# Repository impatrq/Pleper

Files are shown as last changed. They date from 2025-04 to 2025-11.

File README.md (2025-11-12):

<div align="center">

# Proyecto PLEPER
## Placa de Energía Piezoeléctrica Renovable 
<div align="center">
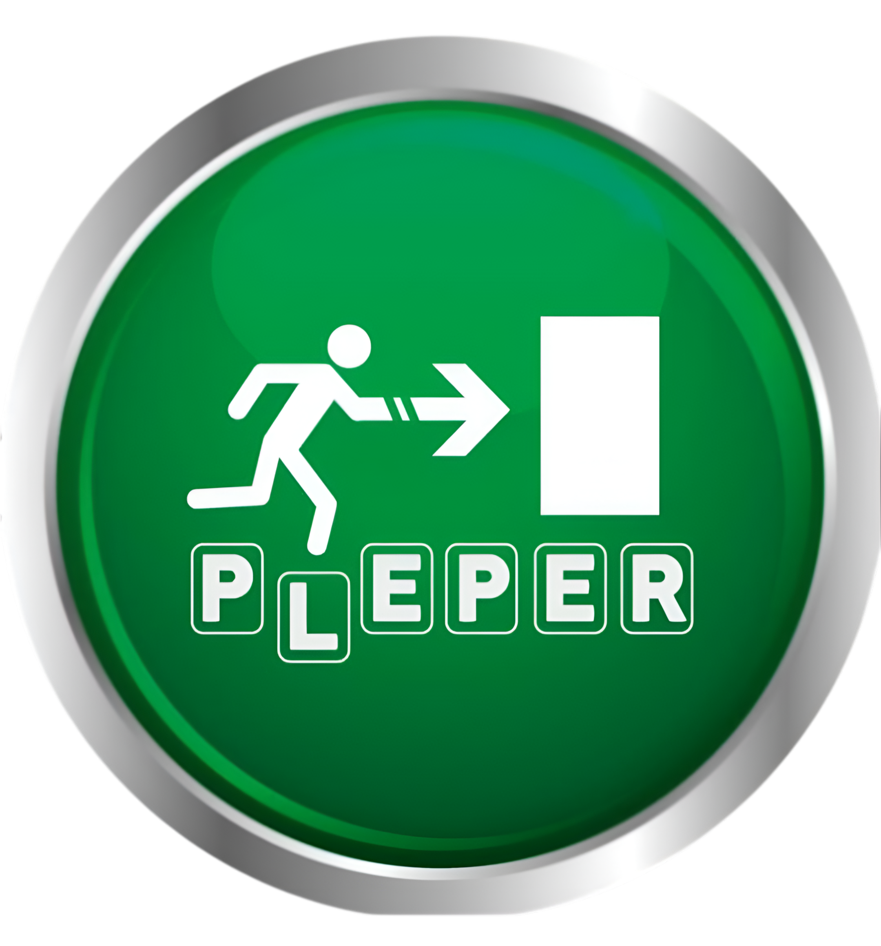
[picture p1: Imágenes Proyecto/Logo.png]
Logo Proyecto Pleper
  
  </div>

|  |  | |
|---|---|---|
|[Página Web](https://pleper-impa.github.io/web/index.html)|pleper.infoimpa@gmail.com|[@pleper_25](https://www.instagram.com/pleper_25/?igsh=Y2xkMGg4Z2V1NHdl#)|

</div>

## ⚡ Energía en cada paso.

&nbsp;&nbsp;&nbsp;&nbsp;&nbsp;&nbsp;PLEPER es un sistema que busca aprovechar la energía mecánica generada por el paso de las personas sobre una baldosa piezoeléctrica para convertirla en energía eléctrica. Este sistema se destina a la alimentación de una luz de emergencia LED, enfocándose en su aplicación en los subtes de la Ciudad. Para optimizar su funcionamiento, el sistema cuenta con un microcontrolador que supervisa la energía generada y la muestra en una pantalla LCD, brindando información en tiempo real sobre su rendimiento.

&nbsp;&nbsp;&nbsp;&nbsp;&nbsp;&nbsp;Este proyecto busca demostrar la viabilidad de la energía piezoeléctrica, aunque el prototipo inicial se centra en aplicaciones pequeñas, la tecnología podría escalarse para aprovechar el tráfico peatonal y vehicular en entornos urbanos.

## 💡 ¿Qué aporta a la sociedad?
&nbsp;&nbsp;&nbsp;&nbsp;&nbsp;&nbsp;El mayor impacto que busca generar nuestro proyecto es el de incorporar, de manera inocua, métodos de generación de energía renovables al día a día de las personas, interactúando con la generación de energía y siendo a su vez más conscientes de las problematicas ambientales que conllevan los métodos tradiconales de generación de energía. <br>

## 🔧 Características Principales

- **Generación de Energía Limpia**: Convierte la energía mecánica del movimiento en electricidad utilizable.
- **Aplicaciones Versátiles**: Puede integrarse en pisos de estaciones de tren, centros comerciales, aeropuertos y rutas de alta circulación.
- **Bajo Impacto Ambiental**: No requiere combustibles fósiles.
- **Escalabilidad**: Diseño adaptable para aumentar la eficiencia con múltiples módulos piezoeléctricos en serie o paralelo.

## 🏙️ Aplicaciones

- **Espacios públicos**: Calles y veredas con alto tráfico peatonal.
- **Transporte**: Integración en rutas para aprovechar la presión de los vehículos.
- **Edificios Inteligentes**: Estaciones de transporte y centros comerciales.
- **Eventos Masivos**: Estadios y conciertos donde miles de personas generan energía con sus movimientos.

## 🛠️ Tecnología Utilizada

- **Componentes Principales**:
  - Sensor piezoeléctrico
  - Circuito rectificador
  - Almacenamiento en condensadores
  - Microcontrolador para medición de energía generada
  
- **Software**:
  - Diseño de placa en AutoCad
  - Simulaciones en software de circuitos

## Integrantes:
<div align="center">
  Logo Proyecto Pleper
</div>

### Victoria Josefina Baza

<a href="https://mail.google.com/mail/?view=cm&to=victoriajosefinabaza@gmail.com" target="_blank">
  
</a>
<a href="https://www.linkedin.com/in/victoriajbaza/">
  
</a>
<a href="https://github.com/VickyyyBaza">
  
</a>
<a href="https://www.instagram.com/lavicky_victoria/">
  
</a>

<br><br>

### Mauricio Blasco
<a href="https://mail.google.com/mail/?view=cm&to=sirmauriciob@gmail.com" target="_blank">
  
</a>
<a href="https://www.linkedin.com/in/mauriciobl/">
  
</a>
<a href="https://github.com/MauricioBlasco">
  
</a>
<a href="https://www.instagram.com/maauricio.bl/">
  
</a>

<br><br>

### Víctor Raúl Broncano Ramos
<a href="https://mail.google.com/mail/?view=cm&to=raul455896@gmail.com" target="_blank">
  
</a>
<a href="https://www.linkedin.com/in/raul-broncano-3734a0357/">
  
</a>
<a href="https://www.instagram.com/raul_broncano/">
  
</a>

<br><br>

### Ignacio García Louzan
<a href="https://mail.google.com/mail/?view=cm&to=nachogarcialouzan@gmail.com" target="_blank">
  
</a>
<a href="https://www.linkedin.com/in/ignacio-garc%C3%ADa-louzan/">
  
</a>
<a href="https://github.com/iglouzan">
  
</a>
<a href="https://www.instagram.com/ignacio_1907/">
  
</a>
<br><br>

### Isidro Joaquín Stabile

<a href="https://mail.google.com/mail/?view=cm&to=isidrost@hotmail.com" target="_blank">
  
</a>
<a href="https://www.linkedin.com/in/isidro-stabile-4104a0357/">
  
</a>
<a href="https://github.com/Isidrost">
  
</a>

<br><br>
### Santiago Alejandro Tejeda
<a href="https://mail.google.com/mail/?view=cm&to=santiagotejeda36@gmail.com" target="_blank">
  
</a>
<a href="https://www.linkedin.com/in/santiago-tejeda/">
  
</a>
<a href="https://github.com/santiagoatejeda">
  
</a>
<a href="https://www.instagram.com/santiago.teje/">
  
</a>

<br><br>

## Contactanos

### Instagram: [@pleper_25](https://www.instagram.com/pleper_25/)

### Pagina web: [Visitanos!](https://pleper-impa.github.io/web/index.html)

### Mail: pleper.infoimpa@gmail.com

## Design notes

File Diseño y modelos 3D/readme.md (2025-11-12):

# Carpeta: AutoCAD

> Planos y diseños del proyecto **PLEPER 2025_721C**  
> Realizados en **AutoCAD** para el modelado y la disposición del sistema piezoeléctrico.

---

## Descripción
Aquí se desarrollan los **planos 2D y modelos 3D** del prototipo:  
- Distribución de sensores piezoeléctricos   
- Soporte mecánico y base de acrílico 
- Cables, conexiones y espacio para batería   

---

## Herramientas utilizadas
- AutoCAD 2025  
- FreeCAD (para pruebas de exportación STEP)

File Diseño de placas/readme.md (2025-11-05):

# Carpeta: Diseño de Placas

> Módulos electrónicos del proyecto

---

## Contenido
- `Banco de capacitores/` → Conjunto de capacitores conectados en paralelo para almacenamiento de energía.  
- `Diseño 3D/` → Modelado tridimensional del banco de capacitores y disposición general.  
- `Placa de bombeo capacitivo/` → Etapa encargada de incrementar el voltaje captado por los sensores.  
- `Placa rectificadora/` → Conversión de corriente alterna a continua para carga estable en la batería.

---

## Descripción
En esta carpeta se encuentran los **diseños electrónicos** fundamentales del sistema:  
- Implementación de **etapas de rectificación y bombeo capacitivo**.  
- Diseño del **banco de capacitores** encargado de almacenar la energía piezoeléctrica.  
- Integración entre módulos para alimentar el sistema de medición y visualización.  

---

## Herramientas utilizadas
- **KiCad** para diseño de PCBs.  
- **PDFGear** para visualización e impresión.
---

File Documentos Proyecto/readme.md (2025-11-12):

# Carpeta: Documentos del Proyecto

> Archivos y registros del proyecto  
> Incluye documentación técnica, bitácoras, materiales de referencia y presentaciones finales.

---

## Contenido
- `Anteproyecto, Objetivos e Historias de Usuario` → Primeros documentos técnicos que buscaban guíar hacía donde iría el desarrollo del proyecto.  
- `Bitácora y Carpeta de Campo/` → Registro cronológico del avance mensual y tareas realizadas.  
- `CV Alumnos/` → Curriculum de los integrantes del proyecto.  
- `Carpeta Técnica y Manual de Usuario/` → Documentación técnica explicativa sobre el proyecto.  
- `Compras/` → Comprobantes, presupuestos y control de materiales adquiridos.    
- `Material/` → Referencias teóricas, papers y fuentes consultadas.  
- `Video de presentación/` → Guion, recursos y edición del video final del proyecto.  

---

## Documentos principales
- **Anteproyecto PLEPER.docx** → Documento base del proyecto: idea, objetivos y justificación.  
- **Carpeta Técnica.docx** → Desarrollo técnico, esquemas, cálculos y simulaciones.  
- **Manual de Usuario.docx** → Instrucciones de uso del prototipo, instalación y seguridad.  
---

## Herramientas utilizadas
- Microsoft Word y PowerPoint  
- Canva (diseño visual del material)  
- Google Drive para control de versiones

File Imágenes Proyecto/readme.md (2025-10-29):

# Carpeta: Imágenes del Proyecto

> Registro visual del proyecto **PLEPER 2025_721C**  
> Fotografías, capturas y material gráfico que documenta cada etapa de desarrollo.

---

## Contenido
- `Desarrollo/` → Imágenes del prototipo en construcción y pruebas de funcionamiento.  
- `Referencias/` → Material visual de apoyo, esquemas base y ejemplos consultados.  
- `Simulación de Circuitos/` → Capturas de simulaciones y resultados eléctricos.  
- `Instagram/` → Contenido audiovisual editado para difusión del proyecto.  

---

## Descripción
Esta carpeta concentra todo el **material gráfico y visual** del proyecto, utilizado tanto para documentación técnica como para difusión.  
Incluye:
- Fotos del armado y conexión de placas 
- Resultados de simulaciones y ensayos eléctricos 
- Imágenes promocionales y contenido para redes  

---

## Herramientas utilizadas
- **Canva** → Edición de imágenes y videos.  
- **Proteus** → Capturas de simulaciones de circuitos.

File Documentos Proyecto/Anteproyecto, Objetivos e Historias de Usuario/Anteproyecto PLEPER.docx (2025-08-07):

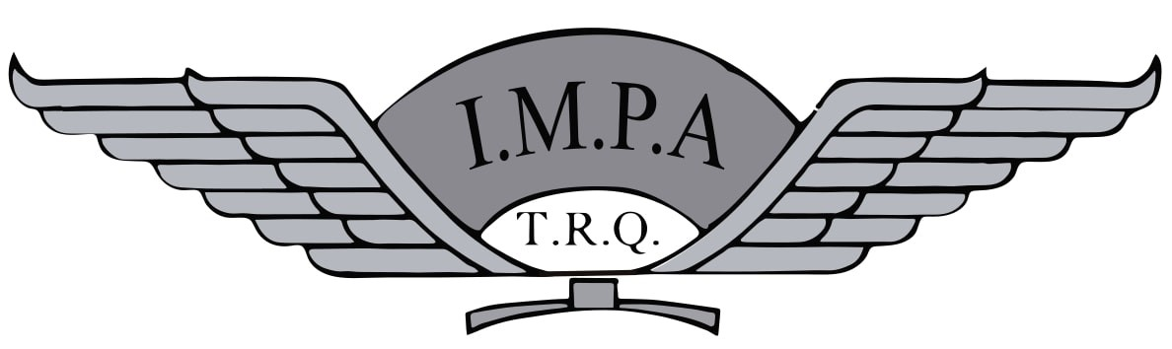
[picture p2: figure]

Escuela de Educación Secundaria Técnica Nº 7

«Taller Regional Quilmes»

Prácticas Profesionalizantes: Departamento de Aviónica

# Presentación de anteproyecto

7mo 1era AVC

“PL.E.PE.R”

Placa de Energía Piezoeléctrica Renovable

Integrantes del grupo:

BAZA, Victoria Josefina

BLASCO, Mauricio

BRONCANO RAMOS, Víctor Raúl

GARCÍA LOUZAN, Ignacio

STABILE, Isidro Joaquín

TEJEDA, Santiago Alejandro

Título del proyecto:

El nombre elegido para el proyecto fue el de Placa de Energía Piezoeléctrica Renovable por ser una descripción de lo que queremos lograr desarrollar. Abreviándolo se identifica como PL.E.PE.R

Resumen:

El proyecto que se propone busca presentar un método innovador de generación de energía eléctrica que aprovecha el movimiento humano como fuente principal de energía, utilizando la tecnología piezoeléctrica, en contextos de aplicación urbanos, como lo es una estación de subte. Se apunta a demostrar su funcionabilidad en los sistemas de iluminación de emergencia, pretendiendo poder funcionar en contexto de pérdidas de energía, solo con las pisadas de las personas.

La piezoelectricidad, que convierte la energía mecánica en eléctrica, ofrece un complemento limpio, aplicándose en entornos donde el movimiento de las personas es constante. Este enfoque no solo reduciría la dependencia de fuentes de energía no renovables, sino que también promueve la integración de tecnologías sustentables en nuestra vida diaria, sin afectarla necesariamente, de manera que seamos más conscientes como habitantes al problema ambiental que nos enfrentamos.

Introducción:

La creciente preocupación por el cambio climático y el agotamiento de los recursos fósiles ha impulsado la búsqueda de fuentes de energía más limpias y sostenibles. Las energías renovables, como la solar, eólica e hidroeléctrica, han emergido como alternativas viables, ofreciendo beneficios ambientales al reducir las emisiones de gases de efecto invernadero y mitigar la contaminación atmosférica. Sin embargo, estas no proporcionan energía constante debido a su dependencia en las condiciones climáticas, demostrando la necesidad de diversificar las fuentes y mejorar los sistemas existentes.

Sin embargo, el movimiento humano, abundante en ciudades densamente pobladas, posee una cantidad abundante de energía residual que se puede aprovechar. Para este aprovechamiento se deben desarrollar tecnologías de recolección capaces de recopilar el potencial del movimiento humano y una de estas tecnologías es el Piezoeléctrico. Ésta es una propiedad de ciertos materiales, como cristales y cerámicos, que les permite generar electricidad al ser sometidos a presión mecánica mediante las vibraciones. Aplicaciones de la piezoelectricidad van desde encendedores de cocina hasta su uso en la medicina, como en transductores ultrasónicos (1).

La integración de tecnologías piezoeléctricas en entornos urbanos, como pavimentos que capturan la energía del tránsito peatonal, ofrece oportunidades para generar electricidad de manera sustentable. Diversos proyectos han sido llevados a cabo en distintas ciudades mundiales del primer mundo, demostrando el potencial de la piezoelectricidad en la iluminación urbana, transformando el movimiento humano en energía eléctrica y contribuyendo a la eficiencia energética de las ciudades. En Londres, en el centro comercial Westfield Stratford City, se han instalado unas 20 baldosas piezoeléctricas, siendo capaces estas de encender la mitad de la iluminación exterior del centro comercial (2). De manera similar, en Tokio, la estación de tren de Shibuya ha incorporado paneles piezoeléctricos en sus pisos, generando electricidad a partir de las pisadas de los pasajeros para alimentar los molinetes y hasta algunas pantallas LED (3).

Estas iniciativas demuestran el potencial de la piezoelectricidad para transformar el movimiento cotidiano en una fuente de energía renovable, contribuyendo a la eficiencia energética y a la sostenibilidad de las ciudades modernas. Por eso apuntamos a desarrollar esta energía y en su proceso generar concientización colectiva en una sociedad que debe proyectarse hacia un futuro más limpio, caracterizado por estas innovaciones sustentables y limpias.

El proyecto consiste en desarrollar una placa que pueda generar energía eléctrica mediante las pisadas que se ejerzan sobre esta, pensada su aplicación en entornos donde haya mucho movimiento de personas, como lo sería una estación de subte. El fin de esta placa es el de poder alimentar la batería asociada a las luces de emergencia de salida LED, las cuales se les estima una duración de emergencia de aproximadamente 3hs en caso de corte de luz, de tal manera que, aunque se corte el suministro eléctrico, mediante la piezoelectricidad, se pueda alimentar el sistema de emergencia.

Si bien el proyecto apuntaría a desarrollar una placa funcional, nosotros desarrollaremos un prototipo capaz de mostrar cuanta energía cargada posee y que se pueda probar en condiciones controladas, para así demostrar su funcionalidad. Para lograr diseñar el prototipo, se deberá desarrollar tanto la placa, es decir, todo lo que sería nuestro hardware, como los componentes eléctricos necesarios.

Descripción del funcionamiento:

El sistema comenzará con la captación de energía mecánica a través de los piezoeléctricos, los cuales estarán dispuestos en un conexionado en paralelo sobre una placa de 30 cm x 30 cm. La disposición uniforme de los piezoeléctricos permitirá distribuir las fuerzas aplicadas de manera equitativa, maximizando la eficiencia de conversión energética.

Los piezoeléctricos generan una señal de corriente alterna (CA) en respuesta a la presión ejercida sobre la placa. Para poder almacenar esta energía, es necesario rectificar la señal y convertirla en corriente continua (CC), entonces se empleará un puente de diodos que actuará como rectificador de onda completa, asegurando una conversión eficiente y minimizando la pérdida de energía. A la salida del rectificador, la señal aún puede presentar ondulaciones o ruido, por lo que se añadirá un capacitor de filtrado. Este capacitor suavizará la señal, entregando una corriente continua más estable que podrá ser utilizada en las siguientes etapas del sistema.

Dado que la corriente generada por los piezoeléctricos es relativamente baja e inconsistente, se utilizará un convertidor reductor (buck). Este circuito permitirá disminuir el voltaje (el cual es alto en picos) y a la vez aumentar la corriente, hasta un nivel adecuado para cargar la batería, pasando antes por una etapa de regulación la cual asegurará que la energía entregada a la batería sea de manera constante, garantizando una eficiencia óptima en el proceso de almacenamiento de energía.

El sistema contará con un microcontrolador, característica clave del prototipo, que tendrá varias funciones importantes a la hora de demostrar el correcto funcionamiento, siendo ellas:

Monitorear la energía generada; mediante un sensor de voltaje, el microcontrolador medirá la cantidad de energía almacenada en la batería y la mostrará en un display LCD. Esto permitirá visualizar en tiempo real el desempeño del sistema.

Demostrar el funcionamiento; encargándose de activar un conjunto de luces LED alimentadas por la batería. Estas luces encenderán cuando la energía acumulada alcance un umbral mínimo, evidenciando de manera práctica el aprovechamiento de la energía piezoeléctrica.

El fin del prototipo es el de ser sencillo en cuanto a la interacción con la persona que lo utilice, siendo el único requisito el de ejercer presión sobre la placa para activar la generación de energía. La batería almacenará la energía hasta que se necesite, y el usuario podrá visualizar la cantidad de energía disponible mediante el display. En caso de que la batería tenga suficiente carga, las luces LED se encenderán automáticamente, mostrando así el correcto funcionamiento del sistema.

Análisis de factibilidad:

Para lograr lo que proponemos se debe no solo desarrollar un prototipo, sino además poseer una capacidad de análisis y entendimiento sobre la generación piezoeléctrica y el origen de este efecto, conocimientos que iremos desarrollando a lo largo del desarrollo del prototipo, enfrentando las problemáticas que se nos presenten consultando e investigando.

Para poder definir bien cada parte que conformará este proyecto nos hemos basado en el diagrama en bloques presentado, el cual busca separar cada etapa y poder diferenciar para así llevar paso por paso cada tarea correspondiente.

Victoria Josefina Baza: Organización general del proyecto, recopilación y análisis de información

- Tarea a desarrollar:

Se encargará principalmente de la organización general del proyecto, colaborando en los objetivos de cada individuo. Además, deberá recolectar artículos, tesis e informes sobre el uso de placas piezoeléctricas y circuitos de conversión de energía, verificar el estado actual de algunos proyectos, realizar conclusiones útiles al desarrollo de nuestro proyecto. Resumir y comparar distintos enfoques y soluciones existentes, identificando ventajas y limitaciones de cada uno. A su vez deberá colaborar con cada miembro del grupo, prestando especial atención en los análisis matemáticos y simulaciones del circuito.

Mauricio Blasco: Análisis de la Distribución de los Piezoeléctricos y Diseño del Hardware, Simulación del circuito.

- Tarea a desarrollar:

Estudiar y definir la configuración óptima para maximizar la conversión de energía. Simular el diseño del circuito en Proteus, verificando las mediciones para luego compararlas con el prototipo creado. Crear croquis y modelos 3D de la placa, considerando la distribución uniforme de fuerzas.

- Recursos y herramientas:

Software de simulación (LTspice, Proteus). Impresora 3D y software de diseño (AutoCAD, Fusion 360).

Santiago Alejandro Tejeda: Desarrollo del Sistema de Almacenamiento de Energía y Rectificadores

- Tarea a desarrollar:

Analizar las componentes del circuito, como los puentes de diodos para convertir la señal CA en CC. Deberá evaluar alternativas en caso de ser necesarias, a su vez que diseñará el circuito de carga y protección para la batería/supercapacitor.

- Recursos y herramientas:

Sensores de voltaje y corriente, software de simulación (LTspice, Proteus).

Ignacio García Louzan: Desarrollo del Convertidor Buck y Administración de lam página web.

- Tarea a desarrollar:

Diseñar y simular un convertidor buck que disminuya la tensión y aumente la corriente hasta el nivel adecuado para la carga, considerando también el sistema regulador que irá asociado a la batería. Deberá considerar la eficiencia y minimización de pérdidas, con simuladores. También se encargará de la programación de la página de información del proyecto.

- Recursos

Entornos de desarrollo integrado de programación (Arduino, MicroPython), módulos de comunicación y sensores.

Víctor Raúl Broncano Ramos: Pruebas y Validación del Sistema

- Tarea a desarrollar:

Diseñar y montar un banco de pruebas que incluya un circuito LED de demostración para verificar la generación y almacenamiento de energía, implementando también un display LCD. Se encargará del armado integral de la placa, buscando también el diseño óptimo de la placa junto a Mauricio Blasco. Se encargarán de la ejecución de pruebas bajo condiciones controladas, recopilando los datos que serán analizados por Victoria Baza.

Isidro Joaquín Stabile: Gestión de Comunicación y Redes

- Creación y manejo de redes sociales:

Diseñar una estrategia de comunicación para dar a conocer el proyecto en redes sociales y plataformas digitales. Deberá redactar propuestas y presentaciones para posibles patrocinadores, universidades e instituciones interesadas en energías renovables.

- Herramientas: Plataformas de redes sociales, software de diseño gráfico. Acceso a bases de datos de contactos.

Costo del proyecto:

Componentes:

- Buzzers Piezoeléctricos, 50 unidades (1.300 pesos/unidad): https://articulo.mercadolibre.com.ar/MLA-1126744263-lote-5-x-buzzer-pasivo-piezoelectrico-35mm-con-cable-itytarg-_JM
- Diodos (200-500 pesos/unidad): https://articulo.mercadolibre.com.ar/MLA-1147249550-kit-x-5-diodos-schottky-sr5200-sr5150-sb5150-sr5100-sb5100-_JM
- Resistencias (200 pesos/unidad): https://articulo.mercadolibre.com.ar/MLA-911906346-pack-220-resistencias-14w-valores-diversos-arduino-nubbeo-_JM
- Transistores NPN (200-400 pesos/unidad): https://articulo.mercadolibre.com.ar/MLA-1889333384-10-x-transistor-2n3904-npn-40v-200ma-original-to-92-_JM
- Capacitores electrolíticos (600 pesos/unidad): https://articulo.mercadolibre.com.ar/MLA-1423920705-10-x-capacitor-electrolitico-1000-uf-105-25v-35v-50v-_JM
- Batería recargable 3,7V (11.000 pesos): https://articulo.mercadolibre.com.ar/MLA-784738387-pila-bateria-recargable-18650-motoma-37v-alta-desc-corriente-2500-mah-reales-sin-teton-linternas-packs-zona-san-ma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
- Luminarias LED (37.000 pesos): https://www.mercadolibre.com.ar/luminaria-led-alumbrado-publico-trefi-potencia-50w-luz-fria-estructura-gris-50w/p/MLA44579323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
- Placa de cobre 30x30cm (15.000 a 20.000 pesos/unidad): https://articulo.mercadolibre.com.ar/MLA-835096199-placa-plaqueta-fenolico-30x30-simple-faz-cobre-pcb-pertinax-_JM
- Microcontrolador ESP8266 (6.400 pesos): https://www.mercadolibre.com.ar/modulo-wifi-esp8266-nodemcu-v3-lolin-con-chip-ch340g/p/MLA32957731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
- Display LCD (6000 pesos): https://articulo.mercadolibre.com.ar/MLA-1749285186-arsumo-display-lcd-16x2-i2c-verde-32-digitos-_JM
- Baldosa de cerámica (10.000-16.000 pesos/m²): https://articulo.mercadolibre.com.ar/MLA-642438357-baldosa-ceramica-azotea-roja-terrazapatio-20x20-colonial-_JM
- Foco (800 a 1000 pesos): https://articulo.mercadolibre.com.ar/MLA-1608042404-pack-x-10-lamparas-focos-ledvance-ex-osram-9w-led-_JM
- Portalámpara (9.000 pesos): https://www.mercadolibre.com.ar/portalampara-portafoco-receptaculo-recto-blanco-e27-x10/p/MLA46883997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

Costo total del proyecto: aproximadamente entre 200.000 y 250.000 pesos

Análisis de costo/beneficio:

El costo del proyecto podría ser cubierto por la Cooperadora y aportes propios, a su vez que también se pueden explorar opciones de financiamiento externo. Actualmente, la energía generada por el tránsito peatonal o vehicular se pierde, y la implementación de una placa piezoeléctrica permitiría aprovecharla de manera sostenible, diferenciándose de otras tecnologías al no requerir grandes espacios ni depender del clima.

Más allá del costo inicial, su potencial aplicación en entornos urbanos lo hace atractivo para municipios y empresas interesadas en eficiencia energética. Los costos de mantenimiento son bajos, y su uso en iluminación o sistemas auxiliares podría reducir el gasto eléctrico, ayudando a amortizar la inversión. La viabilidad del proyecto dependerá de demostrar que su impacto energético y ambiental justifica su implementación a mayor escala.

Diagrama en bloques del prototipo:

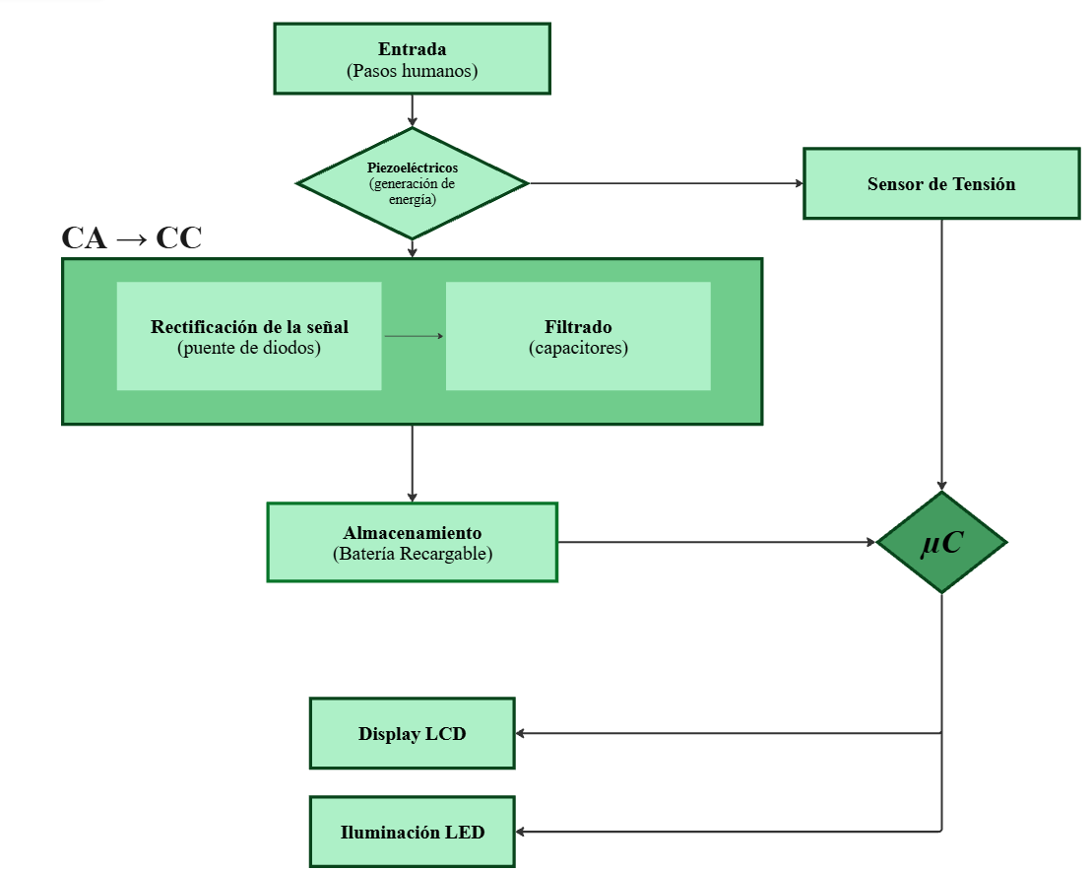
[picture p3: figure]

Piezoeléctricos: representa la disposición de los transductores piezoeléctricos en la baldosa.

Etapa CA a CC: Se compondrá primero de una rectificación mediante un puente de diodos y luego un filtrado por capacitores para suavizar la señal

Etapa de almacenamiento: Se descargará la energía generada en la batería de litio, habiendo un proceso de amplificación de tensión entre ambos bloques para aumentar al voltaje necesario para la carga.

Sensor de tensión: habrá un sensor de tensión que medirá directamente la tensión generada y se la informará al microcontrolador.

Microcontrolador de bajo consumo: Se encargará de las tareas especificadas, regular la tensión y enviarla al display LCD para que informe la tensión generada y alimentar la iluminación LED conectada al sistema.

Diagrama de tiempo de desarrollo:

El diagrama será adjuntado al envío del anteproyecto como documento Excel, sin embargo, se adjuntan capturas del mismo.

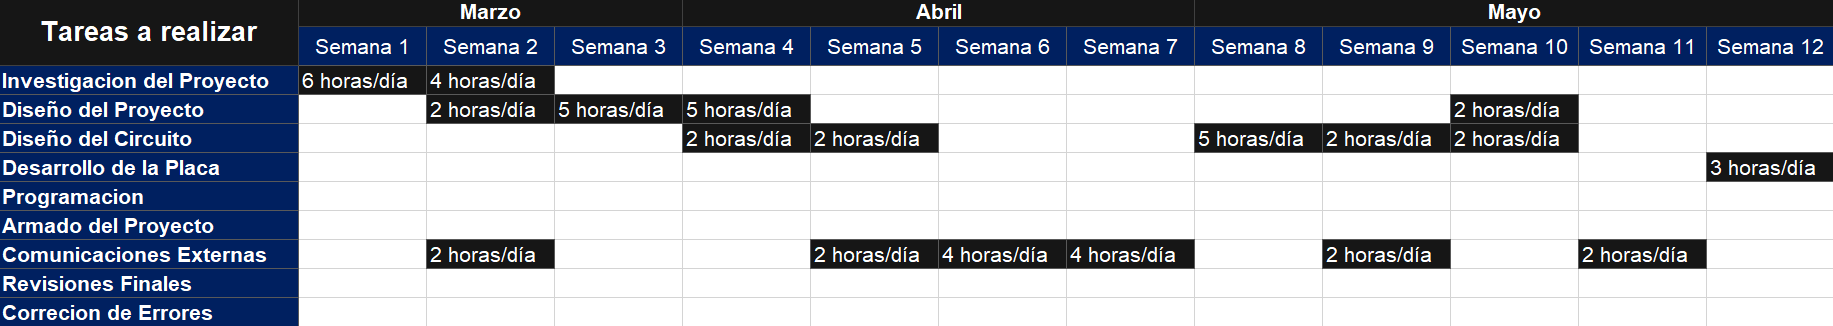
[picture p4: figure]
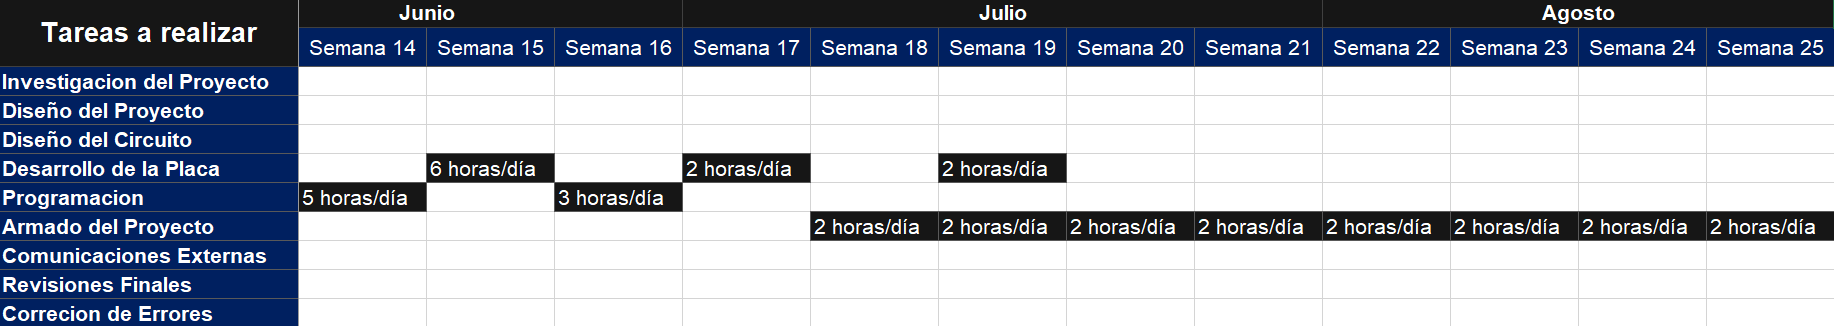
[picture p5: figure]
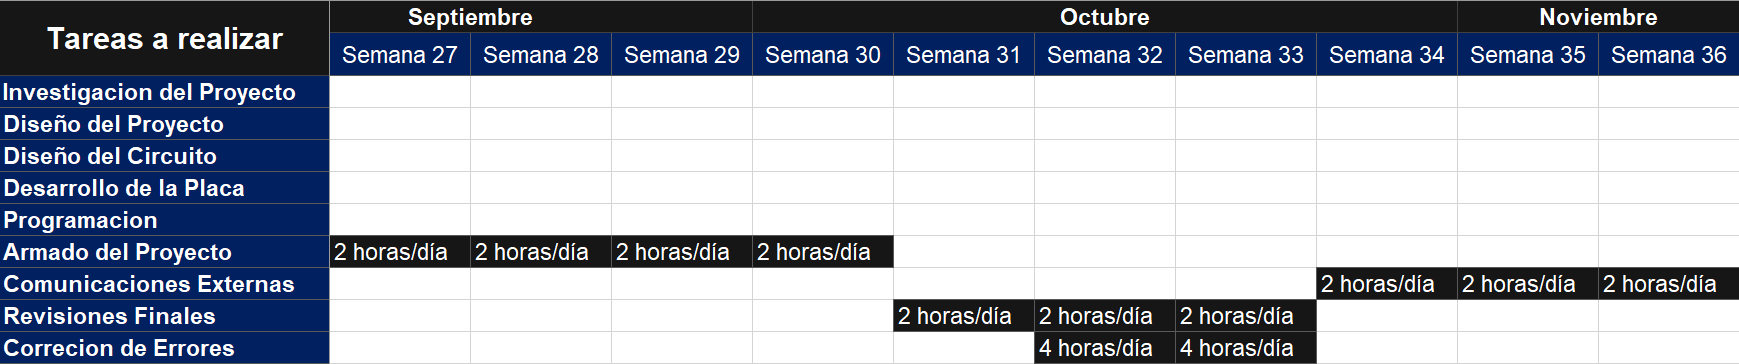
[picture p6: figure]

Referencias conceptuales:

- Transductores Piezoeléctricos aplicados a la generación de energía. Estudio Experimental. https://dspace.umh.es/bitstream/11000/8523/1/TFG-Monllor%20Mart%C3%ADnez%2C%20Pedro.pdf
- Diseño e implementación de un generador piezoeléctrico baldosa, para alimentar un sistema de iluminación de baja potencia. https://tesis.ipn.mx/jspui/bitstream/123456789/21498/1/Dise%C3%B1o%20en%20implementaci%C3%B3n%20de%20un%20generador%20piezoel%C3%A9ctrico%20baldosa%2C%20para%20alime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
- Demonstration Experiment of the “Power-Generating Floor” at Tokyo Station https://www.jreast.co.jp/e/development/press/20080111.pdf
- Piezoelectric Effect: Smart roads in green energy harvesting https://www.erpublication.org/published_paper/IJETR031337.pdf
- Proyecto de diseño de un sistema de baldosas piezoeléctricas en un gran centro comercial https://upcommons.upc.edu/bitstream/handle/2117/372449/MEMORIA-TFG2022-ERICPUNZANOdocx_fitxer%20de%20consulta.pdf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
- Desarrollo de un prototipo de baldosa generadora de energía eléctrica a partir de la piezoelectricidad y almacenamiento de la energía producida https://upcommons.upc.edu/bitstream/handle/2117/373702/tfg-menendez-adriana-arribalzaga-ainhoa.pdf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
- Materiales Piezoeléctricos: Calculo y simulación del circuito equivalente de un Cristal de Cuarzo https://www.academia.edu/26077682/Materiales_Piezoel%C3%A9ctricos_Calculo_y_simulaci%C3%B3n_del_circuito_equivalente_de_un_Cristal_de_Cuarzo
- Baldosa piezoeléctrica para alimentar sistemas de iluminación de bajo consumo energético https://repository.eia.edu.co/server/api/core/bitstreams/4256d14b-8809-4fea-865e-a865ba97cb10/content
- Diseño de un prototipo para generación energética mediante tecnología piezoeléctrica https://upcommons.upc.edu/bitstream/handle/2099/14982/Ib%C3%A1%C3%B1ez.pdf
- Caracterización de la Respuesta Piezoeléctrica de Compuestos Basados en PVDF – BaTiO3 https://e-archivo.uc3m.es/bitstream/10016/17048/1/PFC_RafaeL_Vela_Cabello.pdf
- Diseño e Implementación de un Prototipo Portable de Generación Piezoeléctrica http://scielo.senescyt.gob.ec/scielo.php?script=sci_arttext&pid=S1390-01292024000300053
- Articulo científico Proyecto de grado piezoeléctricos en perfil vial piloto en Bogotá https://es.scribd.com/document/415421008/Articulo-Cientifico-Proyecto-de-Grado-Piezoelectricos-en-Perfil-Vial-Piloto-en-Bogota
- Footstep Power Generation using Piezoelectric Plate https://www.irjmets.com/uploadedfiles/paper/issue_3_march_2022/20184/final/fin_irjmets1648274394.pdf
- Piezoelectric Footstep Power Generation https://www.ijraset.com/research-paper/footstep-power-generation-system
- Parámetros de materiales piezoeléctricos y ecuaciones piezoeléctricas https://es.piezohannas.com/Par%C3%A1metros-de-materiales-piezoel%C3%A9ctricos-y-ecuaciones-piezoel%C3%A9ctricas-1-id3912809.html
- How Does Piezoelectricity Work? https://www.americanpiezo.com/knowledge-center/piezo-theory/piezoelectricity/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,to%20form%20a%20uniform%20powder

Videos:

- No Battery Needed! - FlashLight powered by hand pressure (piezoelectric generator) https://www.youtube.com/watch?v=SlyYCbq7R-w
- Symmetry, Structure, and Tensor Properties of Materials, Piezoelectricity - Part 1 https://ocw.mit.edu/courses/3-60-symmetry-structure-and-tensor-properties-of-materials-fall-2005/resources/piezoelectricity-part-1/
- Innowattech breakthrough in alternative energy from road traffic https://www.youtube.com/watch?v=ik5-60BcMb4
- EREC006 || Foot Step Power Generation Using Piezoelectric Sensor https://www.youtube.com/watch?v=LHKmtqvBzXI
- How to make a Foot step power generation project using arduino | Full tutorial award winning project https://www.youtube.com/watch?v=YZ4OBxyyqOg
- PIEZOELECTRIC BASED FOOT STEP POWER GENERATION FOR LOW POWER APPLICATION https://www.youtube.com/watch?v=4Ew0iVbu-JQ

Referencias especificadas:

(1) https://www.repsol.com/es/energia-futuro/tecnologia-innovacion/piezoelectricidad/index.cshtml
(2) https://www.nationalgeographic.es/medio-ambiente/unas-baldosas-generan-energia-con-nuestras-pisadas
(3) https://www.wired.com/2008/12/power-generatin/

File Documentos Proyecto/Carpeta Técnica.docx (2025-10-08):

Placa de Energía Piezoeléctrica Renovable

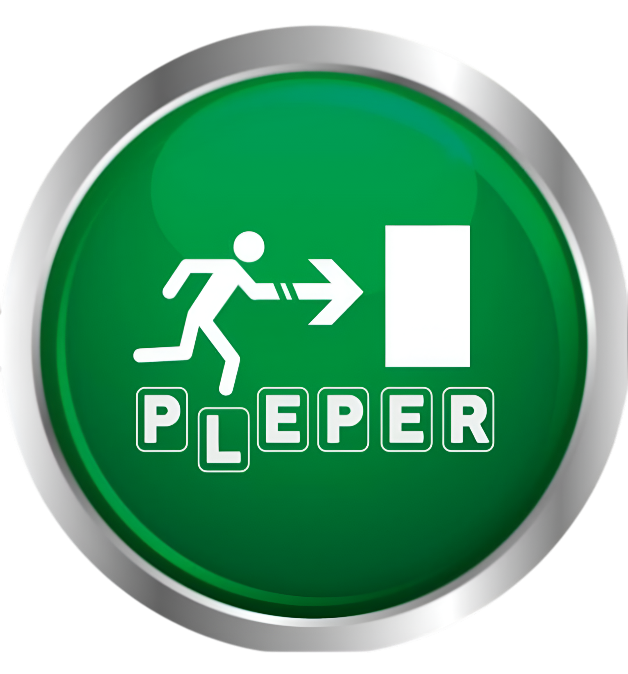
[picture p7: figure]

7° 1° Aviónica

Comisión “C”

IMPA TRQ E.E.S.T N°7 2025

# Carpeta técnica

Índice:

Introducción

PLEPER, por sus siglas “Placa de Energía Piezoeléctrica renovable” es una baldosa que permite que las personas que pasen por encima de ella generen una pequeña cantidad de energía eléctrica, permitiéndoles así colaborar con la generación de una energía autosustentable que tiene como fin almacenar suficiente carga para su aplicación en casos de emergencia, asegurando así que haya un medio de proveer luz en un corte de electricidad por un tiempo suficiente para ponerse en resguardo.

El sistema se basa en una placa que explota el fenómeno de la piezoelectricidad, aprovechando los pulsos generados por los sensores cerámicos al ser deformados mecánicamente. Su diseño de baldosa es especialmente útil para poder implementarlo en vías publicas donde hay un alto transito y se puede aprovechar mejor la generación de energía eléctrica.

Aspiramos a lograr demostrar que es posible desarrollar formas alternativas de generar energía, concientizando a las personas mediante el uso de la misma placa y haciéndolos participes del cambio.

Resumen del proyecto

El proyecto se centra en el desarrollo de una baldosa con distintas capas la cual, al presionarla, generará un pequeño pulso eléctrico que se busca aprovechar mediante el almacenamiento de esta energía. El sistema está constituido principalmente por los siguientes componentes: una baldosa de madera como base, distintas bases de caucho que sostienen 32 sensores piezoeléctricos, cuatro resortes en cada esquina, topes de goma entre los sensores piezoeléctricos y la placa de madera que esta encima, una baldosa de caucho como superficie para pisar, un modulo de almacenamiento con 4 capacitores de 10uF, un microcontrolador y una luz de emergencia.

El funcionamiento del sistema es el siguiente: el usuario caminará por encima de la baldosa como si fuera una placa más del piso, generando presión mecánica sobre esta y luego permitiendo que vuelva a su estado original. En esta deformación mecánica, los sensores piezoeléctricos generaran un pequeño pulso que será rectificado y almacenado en varios capacitores conectadas en paralelo.

Una vez varios usuarios, o el mismo haciendo distintas pasadas, pisen la placa, esta energía almacenada será distribuida por un microcontrolador, el cual la utilizará para alimentar un cartel de emergencia, simulando una situación donde la energía eléctrica se fuera en una estación de Subte, un lugar muy concurrido que, al pasar muchas personas, lograría almacenar una buena carga para alimentar el cartel de emergencia, pudiéndose aprovechar.

Motivación

Como estudiantes de séptimo año, buscamos desarrollar un proyecto con el fin de cumplir con el requerimiento horario de practicas profesionalizantes. Nuestra intención inicial fue desarrollar algo relacionado a energías alternativas, en vista del creciente interés por el desarrollo de energías renovables con el fin de apaciguar las consecuencias experimentadas por el cambio climático. Bajo este marco, y en búsqueda de alternativas no tan exploradas aún, decidimos tomar como base de nuestro proyecto el efecto piezoeléctrico, no tan visibilizado. Creemos que este proyecto tiene el potencial de concientizar a más personas sobre la necesidad de buscar alternativas no tan destructivas a nuestro ecosistema, visibilizando un fenómeno que, si bien se ha explorado en algunas partes del mundo, poca gente conoce su existencia y potencial.

Objetivos

El objetivo de nuestro proyecto es el de lograr generar energía utilizando como fuente principal proveedora la deformación mecánica que generan las pisadas y ser capaces de almacenarla y aprovecharla para alimentar un LED que sirva como luminaria de emergencia, pudiendo generar energía de una forma no convencional en casos dee emergencia.

¿Quiénes Somos?

Somos el grupo PLEPER (Placa de Energía Piezoelectrica Renovable), conformado por seis estudiantes de la especialidad de Aviónica del séptimo año, primera división, comisión C, de la Escuela Técnica N°7 IMPA “Taller Regional Quilmes”.

…

Desarrollo del Proyecto

A continuación, se expondrá la metodología empleada para avanzar en el desarrollo del proyecto, incluyendo las fuentes de inspiración y los proyectos similares que se han tomado como inspiración en el diseño del sistema.

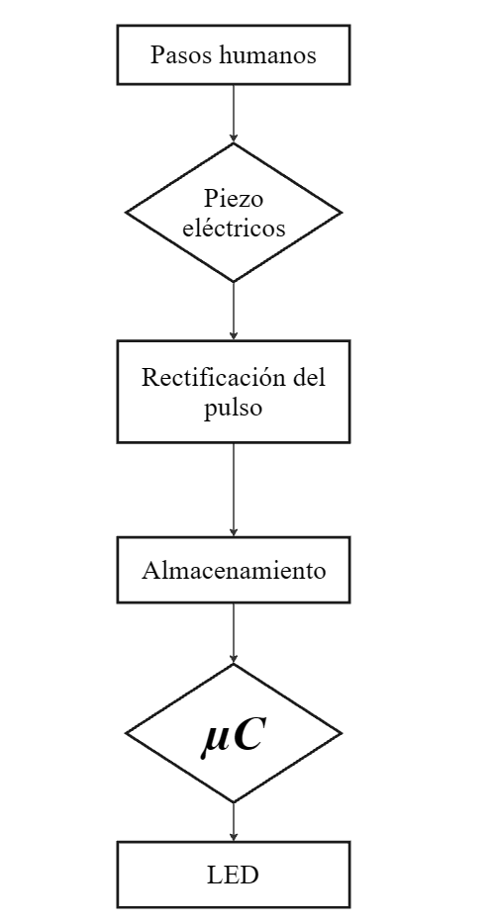
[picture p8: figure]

3.1 Estado del arte

3.1.1 Pavegen

Uno de los referentes que analizamos para la conceptualización del proyecto fue Pavegen, una empresa británica dedicada al desarrollo de baldosas inteligentes capaces de transformar la energía de las pisadas humanas en electricidad utilizable. Estas baldosas funcionan mediante un sistema de inducción electromagnética y movimiento mecánico, generando pequeñas cantidades de energía cada vez que una persona las pisa.

El objetivo principal de esta tecnología es aprovechar el tránsito peatonal en espacios públicos para alimentar sistemas de bajo consumo, como luminarias LED, pantallas interactivas o sensores de monitoreo. Además, Pavegen incorpora herramientas de recolección de datos que permiten medir la cantidad de pasos y el flujo de personas en un lugar determinado, contribuyendo así al desarrollo de entornos urbanos más inteligentes y sostenibles.

Este ejemplo fue uno de los primeros que hayamos al investigar sobre aportes a la utilización de la energía piezoeléctrica, nos permitió reflexionar sobre la viabilidad de utilizar la energía cinética como fuente renovable aplicada a la vida cotidiana. Si bien nuestro proyecto no busca replicar la complejidad de Pavegen, nos resultó relevante como antecedente que demuestra cómo la energía generada por el movimiento humano puede almacenarse y aprovecharse de manera innovadora.

3.1.2 Subtes en Tokio

Otro caso que analizamos fue el de los sistemas de transporte en Tokio, donde se han implementado tecnologías piezoeléctricas en estaciones de metro con el objetivo de generar energía a partir del tránsito masivo de pasajeros. Estas instalaciones utilizan baldosas especiales que convierten la presión de las pisadas en electricidad, la cual luego se emplea para alimentar iluminación de bajo consumo, paneles informativos y otros dispositivos dentro de las estaciones.

El contexto japonés resulta particularmente interesante debido al alto caudal de personas que circula diariamente por el metro de Tokio, lo que permite obtener un volumen considerable de energía renovable a partir de una acción cotidiana como caminar. Además, estas iniciativas se enmarcan dentro de las políticas de sostenibilidad y eficiencia energética que caracterizan a muchas ciudades japonesas, donde la innovación tecnológica se aplica directamente a la vida urbana.

Este ejemplo nos permitió comprender cómo la energía piezoeléctrica puede ser aplicada a gran escala en espacios públicos con alto flujo de usuarios. Si bien nuestro proyecto no busca alcanzar esa magnitud, consideramos valiosa esta experiencia como inspiración para adaptar la misma lógica en un prototipo más reducido y demostrativo.

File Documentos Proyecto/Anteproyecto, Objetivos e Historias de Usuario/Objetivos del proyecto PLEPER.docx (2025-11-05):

Objetivos del proyecto PLEPER

Conseguir 3 sponsors para impulsar el proyecto.

Lograr presentarse en las competencias ONIET y conseguir como mínimo una medalla de bronce.

Poder cumplir con todos los objetivos buscados para antes de la feria de ciencias.

Lograr un stand llamativo para que la gente se interese en nuestro proyecto.

Contactar con diferentes empresas que tengan información para brindarnos en nuestros intereses.

Concientizar a la gente sobre las energías renovables y su importancia en la actualidad.

Aparecer en algún medio de comunicación ya sea de video o audio.

Aprender a funcionar y trabajar correctamente como equipo.

Aprender a comunicarse formalmente con los representantes de las empresas con las que trabajamos.

Impulsar nuestro perfil profesional por medio del proyecto.

Lograr conseguir una cuenta de Instagram informativa y profesional.

Aprender a administrar nuestros tiempos de manera adecuada.

Aprender a administrar nuestros recursos de manera eficaz.

Abrirnos puertas para una futura universidad o un futuro empleo.

Traer las energías piezoeléctricas como opciones viables en argentina.

Inspirar a las siguientes generaciones a buscar soluciones para los problemas ambientales.

Lograr un avance tanto personal como técnico en los integrantes del grupo, aprendiendo de nuestra experiencia.

Lograr provocar un interés en la gente que vea nuestro proyecto.

Dejar en alto el nombre de la institución demostrando la capacidad de los estudiantes del colegio.

Demostrar que proyectos escolares pueden tener un impacto real.

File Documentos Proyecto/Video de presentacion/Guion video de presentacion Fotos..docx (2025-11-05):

Introducción

Nosotros somos Pleper, un proyecto hecho por alumnos de séptimo año de la escuela de educación secundaria número 7 “IMPA”, de la especialidad aviónica. Durante los días hábiles hay un promedio de 750.000 pasajeros utilizando el sistema de subtes en la ciudad autónoma de Bueno Aires, número que significa grandes masas de gente produciendo energía mecánica que está siendo desaprovechada. En busca de una solución para esta problemática, es que nosotros creamos PLEPER. Nosotros aprovechamos por medio de la piezoelectricidad ese movimiento transformándolo en energía sacando el máximo provecho a las grandes masas de gente para mantener cargados los carteles de emergencia en las estaciones.

¿Por qué se utilizaría?

Los carteles de emergencias deben estar colocados en cada salida de forma obligatoria colocados a simple vistas para ser reconocidas rápidamente con el objetivo de lograr reducir al máximo la posibilidad de riesgo, por lo que en lugares sin luz natural como las estaciones de subte se debe tener un sistema de iluminación autónomo que los mantenga encendidos incluso en el caso de que se produzca un corte de luz. Pleper se crea como una forma de mantener cargados los carteles de salida para evitar problemas como la descarga con el tiempo de estos mismos, ayudando a reducir el riesgo y funcionando como una alternativa limpia y renovable de aprovechar al máximo la energía generada por las personas.

Explicación piezoelectricidad

¿Cómo funciona la baldosa?

El proceso lo podríamos dividir en cuatro secciones principales:

- Estructura: La baldosa esta conformada por una base de madera sobre la cual se apoyan 8 grupos de 4 piezoeléctricos colocados en paralelo. Estos piezoeléctricos poseen una superficie elaborada a base de caucho bajo ellos para amortiguar los golpes y un tope de forma cubica sobre ellos para evitar el contacto directo y aprovechar lo máximo posible cada pisada. En las esquinas de la base se ubican 4 resortes colocados para poder devolver baldosa a su posición original una vez pisada. A su vez estos resortes funcionan como pilares sobre los cuales se ubica una plancha de madera la cual seria la superficie en la cual el peatón caminaría. Al ser pisada, la plancha bajaría hasta deformar los piezoeléctricos los cuales generan la tensión deseada. Una vez se deja de pisar la baldosa, los resortes suben la plancha hasta regresar a su posición original.
- Rectificación: Una placa recibe los pulsos generados por los piezoeléctricos y los rectifica por medios de unos diodos schottky, uniendo también todos los pulsos a una sola salida.
- Almacenamiento: Esta única salida envía la tensión generada hacia un banco de capacitores el cual se encarga de almacenar lo generado por los piezoeléctricos.
- Display:
- Raspberry:
- Pagina web:

Outro

El cambio está al alcance de todos. Al permitir una interacción entre el usuario y la generación de energía tan estrecha, creemos que se realza la importancia de concientizar sobre nuestro rol en la lucha contra la contaminación global, estando al alcance de una pisada el aportar un grano de arena en esta lucha y siendo capaces de cambiar nuestros hábitos por un futuro mejor.

- Gente caminando
- PLEPER
- Video de energía (luces, carteles, etc)
- Vicky
- Santutu (Agregar imágenes de las placas)
- Diseño 3D facherazo de Vicky (Agregar flechas y movimientos)
- Video Baldosa Posta
- Videos de subte posta

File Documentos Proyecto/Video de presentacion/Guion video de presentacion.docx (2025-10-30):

Introducción

Nosotros somos Pleper, un proyecto hecho por alumnos de séptimo año de la escuela de educación secundaria número 7 “IMPA”, de la especialidad aviónica. Durante los días hábiles hay un promedio de 749.108 pasajeros utilizando el sistema de subtes en la ciudad autónoma de Bueno Aires, y por cada persona que pasa se está desperdiciando la oportunidad de aprovechar sus pisadas para generar energía. Nuestro proyecto busca aprovechar por medio de la piezoelectricidad ese movimiento transformándolo en energía aprovechando al máximo el tránsito para mantener cargados los carteles de emergencia en las estaciones.

¿Por qué se utilizaría?

Los carteles de salida de emergencias deben estar colocados en cada salida de forma obligatoria colocadas a simple vistas para ser reconocidas rápidamente para reducir lo máximo posible cualquier riesgo, por lo que en lugares sin luz natural como las estaciones de subte deben tener un sistema de iluminación autónomo que las mantenga encendidas incluso en un corte de luz. Pleper se crea como una forma de mantener cargados los carteles de salida para evitar problemas como la descarga con el tiempo de estos mismos, ayudando a reducir el riesgo y funcionando como una alternativa limpia y renovable de aprovechar al máximo la energía generada por las personas.

Explicación piezoelectricidad

¿Cómo funciona la baldosa?

El proceso se podría dividir en cuatro secciones principales:

- Estructura: Está formada por 8 grupos de 4 piezoeléctricos colocados en paralelo sobre una base de madera. Cada piezoeléctrico posee una base de caucho bajo el, y un tope cubico para evitar el contacto directo y aumentar la potencia. En cada esquina de la base hay cuatro resortes que permiten comprimir una placa de madera para deformar los piezoeléctricos y luego regresarla a su posición original.
- Rectificación: Una placa recibe los pulsos generados por los piezoeléctricos y los rectifica por medios de unos diodos schottky, uniendo también todos los pulsos a una sola salida.
- Almacenamiento: Esta única salida envía la tensión generada hacia un banco de capacitores el cual se encarga de almacenar lo generado por los piezoeléctricos.
- Display:

Outro

El cambio está al alcance de todos. Al permitir una interacción entre el usuario y la generación de energía tan estrecha, creemos que se realza la importancia de concientizar sobre nuestro rol en la lucha contra la contaminación global, estando al alcance de una pisada el aportar un grano de arena en esta lucha y siendo capaces de cambiar nuestros hábitos por un futuro mejor

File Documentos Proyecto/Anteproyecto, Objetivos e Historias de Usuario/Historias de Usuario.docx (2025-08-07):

Historias de Usuario

PLEPER 2025_721C

1 - - HU Objetivo Primordial

Como peatón en una ciudad inteligente,

Puedo generar energía con cada paso que doy,

Para contribuir al ahorro energético sin cambiar mis hábitos, aportando al uso de energías limpias

Criterios de aceptación:

Dado que el sistema debe generar una pequeña cantidad de energía,

Cuando la persona pase por encima, esta se debe almacenar,

Entonces implementaremos un sistema de almacenamiento eficiente

Requerimientos no funcionales:

Que sea accesible y no moleste a los peatones que pasen por encima

Debe estar ubicado en un lugar visible para fomentar su uso y concientización.

2 - - HU Experiencia de Usuario

Como persona que utiliza el sistema,

Puedo ver en una pantalla cuánta energía se generó con mi paso,

Para sentirme parte del cambio, entendiendo el impacto de mis acciones

Criterios de aceptación:

Dado que los usuarios querrán ver el resultado de su paso,

Cuando caminen sobre la placa habrá un indicador visible,

Entonces se fomentará la conciencia ambiental, de manera que pequeños aportes estimulen grandes cambios.

Requerimientos no funcionales:

Que la cifra a mostrar sea clara y rápida de entender

Que se pueda demostrar un incremento, incluso si es leve, en la acumulación.

3 - - HU Seguridad para el peatón

Como persona que transita a diario sistemas de transporte públicos,

Quiero pasar por encima sin riesgo de resbalar,

Para no comprometer mi integridad física.

Criterios de aceptación:

Dado que hay personas de todas las edades y condiciones físicas que transitan vías públicas,

Cuando caminen sobre la superficie está deberá ser antideslizante,

Entonces se evitarán accidentes o incomodidades.

Requerimientos no funcionales:

Que soporte el peso de distintas personas sin deformarse ni perder sus propiedades

Que no comprometa la seguridad de quienes lo usen

4 - - HU Diseño técnico

Como técnico encargado del mantenimiento,

Quiero hacer revisiones del funcionamiento de manera rápida y sencilla,

Para mantener en buen estado el equipo, manteniendo su funcionalidad operativa

Criterios de aceptación:

Dado que el técnico encargado requerirá un diseño accesible,

Cuando realice la revisión, encontrará que la placa permitirá el acceso individual a sus componentes,

Entonces podrá identificar y reparar fallas sin reemplazar todo el sistema.

Requerimientos no funcionales:

El diseño debe ser modular e incluir indicadores visuales que alerten sobre fallas

5 - - HU Funcionamiento urbano

Como encargado de obras públicas,

Puedo instalar el sistema fácilmente en redes de subtes,

Para implementarlo sin alterar demasiado el entorno general.

Criterios de aceptación:

Dado que el sistema deberá integrarse a la infraestructura existente,

Cuando se coloque deberá hacerse a un sistema de batería para emergencias,

Entonces se asegurará su activación automática en caso de corte de energía eléctrica.

Requerimientos no funcionales:

Que no requiera de obras excesivamente invasivas para su instalación

Que su conexión a la batería sea segura

Que funciona de forma autónoma

6 - - HU Empresa Sponsor

Como empresa dispuesta a colaborar con el proyecto,

Puedo aportar productos y apoyo al equipo de trabajo,

Para impulsar mi imagen respecto a las energías renovables y atraer posibles clientes.

Criterios de aceptación:

Dado que la empresa busca asociarse con proyectos sustentables,

Cuando se difunda el proyecto, se deberá reflejar su colaboración en el mismo,

Entonces su imagen pública se vinculará con la innovación y el compromiso ecológico.

Requerimientos no funcionales:

Incluir el logo de la empresa sponsor

Documentar la participación de la misma

7 - - HU Exposición de la placa en ferias y exposiciones

Como integrante del equipo expositor

Quiero trasladar el prototipo de manera sencilla y rápida

Para presentarlo en distintas ferias y muestras, facilitando su transporte

Criterios de aceptación

Dado que el prototipo debe ser fácilmente trasladable,

Cuando se necesite llevarlo a un evento educativo,

Entonces deberá estar diseñado para transportarse sin complicaciones ni comprometer su funcionamiento.

Requerimientos no funcionales

Que su tamaño y peso permitan trasladarlo incluso en vehículos personales

Que se pueda montar y desmontar en menos de 3 horas

8 - - HU Manejo de la Energía Generada

Como responsable del diseño funcional del prototipo

Quiero que la energía generada se almacene correctamente en una batería

Para su uso eficiente en caso de necesitarlo

Criterios de aceptación

Dado que la energía se genera de manera intermitente

Cuando una persona camine sobre la placa,

Entonces la energía será derivada y almacenada en una batería recargable lista para alimentar las luces de emergencia

Requerimientos no funcionales

Que el sistema de carga de batería sea eficiente, priorizando la estabilidad de voltaje para no dañar los dispositivos conectados.

9 - - Optimización de su uso

Como desarrollador del prototipo,

Quiero que el sistema entre en reposo de manera programada cuando el subte no esté operativo,

Para evitar el uso innecesario del microprocesador durante los horarios que no hay circulación

Criterios de aceptación

Dado que el subte tiene horarios específicos de funcionamiento,

Cuando se esté en esa franja horaria se apagará la pantalla y entrará en modo de bajo consumo,

Entonces reducirá su consumo hasta reanudarlo en horario de funcionamiento

Requerimientos no funcionales

Que el sistema cuente con una programación horaria

Que el estado de reposo no afecte sus sistemas conectados

Que se reactiva automáticamente cuando comience el horario operativo del subte.

10 - - Concientización sobre el uso de energías renovables
Como integrante del proyecto PL.E.PE.R.,
Quiero informar a jóvenes y adultos sobre los beneficios del uso de energía piezoeléctrica,
Para promover la conciencia sobre alternativas renovables frente al uso excesivo de baterías de litio.

Criterios de aceptación
Dado que muchas personas desconocen el impacto ambiental del uso de baterías convencionales,
Cuando se realicen presentaciones del proyecto en espacios educativos o públicos, se brindará información sobre su enfoque sustentable,
Entonces se fomentará un cambio de perspectiva hacia soluciones energéticas más limpias y sostenibles.

Requerimientos no funcionales
Que el contenido de concientización sea claro, breve y adaptable a distintos públicos
Que no dependa de elementos tecnológicos complejos para su transmisión
Que esté alineado con los objetivos ambientales del proyecto.

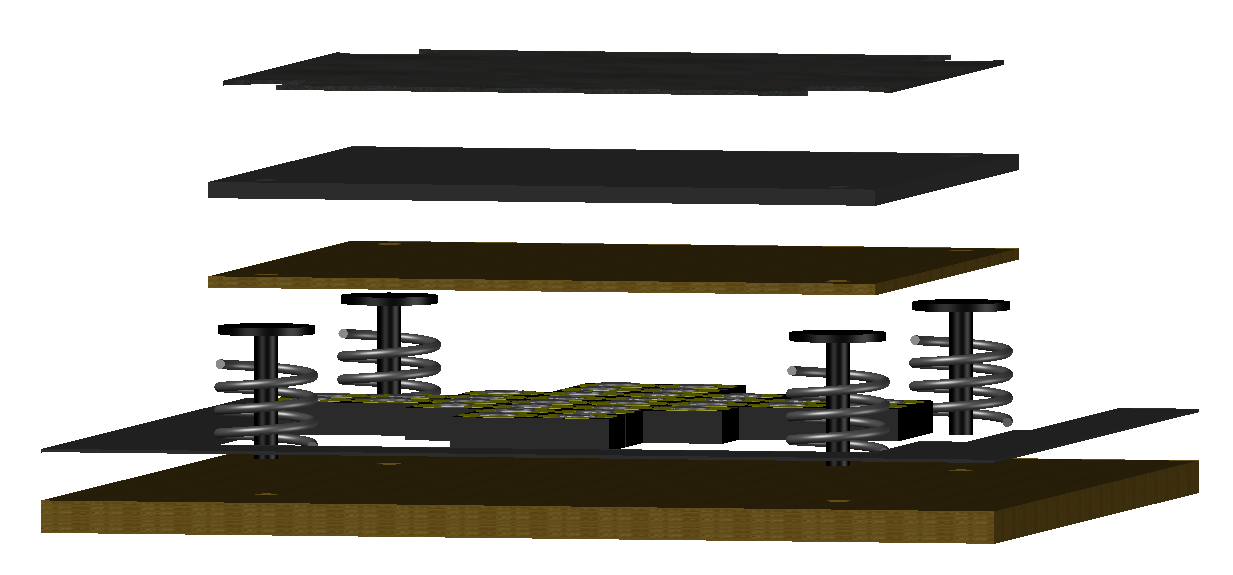
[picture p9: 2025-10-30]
Diseño y modelos 3D/Imagenes de AutoCad/Vista realista 7.png

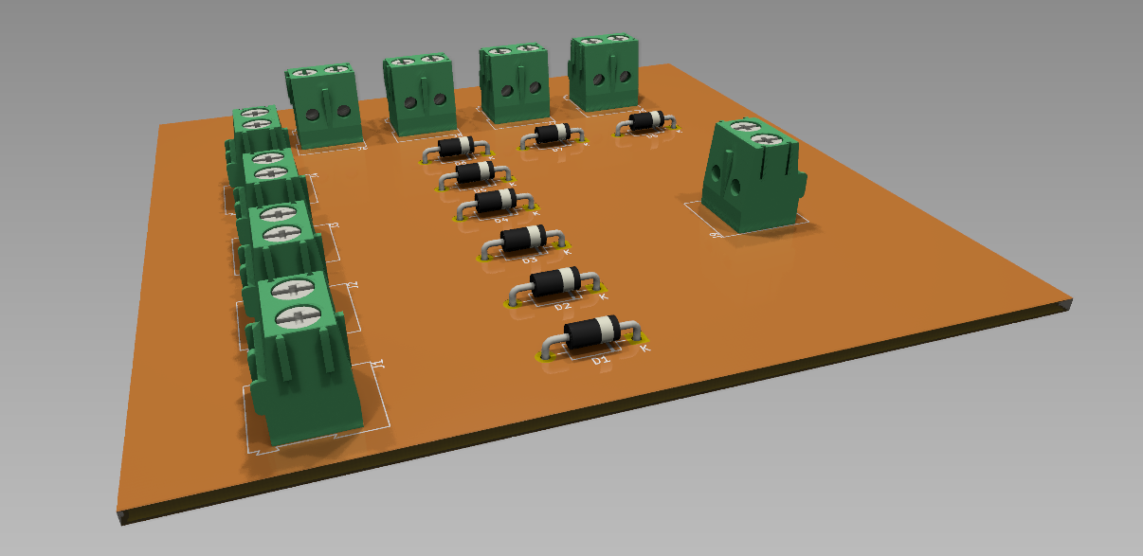
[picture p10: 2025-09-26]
Diseño de placas/Diseño 3D/Placa rectificadora Vista 1.png

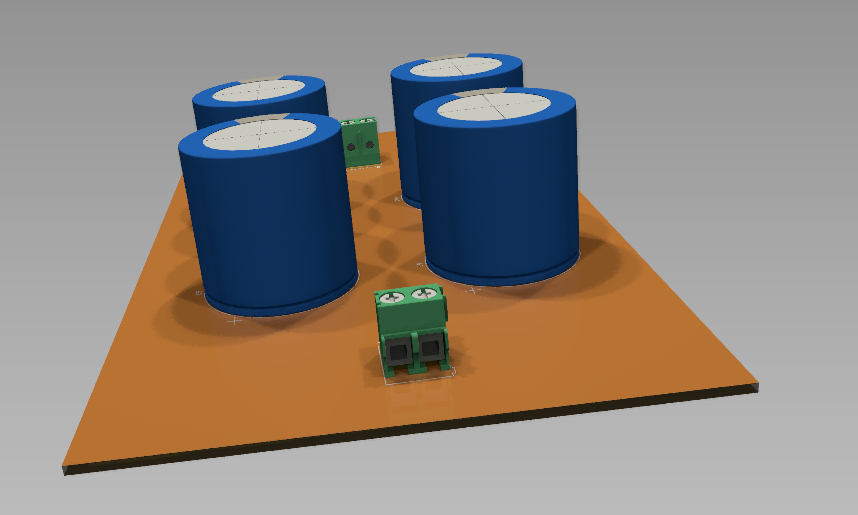
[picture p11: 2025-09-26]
Diseño de placas/Diseño 3D/Banco de Capacitores Vista 2.png

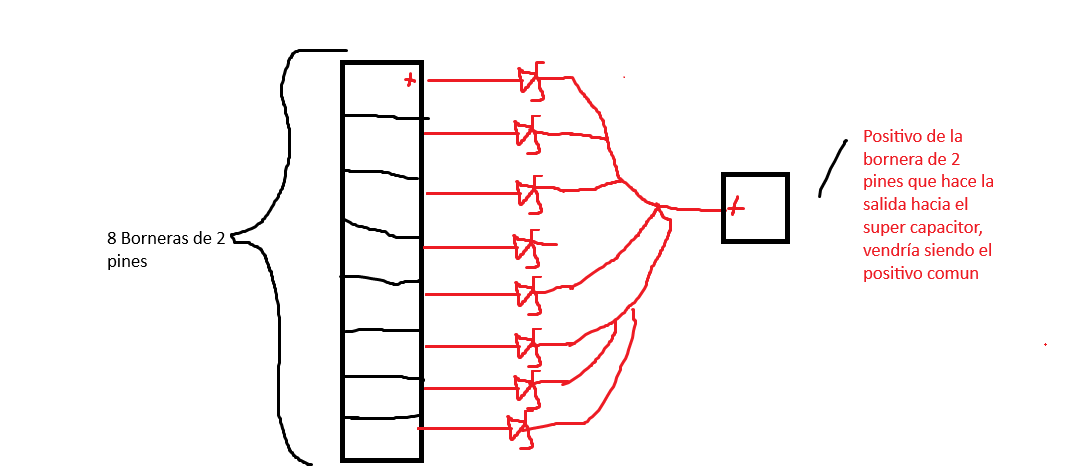
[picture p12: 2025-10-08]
Diseño de placas/Placa rectificadora/Boceto de rectificadora/rectificadora dibujo.png

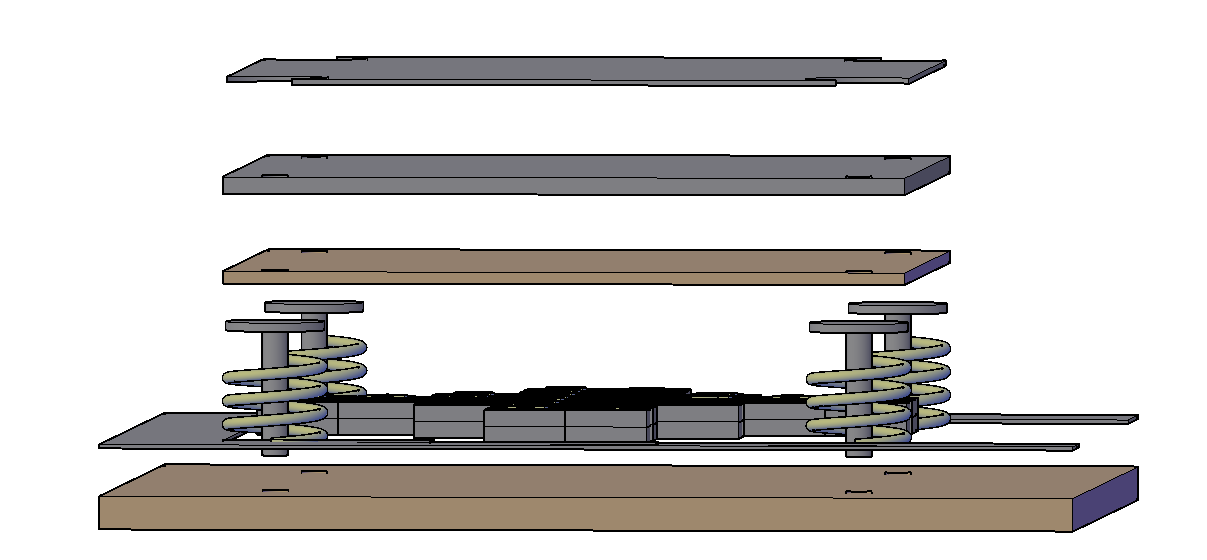
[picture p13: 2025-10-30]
Diseño y modelos 3D/Imagenes de AutoCad/Vista conceptual 2.png

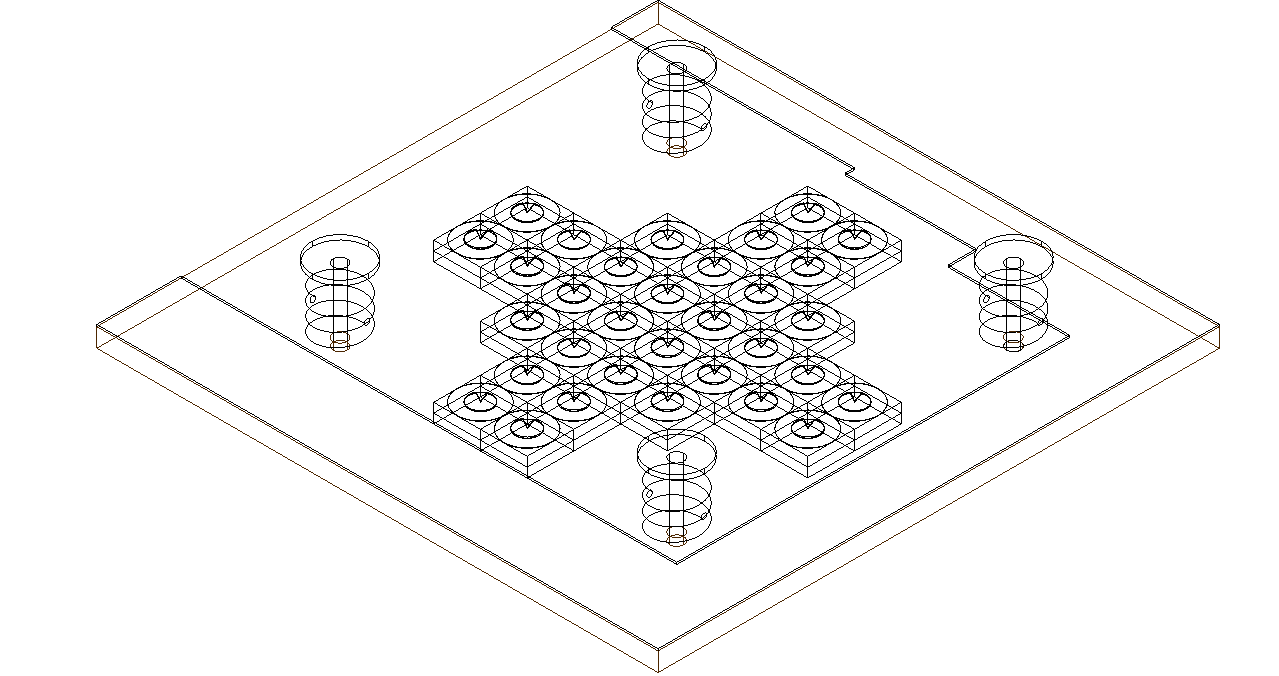
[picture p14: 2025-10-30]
Diseño y modelos 3D/Imagenes de AutoCad/Captura de pantalla 2025-10-30 134222.png

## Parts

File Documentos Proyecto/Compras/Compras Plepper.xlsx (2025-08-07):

Planilla de compras Proyectos de 7mo Aviónica
Nombre del Proyecto |  | Plepper |  | Alumnos Responsables: |  |  | AVIÓNICA
 |  |  |  | Ignacio García Louzan | nachogarcialouzan@gmail.com
 |  |  |  | Santiago Tejeda | santiagotejeda36@gmail.com
Item | Cant. | Nombre del producto | Detalle del pedido | Link: | Precio por unidad | Sub Total | Fecha de solicitud | Tutores |  | Jefe de Área |  | Cooperadora
 |  |  |  |  |  |  |  | Aprobado | Fecha de aprobación | Aprobado | Fecha de aprobación | Estado | Fecha de entrega
1 | 1 | buzzers piezoeléctricos | Se consiguen en mercado libre, en un pack y su medida es de 50 mm. Si se compra el pack te sale 99.000 pesos. | https://articulo.mercadolibre.com.ar/MLA-1467957059-50-discos-transductor-piezo-electrico-bateria-50mm-con-cable-_JM | $99999.00 | $99999.00 | 2025-05-08 16:24 | VERDADERO | 2025-05-08 16:38 | VERDADERO | 2025-05-08 16:38 | Comprado
2 | 1 | Baldosa piso de caucho | Es un piso de caucho que se utiliza comunmente para gimnasio/crossfit y sus medidas son de 60 x 60. | https://articulo.mercadolibre.com.ar/MLA-1454386459-baldosa-piso-de-caucho-alto-impacto-gimnasio-crossfit-60x60-_JM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 | $83333.00 | $83333.00 | 2025-05-08 16:30 | VERDADERO | 2025-05-08 16:38 | VERDADERO | 2025-05-08 16:38 | Comprado
3 | 3 | Tope Autoadhesivo de Goma | servirian para proteger los buzers frente a impactos muy bruscos al entrar en contacto con la baldosa y para una mayor distribucion de fuerza. | https://articulo.mercadolibre.com.ar/MLA-869808878-tope-de-goma-autoadhesivo-para-pata-muebles-30mmx3mm20unid-_JM | $3999.00 | $11997.00 | 2025-05-08 16:35 | VERDADERO | 2025-05-08 16:38 | VERDADERO | 2025-05-08 16:38 | Comprado
4 | 1 | Módulo adaptador i2c Display LCD | Se utilizaria para complementar al display LCD que ya poseemos. | https://articulo.mercadolibre.com.ar/MLA-1302486622-modulo-adaptador-i2c-display-lcd-pcf8754-serie-arduino-_JM | $3400.00 | $3400.00 | 2025-05-08 16:40
5 | 3 | Fuente step down LM7805 | Se encargaria de aumentar el amperaje y reducir el voltaje ya que trabajaria como un conversor reductor. | https://articulo.mercadolibre.com.ar/MLA-1139295283-fuente-step-down-acdc-8-24v-salida-dc-5v-12a-lm7805-hobb-_JM | $6690.00 | $20070.00 | 2025-05-08 16:44 | VERDADERO | 2025-05-08 16:46 | VERDADERO | 2025-05-08 16:46 | Comprado
6 | 1 | Módulo Adaptador I2C Display Lcd Pcf8574 | Un expansor de puertos I2C Se puede conectar el adaptador a través de cables o directamente gracias a sus pines de conexion | https://articulo.mercadolibre.com.ar/MLA-806073246-modulo-adaptador-i2c-display-lcd-pcf8574-serie-paralelo-_JM | $3344.00 | $3344.00 | 2025-08-04 13:49
7 |  |  |  |  |  | $0.00
8 |  |  |  |  |  | $0.00
9 |  |  |  |  |  | $0.00
10 |  |  |  |  |  | $0.00
11 |  |  |  |  |  | $0.00
12 |  |  |  |  |  | $0.00
13 |  |  |  |  |  | $0.00
14 |  |  |  |  |  | $0.00
15 |  |  |  |  |  | $0.00
16 |  |  |  |  |  | $0.00
17 |  |  |  |  |  | $0.00
18 |  |  |  |  |  | $0.00
19 |  |  |  |  |  | $0.00
20 |  |  |  |  |  | $0.00
21 |  |  |  |  |  | $0.00
22 |  |  |  |  |  | $0.00
23 |  |  |  |  |  | $0.00
24 |  |  |  |  |  | $0.00
25 |  |  |  |  |  | $0.00
26 |  |  |  |  |  | $0.00
27 |  |  |  |  |  | $0.00
28 |  |  |  |  |  | $0.00
29 |  |  |  |  |  | $0.00
30 |  |  |  |  |  | $0.00
 |  |  |  |  | Total: | $222143.00 |  | Gastado: | $215399.00

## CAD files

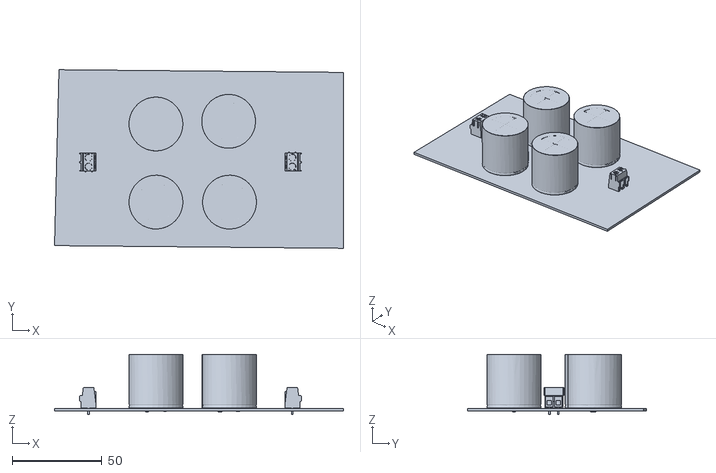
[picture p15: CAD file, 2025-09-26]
Diseño de placas/Diseño 3D/Pleper Banco de Capacitores.stl
161.0 x 99.5 x 33.6

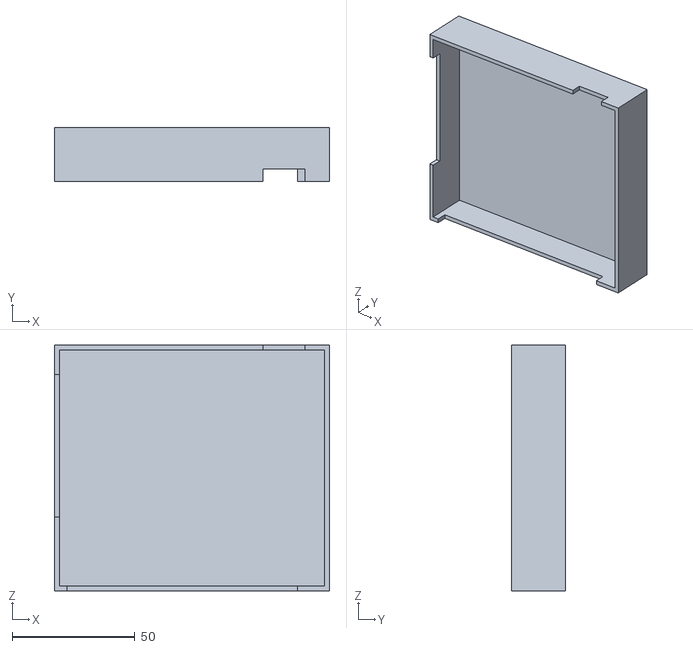
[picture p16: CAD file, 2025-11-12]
Diseño y modelos 3D/Archivos STL (Impresión 3D)/Carcasa_si.stl
112.0 x 22.0 x 100.0

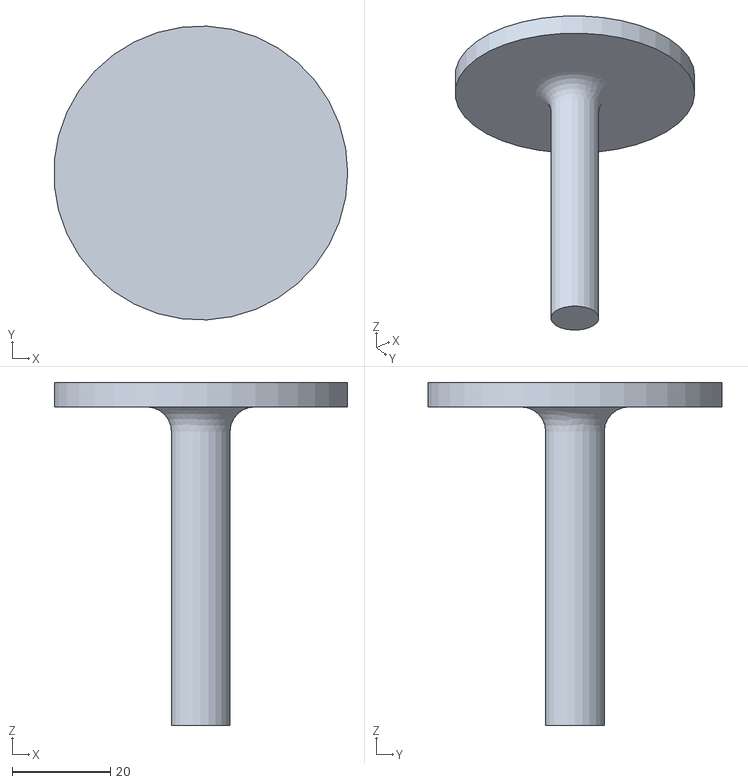
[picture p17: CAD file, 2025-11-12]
Diseño y modelos 3D/Archivos STL (Impresión 3D)/Pilar ProyectoV3.stl
59.9 x 59.9 x 70.0

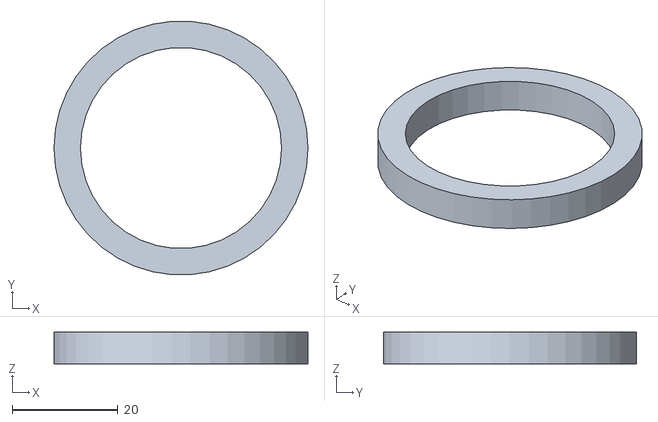
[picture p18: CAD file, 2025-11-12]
Diseño y modelos 3D/Archivos STL (Impresión 3D)/Circulo Pleper.stl
48.0 x 47.9 x 6.00

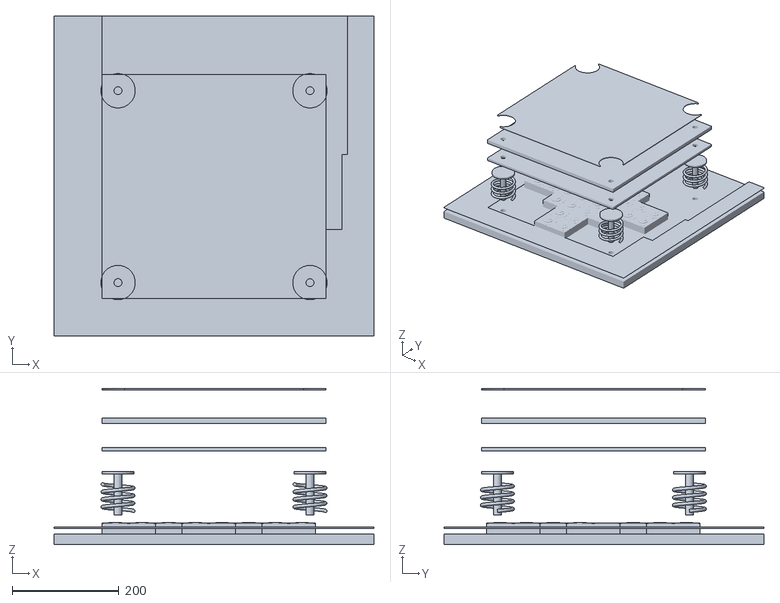
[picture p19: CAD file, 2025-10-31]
Diseño y modelos 3D/Archivos STL (Impresión 3D)/Diseño final baldosa.stl
600.0 x 600.0 x 293.3

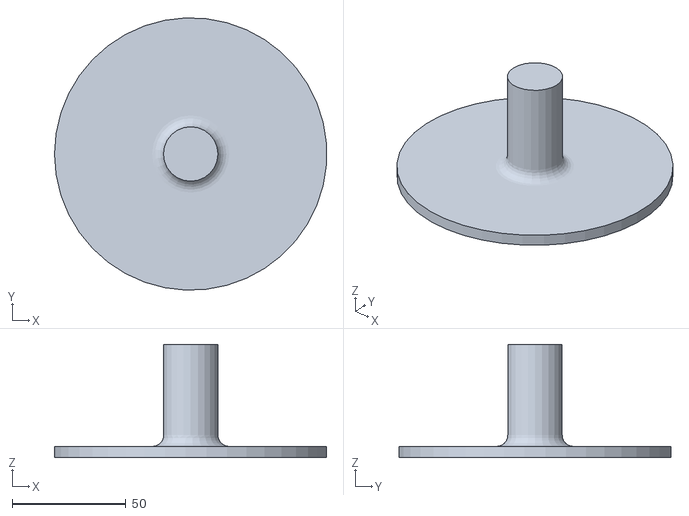
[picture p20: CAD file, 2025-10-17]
Diseño y modelos 3D/Archivos STL (Impresión 3D)/PilarPleper.stl
119.8 x 119.9 x 50.0

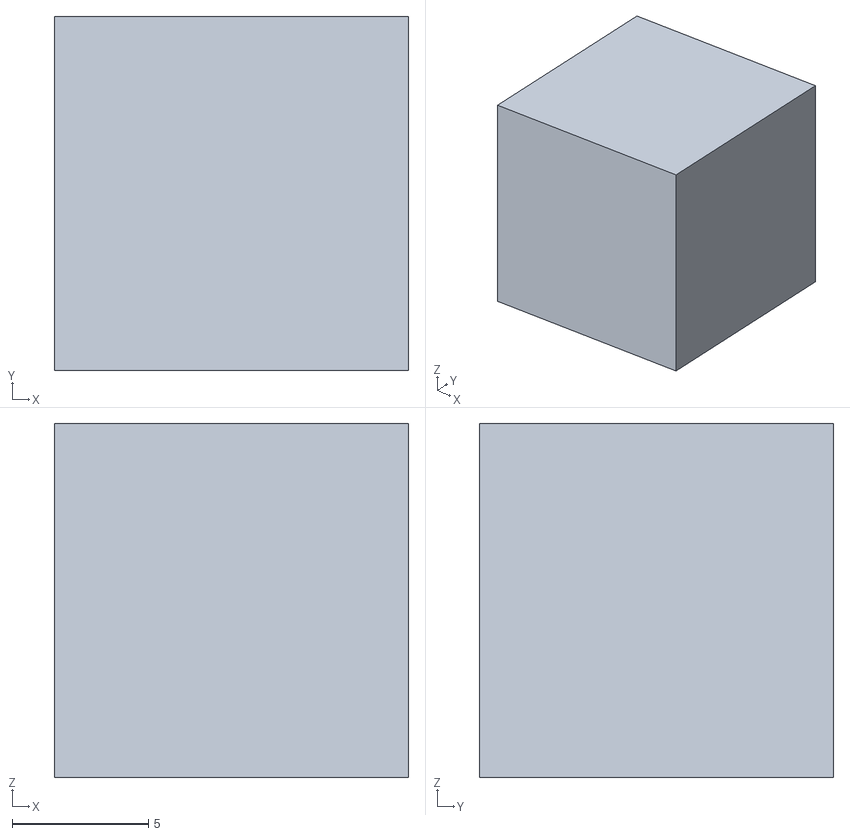
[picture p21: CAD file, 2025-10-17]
Diseño y modelos 3D/Archivos STL (Impresión 3D)/Tope_Pleper.stl
13.0 x 13.0 x 13.0

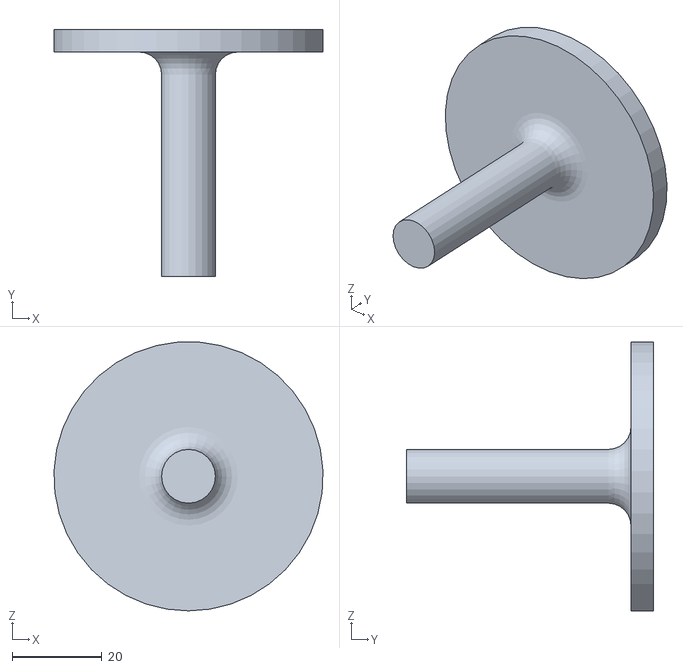
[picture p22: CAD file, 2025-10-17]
Diseño y modelos 3D/Archivos STL (Impresión 3D)/TopedePleper.stl
60.0 x 55.0 x 59.9

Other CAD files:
Diseño y modelos 3D/Archivos DWG (AutoCAD)/Caja de Placas.dwg
Diseño y modelos 3D/Archivos DWG (AutoCAD)/Circulo Tope/Circulo Pleper.dwg
Diseño y modelos 3D/Archivos DWG (AutoCAD)/Pilar Pleper Definitivo/Pilar Proyecto.dwg
Diseño y modelos 3D/Archivos DWG (AutoCAD)/Carcasini.dwg
Diseño y modelos 3D/Archivos DWG (AutoCAD)/Diseño final baldosa.dwg
Diseño y modelos 3D/Archivos DWG (AutoCAD)/Pleper segundo prototipo.dwg
Diseño y modelos 3D/Archivos DWG (AutoCAD)/Pleper primer prototipo.dwg
Diseño y modelos 3D/Archivos DWG (AutoCAD)/Topes pleper .dwg

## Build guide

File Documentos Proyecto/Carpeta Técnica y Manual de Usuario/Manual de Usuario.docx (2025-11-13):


Placa de Energía Piezoeléctrica Renovable

# Manual de usuario

7° 1° Aviónica

Comisión “C”

IMPA TRQ E.E.S.T N°7 2025

# 1. Introducción

PL.E.PE.R es un prototipo diseñado para demostrar la generación de energía renovable a partir de la presión ejercida por el paso de personas. Utiliza sensores piezoeléctricos capaces de transformar la energía mecánica producida al caminar en energía eléctrica, que luego es almacenada en una batería.
El proyecto surge con el objetivo de aprovechar el tránsito cotidiano en espacios públicos, como estaciones de subte, para producir energía limpia y sustentable. Como objetivo mayor, busca concientizar sobre el potencial de la piezoelectricidad como fuente alternativa en entornos urbanos.

## 1.1. Por qué elegir PL.E.PE.R

PL.E.PE.R representa una propuesta innovadora dentro del campo de las energías renovables.
A diferencia de otras fuentes, como la solar o eólica, este sistema no depende de condiciones ambientales, sino de la actividad humana. Su funcionamiento silencioso, su tamaño compacto y su bajo mantenimiento lo hacen ideal para entornos donde el flujo de personas es constante.

Entre sus principales ventajas se destacan:

- Sustentabilidad: convierte movimiento humano en energía eléctrica.
- Autonomía: funciona sin necesidad de fuentes externas de energía.
- Seguridad y comodidad: no interfiere con el tránsito ni requiere interacción directa.
- Aplicabilidad: puede integrarse en pisos de estaciones, pasillos o entradas de edificios públicos.

## 1.2. Aplicación

El sistema está pensado para su implementación en estaciones de subte y otros espacios de alto tránsito peatonal.

Cada paso sobre la superficie de PL.E.PE.R genera una pequeña cantidad de energía eléctrica que, sumada al flujo constante de personas, permite alimentar sistemas de baja potencia, como luces de emergencia, indicadores o pantallas informativas.

En su versión de laboratorio, el prototipo permite visualizar el proceso de conversión y almacenamiento de energía mediante un display LCD, lo que lo convierte también en una herramienta interactiva y útil para la difusión en el ámbito ambiental.

# 1. Descripción del sistema

PL.E.PE.R está compuesto por una estructura mecánica y un conjunto de componentes electrónicos diseñados para optimizar la conversión piezoeléctrica.

- Sensores piezoeléctricos: 32 unidades de 50 mm distribuidas en dos zonas: 16 en el bloque central y 16 en los laterales, organizados en grupos de cuatro.
- Sistema de soporte: la placa cuenta con una base de madera, topes de goma para distribuir el peso y piezas de impresión 3D que permiten una leve deformación sin dañar los sensores. Cuatro resortes en las esquinas facilitan el retorno de la placa a su posición original.
- Aislamiento: cada sensor está montado sobre dos cuadrados de caucho unidos, lo que los separa de la base y mejora la eficiencia al absorber el impacto.
- Placa de rectificación: recibe la señal de los sensores y convierte la corriente alterna en corriente continua.
- Placa de almacenamiento: incorpora un capacitor de 10 000 µF y una batería Li-Po de 3,7 V, donde se acumula la energía generada.
- Display LCD con Raspberry Pi: muestra el porcentaje de carga y la tensión acumulada de la batería, permitiendo monitorear el rendimiento del sistema en tiempo real.

## 2.1. Visualización de datos

PL.E.PE.R no requiere intervención directa por parte del usuario. Su funcionamiento es totalmente autónomo: basta con caminar o pararse sobre la placa para que los sensores piezoeléctricos generen energía.
El único elemento visible de interacción es el display LCD, conectado a una Raspberry Pi, que muestra en tiempo real: el porcentaje de carga de la batería Li-Po y la tensión acumulada en el sistema. De esta forma, el usuario o el observador puede visualizar el efecto inmediato del paso de las personas sobre la generación de energía, sin necesidad de realizar ninguna acción adicional.

# 2. Instalación

La instalación de la baldosa debe realizarse en una superficie plana, firme y seca, preferentemente en un entorno interior o protegido. La instalación del sistema no requiere herramientas especializadas, pero sí debe realizarse con cuidado para garantizar su correcto funcionamiento.

A continuación, se describen los pasos generales para su colocación:

1. Preparación del área de instalación

- Limpiar el área de polvo o humedad.
- Verificar que el suelo sea estable y no presente irregularidades.
- Asegurarse de disponer de espacio libre alrededor para evitar golpes o tropiezos.

2. Colocación de la base

- Ubicar la base de madera del sistema en el lugar deseado.
- Comprobar que los resortes de las esquinas estén correctamente apoyados y que la placa tenga libertad de movimiento vertical.
- Revisar que los topes de goma estén bien posicionados para una distribución uniforme del peso.
- Ajustar los 4 topes de cada esquina para que estén correctamente insertados.

3. Conexiones eléctricas

- Conectar la placa de rectificación a la placa de almacenamiento, siguiendo la polaridad indicada.
- Asegurar la conexión del capacitor de 10 000 µF y de la batería Li-Po de 3,7 V según el esquema de montaje del proyecto.
- Conectar el display LCD a la Raspberry Pi y verificar que la alimentación esté correctamente establecida.

4. Verificación de funcionamiento

- Una vez instalado, aplicar una leve presión sobre la superficie para comprobar que las caras de la baldosa están correctamente insertadas y ajustadas.
- Observar que los valores en pantalla varíen al aplicar peso sobre la placa.

5. Ubicación final

- En una aplicación real (como un pasillo o andén), se recomienda que PL.E.PE.R quede nivelado con el suelo o montado dentro de un marco protector que impida desplazamientos laterales.
- El display puede colocarse en una zona visible, protegida por una cubierta transparente.

# 3. Esquemas de la baldosa

A continuación, se adjuntan esquemas del modelo de la baldosa para poder visualizar mejor sus medidas.

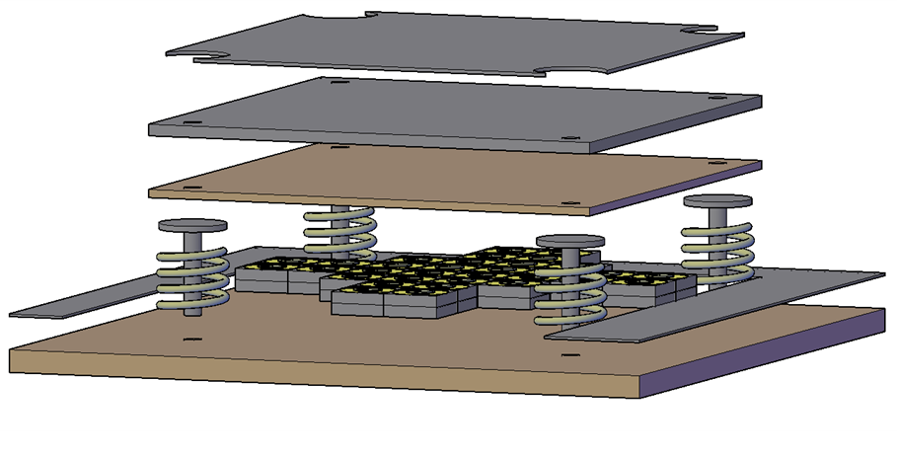
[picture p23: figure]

Figura 1: Vista lateral de la baldosa

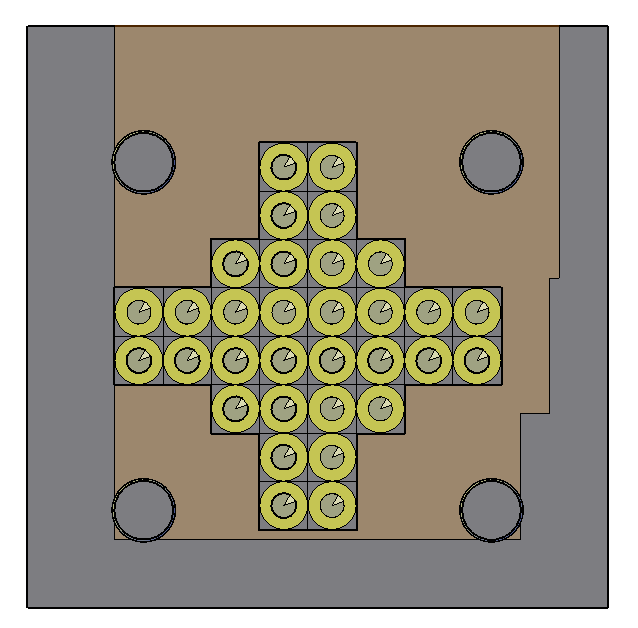
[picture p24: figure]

Figura 2: Vista superior de la baldosa

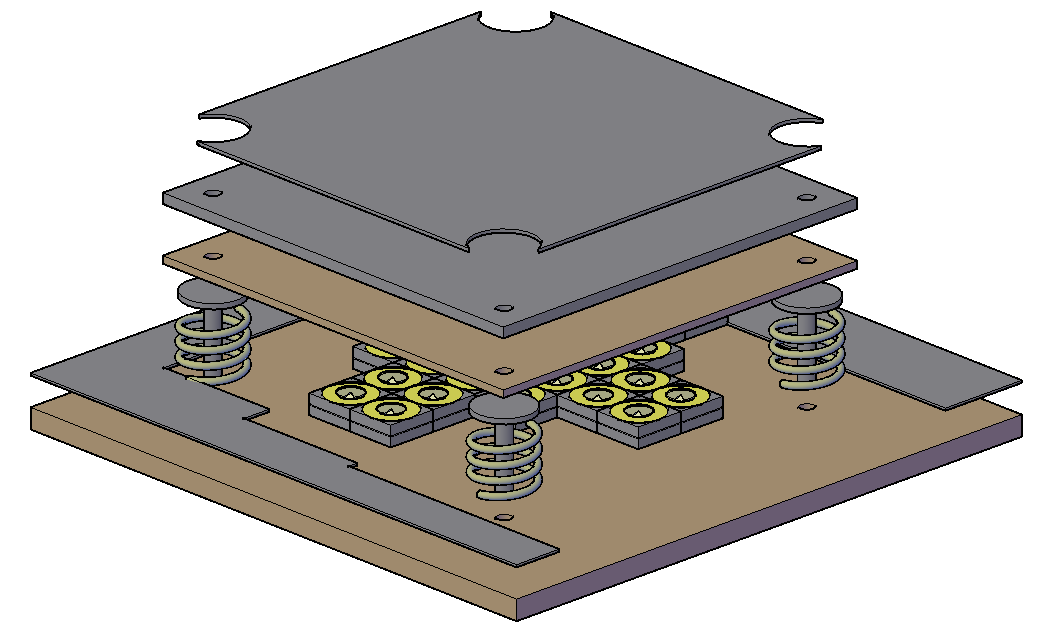
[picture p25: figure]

Figura 3: Vista isométrica de la baldosa

# 4. Mantenimiento y cuidado

A continuación, se enumeran una lista de prácticas y precauciones que se deben tener en cuenta a la hora de manipular la baldosa:

- Mantener la superficie de la baldosa limpia y seca. En caso de acumulación de polvo, utilizar un paño suave y seco para su limpieza.
- Evitar el contacto directo con líquidos o sustancias corrosivas que puedan dañar los materiales o las conexiones eléctricas.
- No aplicar golpes sobre la estructura, ya que podría afectar el rendimiento del sensor piezoeléctrico.
- Revisar periódicamente las conexiones entre la placa piezoeléctrica, el circuito de rectificación y la batería, asegurando que no existan cables sueltos ni signos de deterioro.
- Verificar el nivel de carga de la batería y el correcto funcionamiento del sistema de almacenamiento periódicamente.
- En caso de detectar fallas, no desmontar el sistema sin la supervisión de un técnico responsable.

# 5. Precauciones generales

Para garantizar un uso seguro y responsable de la baldosa, se deben tener en cuenta las siguientes precauciones:

- Evitar exponer la placa y sus componentes a temperaturas extremas, humedad elevada o fuentes directas de calor.
- No pisar la baldosa con objetos punzantes que pueda dañar la superficie caucho.
- Mantener el sistema alejado del alcance de niños pequeños o personas no capacitadas para su manipulación.
- En caso de cortocircuito, sobrecalentamiento o deformación visible de algún componente, desconectar inmediatamente el sistema y revisar su estado antes de volver a utilizarlo.

# 6. Soluciones de problemas

Se adjunta una tabla con problemas generales y sus posibles soluciones.

Problema | Posible causa | Solución recomendada
El display no enciende | Falta de conexión con la batería o cable suelto | Verificar las conexiones entre la batería y el módulo del display. Asegurarse de que los terminales estén firmes.
No se muestra el nivel de carga en el display | Error en la lectura del sensor o conexión defectuosa del circuito de medición | Revisar las soldaduras y el cableado del sistema de medición. Reiniciar el sistema y comprobar nuevamente.
No se genera energía al pisar la baldosa | Fallo en los sensores piezoeléctricos o desconexión en la placa de rectificación | Comprobar el estado físico de los sensores y las uniones entre la placa piezoeléctrica y la de rectificación.
El voltaje almacenado es muy bajo | Baja presión aplicada o batería parcialmente descargada | Probar con mayor número de pisadas. Revisar la batería y asegurarse de que esté en condiciones de carga.
El sistema se calienta durante el uso | Exceso de carga o cortocircuito en los componentes de almacenamiento | Desconectar inmediatamente el sistema. Dejar enfriar y revisar la polaridad de las conexiones.
Vibraciones o ruidos al pisar | Aflojamiento de resortes o topes de goma | Ajustar los elementos mecánicos y comprobar que la estructura esté correctamente nivelada.

PLEPER - 2025 E.E.S.T. N°7 IMPA “T.R.Q.”

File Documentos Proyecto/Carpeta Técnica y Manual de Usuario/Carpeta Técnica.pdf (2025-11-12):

# CARPETA TÉCNICA

# 7° 1° Aviónica Comisión “C”

# IMPA TRQ E.E.S.T N°7 2025

## Victoria Baza – Mauricio Blasco – Raúl Broncano – Ignacio García Isidro Stabile – Santiago Tejeda

## Integrantes

PLEPER - 2025 | E.E.S.T. N°7 IMPA “T.R.Q.”

Victoria Josefina Baza

DNI: 47750221

Tel.: 11 6246-0953

Mail: victoriajosefinabaza@gmail.com

Fecha de Nacimiento: 10/01/2007

Mauricio Blasco

DNI: 47877887

Tel.: 11 3649-1857

Mail: germauricio975@gmail.com

Fecha de Nacimiento: 22/05/2007

Víctor Raúl Broncano Ramos

DNI: 48159076

Tel.: 11 6679-4686

Mail: raul455896@gmail.com

Fecha de Nacimiento: 29/01/2007

Ignacio García Louzan

DNI: 47349722

Tel.: 11 6155-1737

Mail: nachogarcialouzan@gmail.com

Fecha de Nacimiento: 19/07/2006

Isidro Joaquín Stabile

DNI: 47484606

Tel.: 11 3170-7976

Mail: isidrost@hotmail.com

Fecha de Nacimiento: 01/08/2006

Santiago Alejandro Tejeda

DNI: 47739884

Tel.: 11 2695-8907

Mail: santiagotejeda36@hotmail.com

Fecha de Nacimiento: 16/01/2007

## Docentes tutores

- Arguello, Gustavo
- Bianco, Carlos
- Carlassara, Fabrizio
- Medina, Sergio
- Palmieri, Diego

## Fecha de Inicio

- 7 de Abril de 2025

## Esfuerzo del proyecto

- 31 Semanas de Trabajo
- 220 Horas de Trabajo en total

## Redes y enlaces de interés

- Página Web

https://pleper-impa.github.io/web/

- Instagram

https://www.instagram.com/pleper_25/

- GitHub

https://github.com/impatrq/Pleper

- Gmail

pleper.infoimpa@gmail.com

## Índice

1. Introducción | 7
1.1. | Resumen del proyecto | 7
1.2. | Motivación | 8
1.3. Estado del arte | 8
1.3.1. Pavegen | 8
1.3.2. Subtes en Tokio | 9
1.4. | Objetivos | 9
1.5. | ¿Quiénes Somos? | 9
1.6. | Desarrollo del Proyecto | 9
2. Estructura | 10
2.1. Diagrama General de la Estructura | 10
2.1.1. Diseño de la baldosa | 11
2.1.2. Diseño de los pilares | 12
2.2. Descripción y Diseños de Partes Estructurales | 12
2.2.1. Base | 12
2.2.2. Pilares 3D | 13
2.2.3. Resortes | 13
2.2.4. Ensamblaje Piezoeléctrico | 14
2.3.5. Tapa (Superficie de Pisada) | 16
2.2.6. Gabinete de display | 17
2.2.7. Tubo PVC | 18
3. Electrónica | 19
3.1. | Software utilizado para el desarrollo de esquemáticos y PCB | 19
3.2. | Esquemático de cada bloque | 19
3.3. | PCB de cada bloque | 20
3.4. | Modelo 3D de cada PCB | 22
4. Hardware | 23
4.1. | Circuito del Divisor de Tensión/Raspberry Pi Pico y Conexiones | 23
4.1.1. | Objetivo | 23
4.2. | Etapa Piezoeléctrica y Rectificadora | 24
4.3. | Divisor de Tensión | 24
4.4. | Raspberry Pi Pico W | 25
4.5. | Display LCD | 26
4.6. | Alimentación y Protección | 26
5. Software | 27

5.1. | Configuración de Bibliotecas y Definiciones Iniciales | 28
5.2. | Función calcular_voltaje_real() | 28
5.3. | Función Principal main() | 28
5.4. | Librerías lcd.c y lcd.h | 30
5.5. | Archivo CMakeLists.txt | 30
5.6. | Explicación del código por línea | 31
5.6.1. | pleper.c | 31
5.6.2. | CMakeLists.txt | 35
5.6.3. | lcd.c | 38
5.6.4. | lcd.h | 42
6. Anexo | 44
6.1. Biblografía | 44

## 1.Introducción

PLEPER, por sus siglas “Placa de Energía Piezoeléctrica enovable” es una baldosa que permite que las personas que pasen por encima de ella generen una pequeña cantidad de energía eléctrica, permitiéndoles así colaborar con la generación de una energía autosustentable que tiene como fin almacenar suficiente carga para su aplicación en casos de emergencia, asegurando así que haya un medio de proveer luz en un corte de electricidad por un tiempo suficiente para ponerse en resguardo.

El sistema se basa en una placa que explota el fenómeno de la piezoelectricidad, aprovechando los pulsos generados por los sensores cerámicos al ser deformados mecánicamente. Su diseño de baldosa es especialmente útil para poder implementarlo en vías públicas donde hay un alto tránsito y se puede aprovechar mejor la generación de energía eléctrica.

Aspiramos a lograr demostrar que es posible desarrollar formas alternativas de generar energía, concientizando a las personas mediante el uso de la misma placa y haciéndolos participes del cambio.

### 1.1. Resumen del proyecto

El proyecto se centra en el desarrollo de una baldosa con distintas capas la cual, al presionarla, generará un pequeño pulso eléctrico que se busca aprovechar mediante el almacenamiento de esta energía. El sistema está constituido principalmente por los siguientes componentes: una baldosa de madera como base, distintas bases de caucho que sostienen 32 sensores piezoeléctricos, cuatro resortes en cada esquina, topes de goma entre los sensores piezoeléctricos y la placa de madera que esta encima, una baldosa de caucho como superficie para pisar, un módulo de almacenamiento con 4 capacitores de 10uF, un microcontrolador y una luz de emergencia.

El funcionamiento del sistema es el siguiente: el usuario caminará por encima de la baldosa como si fuera una placa más del piso, generando presión mecánica sobre esta y luego permitiendo que vuelva a su estado original. En esta deformación mecánica, los sensores piezoeléctricos generaran un pequeño pulso que será rectificado y almacenado en varios capacitores conectadas en paralelo.

Una vez varios usuarios, o el mismo haciendo distintas pasadas, pisen la placa, esta energía almacenada será distribuida por un microcontrolador, el cual la utilizará para alimentar un cartel de emergencia, simulando una situación donde la energía eléctrica se fuera en una estación de Subte, un lugar muy concurrido que, al pasar muchas personas, lograría almacenar una buena carga para alimentar el cartel de emergencia, pudiéndose aprovechar.

### 1.2. Motivación

Como estudiantes de séptimo año, buscamos desarrollar un proyecto con el fin de cumplir con el requerimiento horario de practicas profesionalizantes. Nuestra intención inicial fue desarrollar algo relacionado a energías alternativas, en vista del creciente interés por el desarrollo de energías renovables con el fin de apaciguar las consecuencias experimentadas por el cambio climático. Bajo este marco, y en búsqueda de alternativas no tan exploradas aún, decidimos tomar como base de nuestro proyecto el efecto piezoeléctrico, no tan visibilizado. Creemos que este proyecto tiene el potencial de concientizar a más personas sobre la necesidad de buscar alternativas no tan destructivas a nuestro ecosistema, visibilizando un fenómeno que, si bien se ha explorado en algunas partes del mundo, poca gente conoce su existencia y potencial.

### 1.3. Estado del arte

1.3.1. Pavegen

Uno de los referentes que analizamos para la conceptualización del proyecto fue Pavegen, una empresa británica dedicada al desarrollo de baldosas inteligentes capaces de transformar la energía de las pisadas humanas en electricidad utilizable. Estas baldosas funcionan mediante un sistema de inducción electromagnética y movimiento mecánico, generando pequeñas cantidades de energía cada vez que una persona las pisa.

El objetivo principal de esta tecnología es aprovechar el tránsito peatonal en espacios públicos para alimentar sistemas de bajo consumo, como luminarias LED, pantallas interactivas o sensores de monitoreo. Además, Pavegen incorpora herramientas de recolección de datos que permiten medir la cantidad de pasos y el flujo de personas en un lugar determinado, contribuyendo así al desarrollo de entornos urbanos más inteligentes y sostenibles.

Este ejemplo fue uno de los primeros que hallamos al investigar sobre aportes a la utilización de la energía piezoeléctrica, nos permitió reflexionar sobre la viabilidad de utilizar la energía cinética como fuente renovable aplicada a la vida cotidiana. Si bien nuestro proyecto no busca replicar la complejidad de Pavegen, nos resultó relevante como antecedente que demuestra cómo la energía generada por el movimiento humano puede almacenarse y aprovecharse de manera innovadora.

1.3.2. Subtes en Tokio

Otro caso que analizamos fue el de los sistemas de transporte en Tokio, donde se han implementado tecnologías piezoeléctricas en estaciones de metro con el objetivo de generar energía a partir del tránsito masivo de pasajeros. Estas instalaciones utilizan baldosas especiales que convierten la presión de las pisadas en electricidad, la cual luego se emplea para alimentar iluminación de bajo consumo, paneles informativos y otros dispositivos dentro de las estaciones.

El contexto japonés resulta particularmente interesante debido al alto caudal de personas que circula diariamente por el metro de Tokio, lo que permite obtener un volumen considerable de energía renovable a partir de una acción cotidiana como caminar. Además, estas iniciativas se enmarcan dentro de las políticas de sostenibilidad y eficiencia energética que caracterizan a muchas ciudades japonesas, donde la innovación tecnológica se aplica directamente a la vida urbana.

Este ejemplo nos permitió comprender cómo la energía piezoeléctrica puede ser aplicada a gran escala en espacios públicos con alto flujo de usuarios. Si bien nuestro proyecto no busca alcanzar esa magnitud, consideramos valiosa esta experiencia como inspiración para adaptar la misma lógica en un prototipo más reducido y demostrativo.

### 1.4. Objetivos

El objetivo de nuestro proyecto es el de lograr generar energía utilizando como fuente principal proveedora la deformación mecánica que generan las pisadas y ser capaces de almacenarla y aprovecharla para alimentar un LED que sirva como luminaria de emergencia, pudiendo generar energía de una forma no convencional en casos de emergencia.

### 1.5. ¿Quiénes Somos?

Somos el grupo PLEPER (Placa de Energía Piezoelectrica Renovable), conformado por seis estudiantes de la especialidad de Aviónica del séptimo año, primera división, comisión C, de la Escuela Técnica N°7 IMPA “Taller Regional Quilmes”.

### 1.6. Desarrollo del Proyecto

A continuación, se presenta un diagrama en bloques que implicó la columna vertebral de nuestro desarrollo, centrándonos en cumplir lo presente aquí pero haciendo las modificaciones necesarias al encontrar una oposición a la idea original:


Figura 1: diagrama de flujo representando el eje de desarrollo propuesto

## 2. Estructura

### 2.1. Diagrama General de la Estructura

Se utilizo el programa AutoCAD 2025 para el diseño de piezas 3D como los pilares y los topes de los piezoeléctricos.

2.1.1. Diseño de la baldosa

Figura 2, 3 y 4: Vistas del diseño de la estructura en AutoCAD

2.1.2. Diseño de los pilares

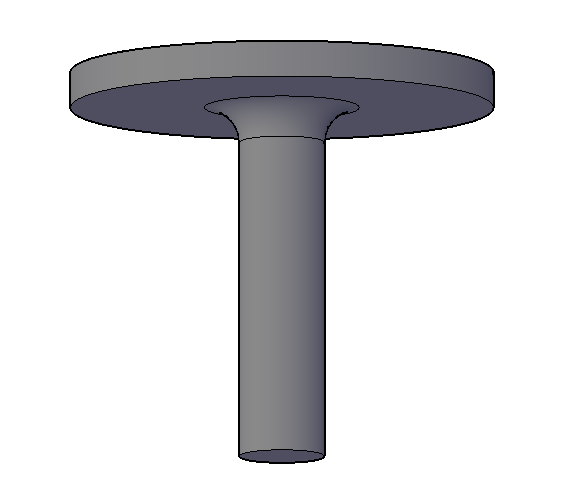
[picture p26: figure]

Figuras 5 y 6: Vistas de los pilares diseñados en AutoCAD

### 2.2. Descripción y Diseños de Partes Estructurales

2.2.1. Base

Consiste en una tabla elaborada con madera terciada de 7 capas, con un área de 42x42 cm y agujereada en las cuatro esquinas con orificios de 13mm de diámetro y 5mm de profundidad para la colocación de los pilares 3D. Posee también una alfombra decorativa sobre ella. En el medio de la base se distribuyeron los piezoeléctricos para aprovechar al máximo la tensión generada.

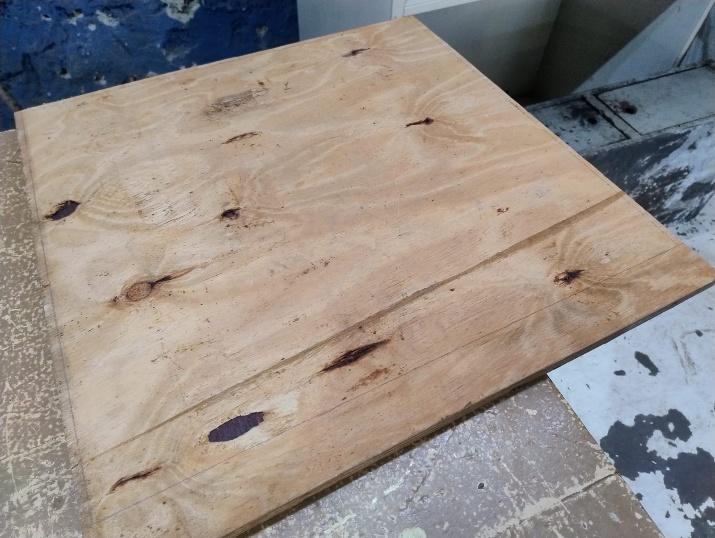
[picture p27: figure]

Figura 7: Base de madera utilizada

2.2.2. Pilares 3D

Para mantener la baldosa firme, se añadieron pilares en cada esquina. Fueron diseñados en AutoCAD e impresos en 3D. Se forman por una base circular de 12mm de diámetro y 65mm de altura, y sobre ella un círculo de 60mm de diámetro y 5mm de altura. La conexión entre ambas partes fue redondeada para repartir eficientemente el peso. Estos pilares fueron pegados con silicona a los agujeros de la base.

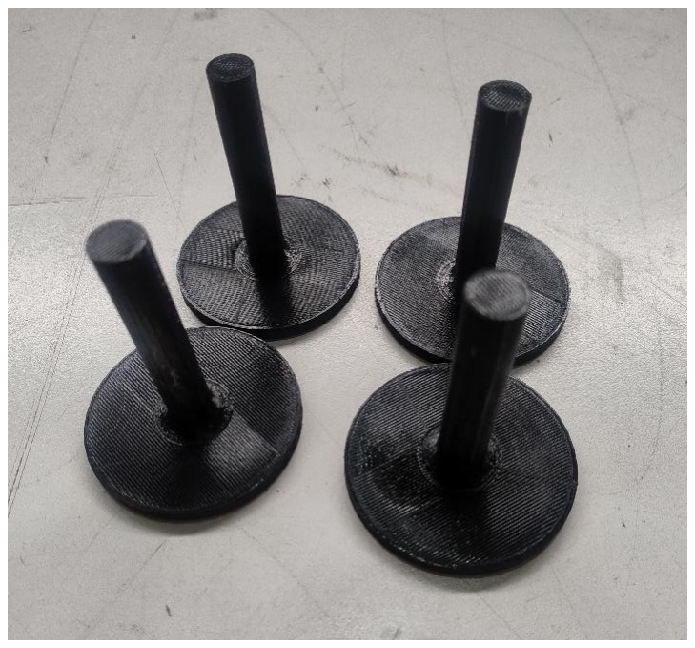
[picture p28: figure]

Figura 8: Pilaress impresos en 3D

2.2.3. Resortes

Para que la baldosa regrese a su posición original tras ser pisada, se utilizaron cuatro resortes en las esquinas. Poseen una altura de 4,75 cm, un radio exterior de 5,93 cm y 3,5 vueltas. Para mantenerlos en posición, se pegó una estructura circular de 46mm (diámetro interno) y 51mm (diámetro exterior).

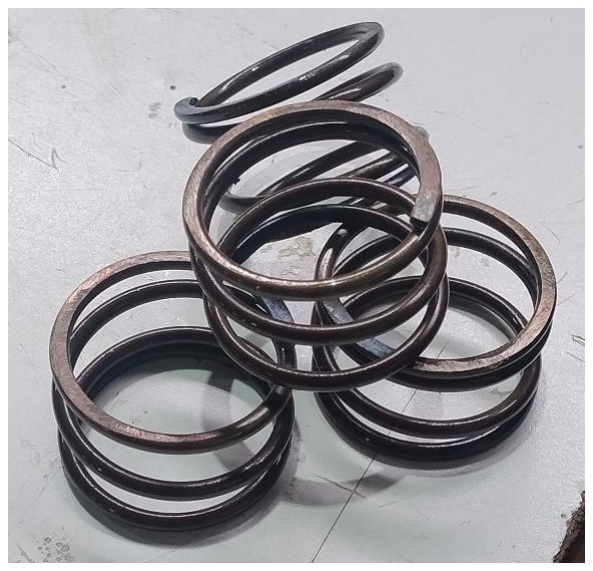
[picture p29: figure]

Figura 9: Resortes utilizados

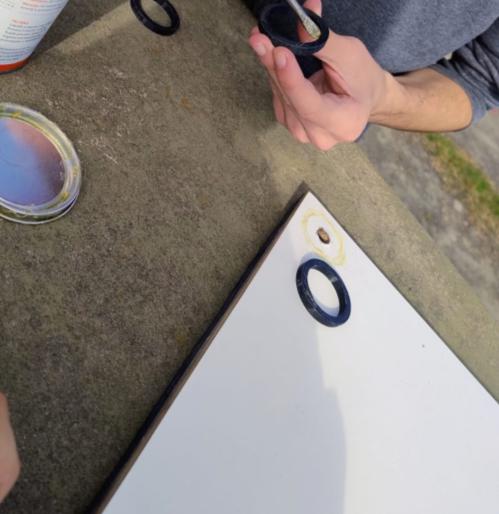
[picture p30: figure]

Figura 10: Anillos para mantener los resortes

2.2.4. Ensamblaje Piezoeléctrico
2.2.4.1. Bases de Piezoeléctricos:
Se requería una base que aumente la altura en la que se ubican los piezoeléctricos, además de permitirlos deformarse y amortiguar el impacto por lo que no podía ser echa de un material rígido. Tras analizar detenidamente su forma decidimos realizarlos a base de caucho, el cual repartimos sobre las medidas hechas anteriormente en la base de madera. Recortamos el caucho en rectángulos con una base de 5x5 con una altura de 2cm y los pegamos a la base utilizando adhesivo de contacto.

Figura 11: Bases de piezoeléctricos con ellos

2.2.4.2. Sensores Piezoeléctricos:
Se colocaron sobre las bases de caucho en grupos de cuatro conectados en paralelo. Cada piezoeléctrico posee un diámetro de 5cm (negativo) y 2,5cm (positivo). Se pegaron con adhesivo de contacto.

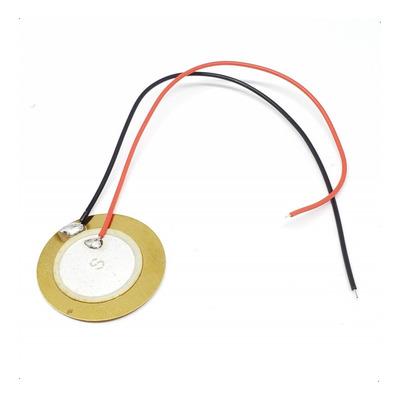
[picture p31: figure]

Figura 12: Sensor piezoeléctrico

2.2.4.3. Topes:
Para aumentar la eficiencia y reducir el desgaste de las soldaduras, se colocaron topes cúbicos. Estos topes fueron elaborados en AutoCAD e impresos en 3D.

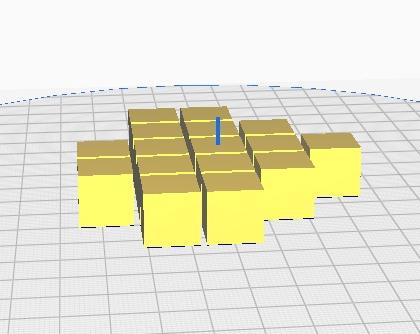
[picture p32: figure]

Figura 13: Diseño 3D de los topes cúbicos

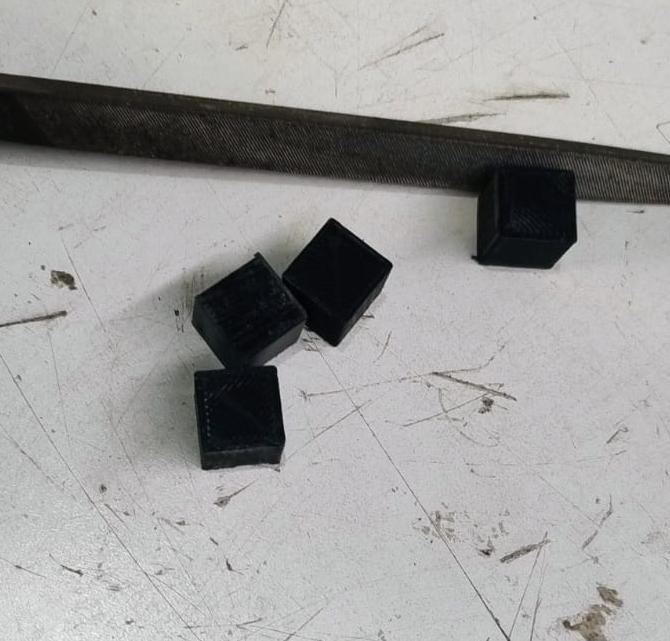
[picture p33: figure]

Figura 14: Topes cúbicos

2.3.5. Tapa (Superficie de Pisada)
2.3.5.1. Madera:
Base de 42x42 cm con cuatro agujeros de 13mm en las esquinas por donde pasan los pilares 3D.

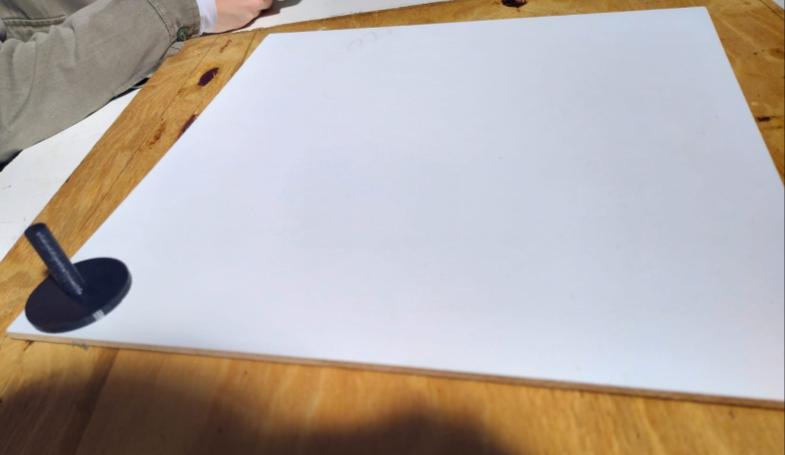
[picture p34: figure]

Figura 15: Madera de base para la tapa

2.3.5.2. Caucho:
La capa de caucho mide 42 cm x 42 cm, y posee un agujero en cada esquina con un diámetro de 13mm. Esta capa está colocada para disminuir el contacto del pie con la madera y aumentar su vida útil. Sobre este se ubica una alfombra antideslizante que evita que se ensucie de forma tan rápida la baldosa y a su vez facilita la limpieza de esta.

Figura 16: Caucho de alfombra para la tapa

2.2.6. Gabinete de display

La caja de madera del sistema fue diseñada para proteger y alojar los componentes electrónicos del entorno del display de manera robusta, ordenada y estética. Su principal función es servir como gabinete contenedor del sistema completo, asegurando una correcta organización del circuito, estabilidad mecánica y seguridad durante su uso o exposición.

Es una caja de 20 cm x 40 cm con 15 cm de altura, está elaborada con madera de un grosor de 2cm. En la parte frontal se expande 24cm hacia arriba para poder atornillar el cartel de emergencia, además posee una ranura a 11 cm de los costados a una altura de 7,5 cm, la cual tiene un ancho de 18 cm y una altura de 3 cm. En la parte trasera se encuentra un agujero en la que se colocaría la puerta que permitiría abrir y cerrar la caja. Por ultimo en la parte inferior se ubica un círculo de 4 cm de diámetro para poder conectar el tubo PVC.

Figura 17: Gabinete de madera

2.2.7. Tubo PVC

Se agregó un tubo PVC para que el display se encuentre a la altura de la vista de las personas y no resulte incomodo, el cual tiene 4 cm de diámetro para mejorar su rigidez y una altura de 1,3 metros acoplado a la base de la baldosa por medio de dos soportes en L que lo sostienen por medio de los tornillos. Posee un corte en la parte inferior de 1 cm x 1 cm que permite pasar los cables por su interior. Decidimos pintar este tubo de color negro para mejorar la estética de este.

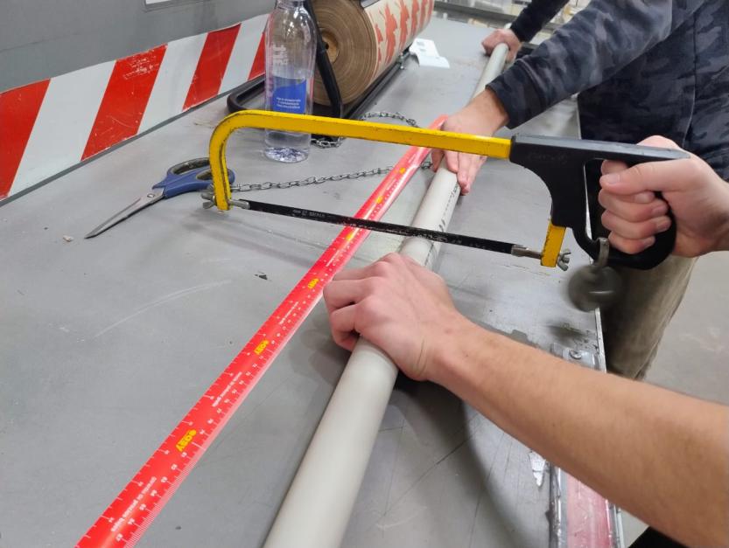
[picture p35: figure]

Figura 18: Tubo PVC

## 3. Electrónica

### 3.1. Software utilizado para el desarrollo de esquemáticos y PCB

Principalmente se utilizó KiCad 9.0 tanto para diseñar los esquemáticos como para los diseños PCB. Se utilizó el visualizador de modelos 3D integrado para poder ver cada placa desarrollada.

### 3.2. Esquemático de cada bloque

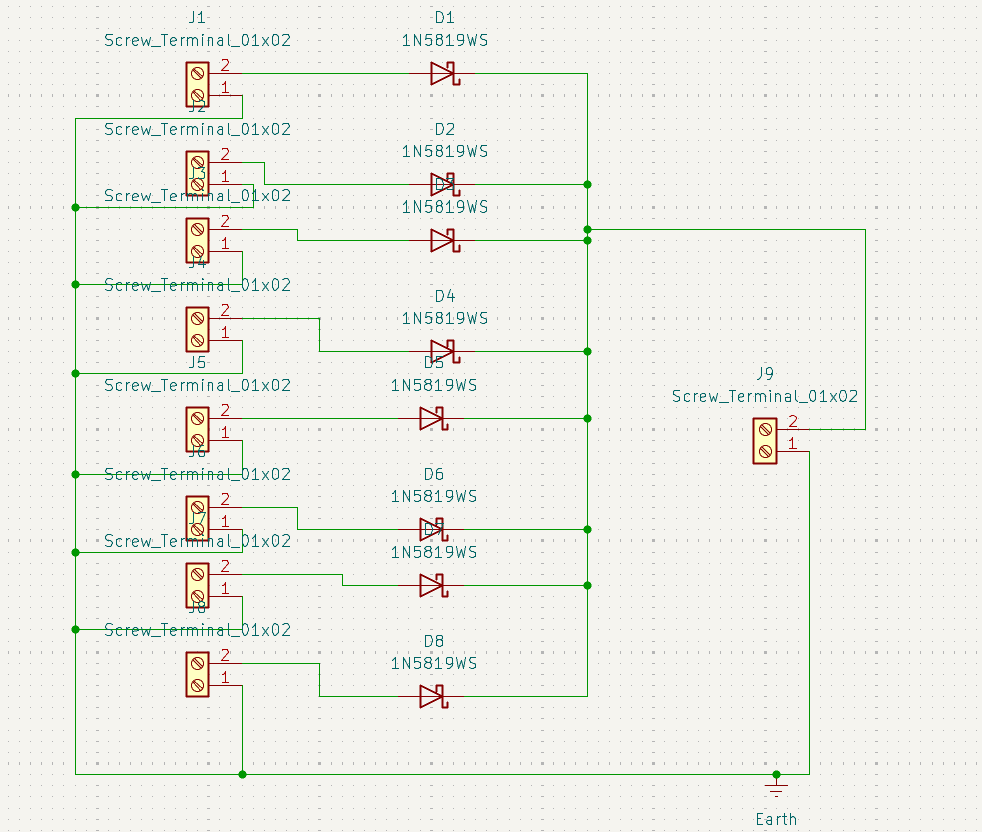
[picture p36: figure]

Figura 19: Esquemático de la “Placa Rectificadora”

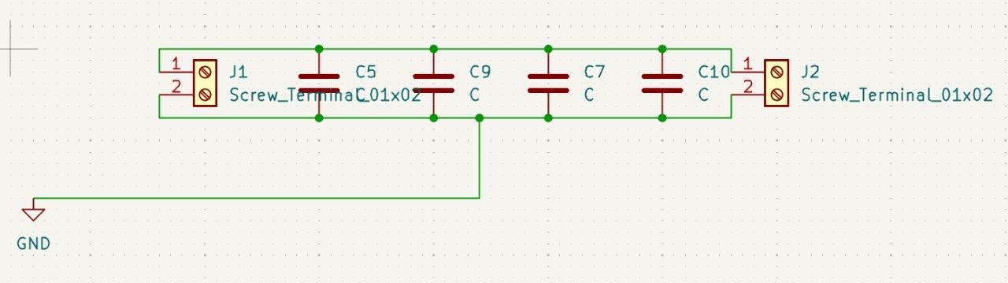
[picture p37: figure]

Figura 20: Esquemático del “Banco de Capacitores”

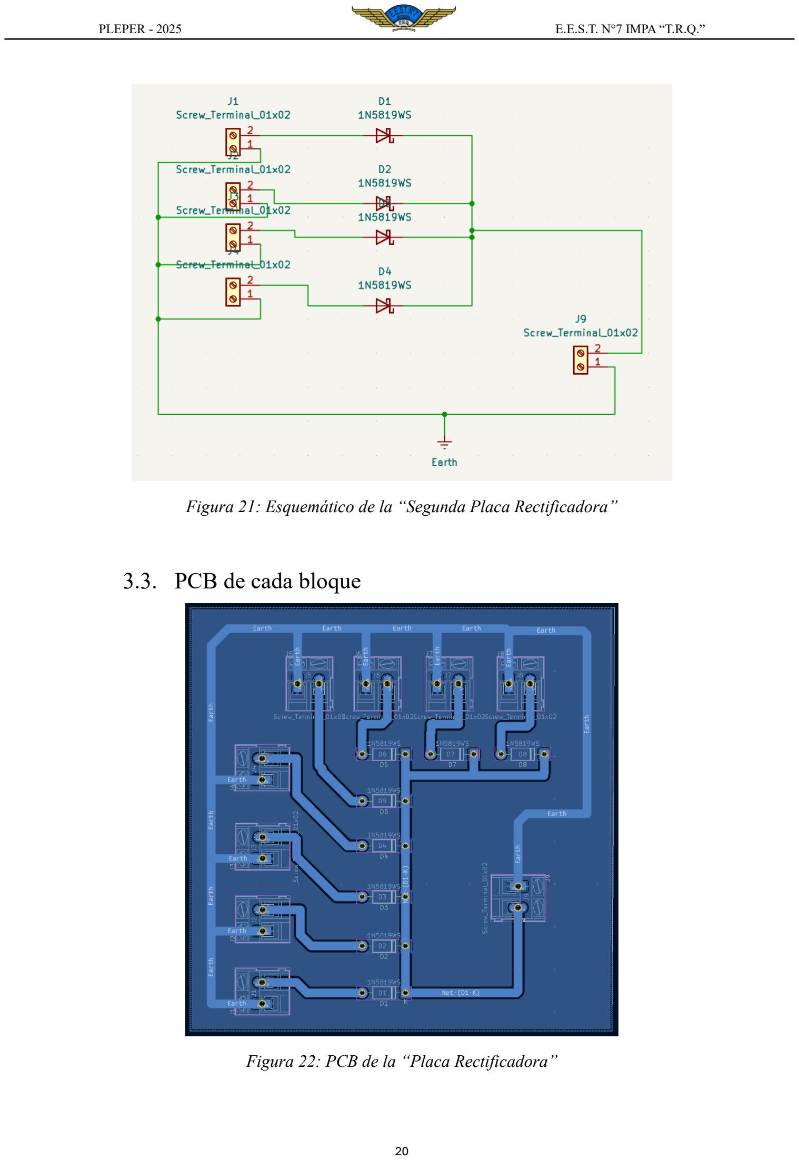
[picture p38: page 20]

Figura 21: Esquemático de la “Segunda Placa Rectificadora”

### 3.3. PCB de cada bloque

Figura 22: PCB de la “Placa Rectificadora”

Figura 23: PCB del “Banco de Capacitores”

Figura 24: PCB de la “Segunda Placa Rectificadora”

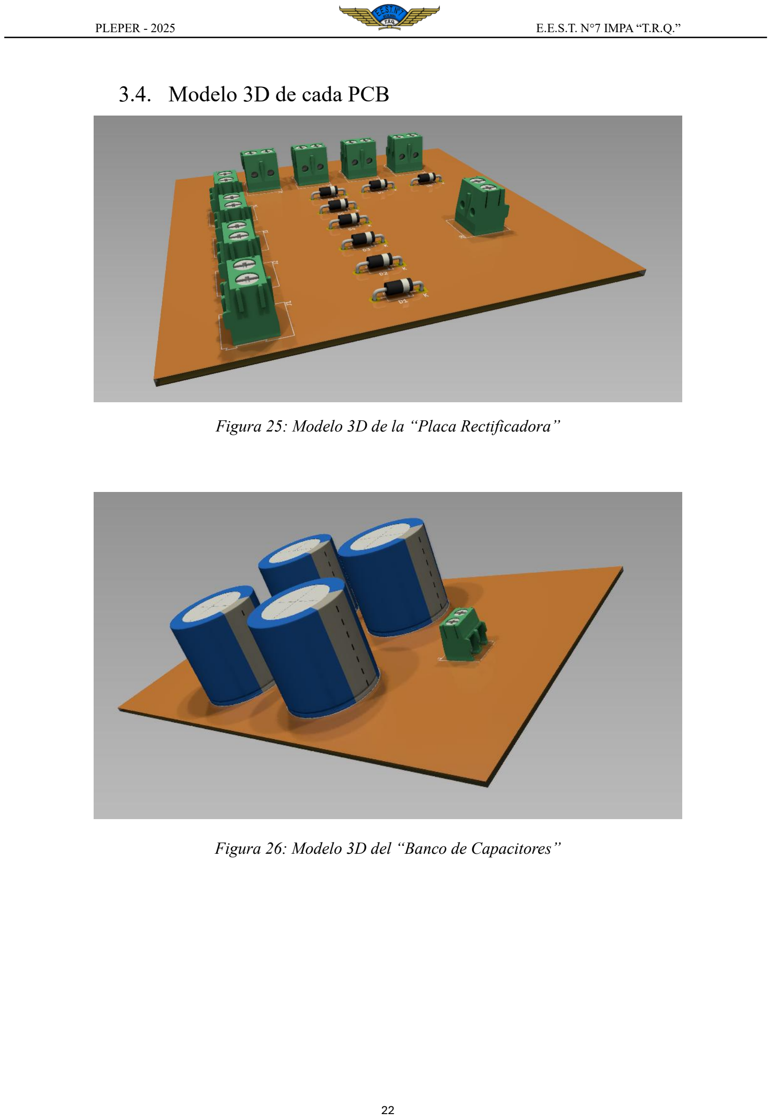
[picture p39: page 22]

### 3.4. Modelo 3D de cada PCB

Figura 25: Modelo 3D de la “Placa Rectificadora”

Figura 26: Modelo 3D del “Banco de Capacitores”

## 4. Hardware

### 4.1. Circuito del Divisor de Tensión/Raspberry Pi Pico y Conexiones

4.1.1. Objetivo

El circuito diseñado para el proyecto tiene como función detectar los picos de tensión generados por una baldosa piezoeléctrica al ser presionada. Cada vez que alguien pisa la superficie, el material piezoeléctrico produce una diferencia de potencial momentánea. Esta energía eléctrica, aunque breve y de baja corriente, se manifiesta como un pulso de tensión que se puede medir. La idea central es registrar esos picos y mostrarlos en un display LCD en tiempo real, permitiendo observar de manera visual la magnitud de la tensión producida por cada pisada.

Para lograrlo, se utiliza una Raspberry Pi Pico W como unidad principal de medición y procesamiento. La señal de la baldosa pasa primero por una etapa rectificadora que convierte la tensión alterna generada en una señal continua. Luego, esta señal se reduce mediante un divisor de tensión antes de ingresar al convertidor analógico–digital (ADC) del microcontrolador. Finalmente, la Pico procesa el valor obtenido y lo muestra en el display LCD a través de la comunicación I2C.

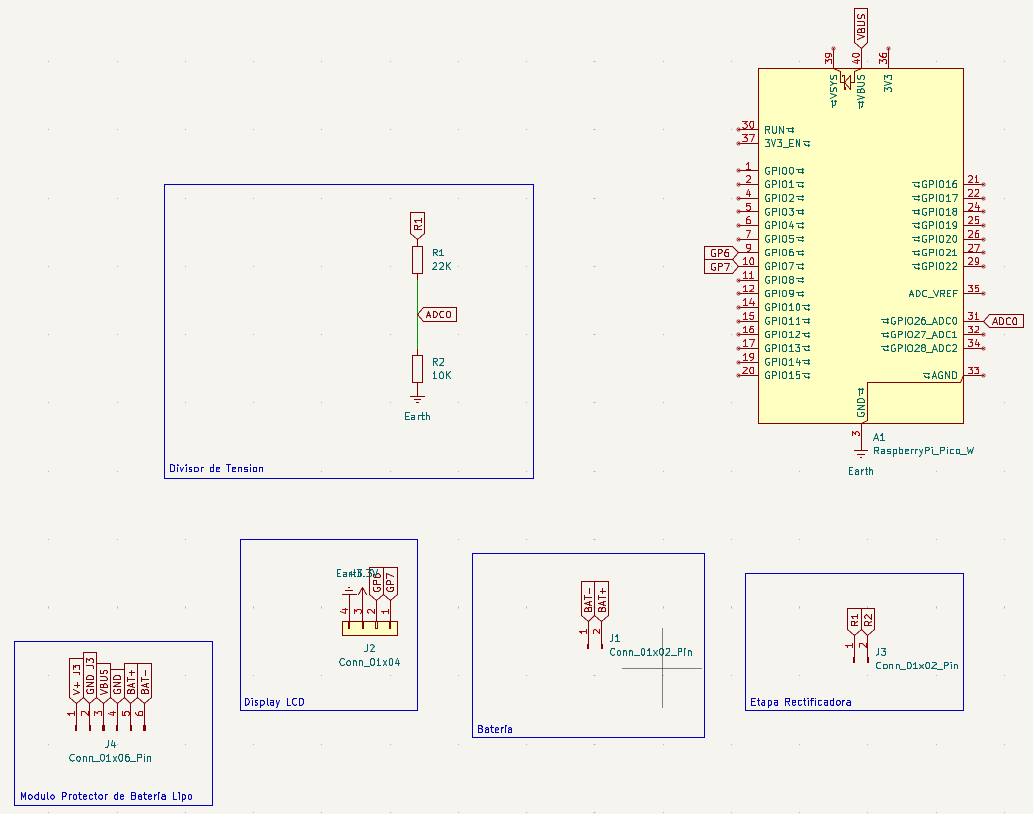
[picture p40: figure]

Figura 28: Esquema de componentes para el circuito de la Raspberry Pi Pico

### 4.2. Etapa Piezoeléctrica y Rectificadora

La baldosa piezoeléctrica actúa como generador eléctrico cuando se le aplica presión. Su estructura interna convierte la energía mecánica del impacto o pisada en energía eléctrica, generando una señal de corriente alterna. Dicha señal es irregular y dura solo el tiempo que la baldosa permanece bajo presión. Para que esta señal pueda ser medida por la Raspberry, primero debe ser rectificada, ya que el ADC solo puede trabajar con tensiones positivas de corriente continua.

La etapa rectificadora, representada en el esquema mediante el conector J3, se encarga de convertir la señal alterna en una señal pulsante continúa utilizando un puente de diodos. De esta forma, se eliminan los semiciclos negativos y se obtiene una salida positiva proporcional a la fuerza ejercida sobre la baldosa. Esta etapa es fundamental porque estabiliza la polaridad de la señal y protege los componentes electrónicos posteriores frente a inversiones de tensión.

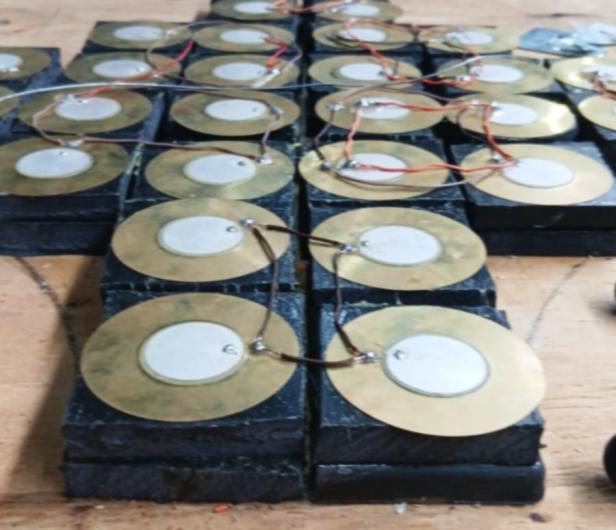
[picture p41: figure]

Figura 29: Piezoeléctricos Distribuidos sobre la baldosa

### 4.3. Divisor de Tensión

La señal rectificada que proviene de la baldosa puede alcanzar valores que superan los 3,3 V máximos que el ADC de la Raspberry puede medir de forma segura. Para evitar daños, se utiliza un divisor resistivo formado por dos resistencias en serie, R1 de 22 kΩ y R2 de 10 kΩ. Este circuito reduce la tensión de entrada manteniendo la proporción entre ambas resistencias. El punto intermedio entre ellas se conecta directamente al pin ADC0 del microcontrolador.

Gracias a este divisor, los picos de tensión de la baldosa son escalados a un rango compatible con el ADC, garantizando una medición segura y precisa. Por ejemplo, un pico de 10 V a la entrada del divisor se traduce aproximadamente en 3,1 V en la entrada del ADC. En algunos casos, puede añadirse un pequeño capacitor en paralelo con la resistencia inferior para filtrar ruido y obtener una lectura más estable. En conjunto, este bloque cumple un rol de protección y adaptación de señal dentro del sistema.

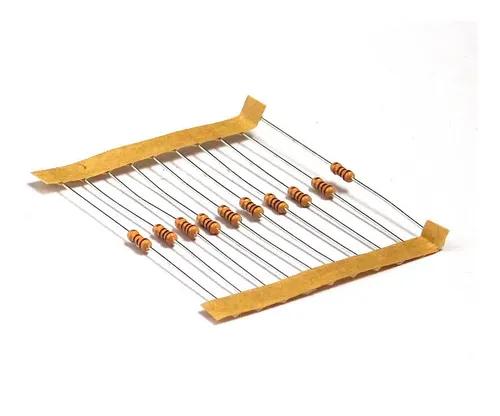
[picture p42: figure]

Figura 30: Conjunto de resistencias para formar un divisor de tensión

### 4.4. Raspberry Pi Pico W

La Raspberry Pi Pico W es el microcontrolador encargado de procesar la información proveniente del divisor de tensión. Su convertidor analógico–digital convierte los pulsos eléctricos en valores numéricos que el programa interpreta en tiempo real. Al detectar un pico de tensión, la Pico calcula su magnitud y la envía inmediatamente al display LCD.

El microcontrolador se comunica con el LCD mediante la interfaz I2C, utilizando los pines GPIO6 y GPIO7 para las líneas de datos (SDA) y reloj (SCL). El pin GPIO26, correspondiente al canal ADC0, se usa para la medición analógica de los pulsos. La Pico también se encarga de la alimentación de la pantalla y de mantener la referencia de 3,3 V para el ADC, garantizando lecturas consistentes. De este modo, la placa centraliza la adquisición, procesamiento y visualización de los datos en un único módulo compacto y de bajo consumo.

Figura 31: Microcontrolador Raspberry Pi Pico

### 4.5. Display LCD

El display LCD 16x2 cumple la función de mostrar la tensión detectada en cada pisada. Está conectado a la Raspberry mediante un módulo adaptador I2C, lo que reduce significativamente la cantidad de pines necesarios para la comunicación. Gracias a esta interfaz, el microcontrolador puede enviar comandos y datos con solo dos líneas, lo que simplifica el cableado y mejora la estabilidad del sistema.

Durante el funcionamiento, el display muestra en tiempo real el valor de tensión correspondiente al último pico detectado. Esto permite observar visualmente la respuesta eléctrica de la baldosa piezoeléctrica y comparar la intensidad de las pisadas. Su alimentación puede provenir directamente de la Pico, y el módulo I2C incluido en la parte posterior del LCD se encarga de traducir las señales digitales enviadas por la Raspberry.

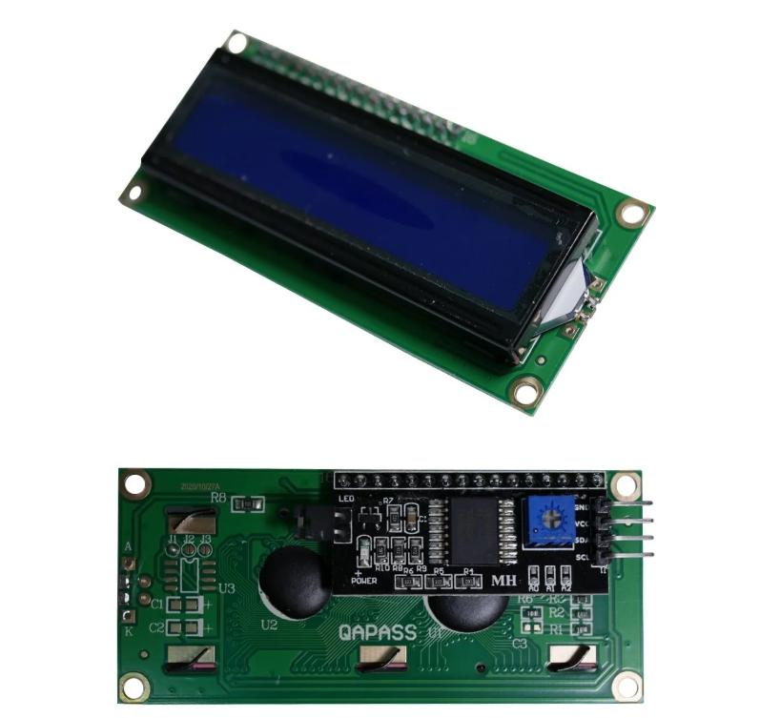
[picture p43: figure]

Figuras 32 y 33: Display LCD 16x2

### 4.6. Alimentación y Protección

El sistema puede funcionar alimentado mediante una batería LiPo conectada a través de un módulo de protección que evita sobrecargas y descargas profundas. Este módulo, identificado en el esquema, asegura un suministro estable y protege tanto a la Raspberry como al display frente a picos o caídas de tensión. En caso de pruebas de laboratorio, también puede alimentarse directamente mediante el puerto USB de la Pico sin necesidad de la batería.

Toda la electrónica comparte un mismo punto de masa, lo que evita diferencias de potencial entre etapas y garantiza una medición confiable. La conexión correcta de las tierras es esencial para que el ADC tenga una referencia estable y los picos se midan con precisión.

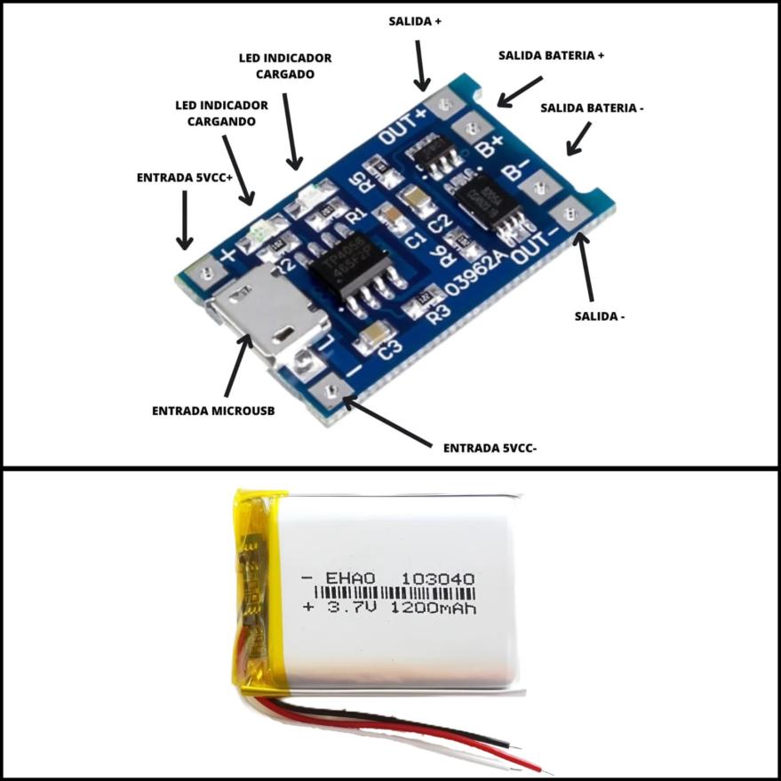
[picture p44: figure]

Figura 34: Batería LiPo junto a su módulo de carga

## 5. Software

El programa desarrollado para la Raspberry Pi Pico W tiene como propósito medir los picos de tensión generados por la baldosa piezoeléctrica, procesarlos digitalmente y mostrarlos en tiempo real en un display LCD con comunicación I2C. El código fue escrito en lenguaje C y utiliza las bibliotecas del SDK oficial de Raspberry Pi Pico, junto con una librería propia denominada lcd.c que gestiona las funciones de visualización.

El programa realiza un ciclo continuo de adquisición, conversión y visualización de datos. Cada vez que la baldosa genera un pulso eléctrico, la señal pasa por el divisor resistivo, es convertida a una lectura digital mediante el ADC del microcontrolador y finalmente se muestra en el LCD en forma de valor instantáneo de tensión.

### 5.1. Configuración de Bibliotecas y Definiciones Iniciales

En la primera sección del código se incluyen las librerías necesarias para el funcionamiento del programa. Se utilizan las cabeceras hardware/gpio.h, hardware/i2c.h y hardware/adc.h para acceder a las funciones de bajo nivel que controlan los periféricos de la Pico, mientras que pico/stdlib.h brinda funciones generales del sistema. La inclusión de "lcd.h" corresponde a la librería desarrollada para controlar el display LCD mediante el bus I2C.

Luego se definen los pines de conexión: GPIO6 y GPIO7 se asignan como líneas de datos (SDA) y reloj (SCL) del bus I2C, mientras que GPIO26 se establece como la entrada analógica ADC0. También se definen dos constantes fundamentales: ADC_MAX_VAL, que representa el valor máximo que puede entregar el conversor analógico–digital (4095, correspondiente a 12 bits), y VREF, que define la tensión de referencia del ADC (3.3 V).

A continuación se declaran las variables del divisor de tensión (R1 y R2), cuyos valores se usan para convertir la lectura del ADC en un voltaje real. Estas variables son configurables, lo que permite adaptar el código a diferentes divisores sin modificar la lógica principal.

### 5.2. Función calcular_voltaje_real()

Esta función cumple el papel de adquirir el valor analógico desde el pin ADC0 y convertirlo en una tensión equivalente al valor real presente en la entrada del divisor resistivo. Primero, mediante adc_select_input(0) se selecciona el canal ADC0 de la Pico. Luego se ejecuta adc_read(), que devuelve un valor entero entre 0 y 4095 proporcional a la tensión medida.

El siguiente paso consiste en convertir ese número a un voltaje, aplicando la relación entre el valor digital y la referencia de 3.3 V. Finalmente, el resultado se corrige considerando la relación del divisor de tensión, multiplicando por el factor (R1 + R2)/R2. De esta manera se obtiene el voltaje real generado por la baldosa piezoeléctrica, expresado en volts. Esta función encapsula todo el proceso de medición, simplificando el cuerpo principal del programa.

### 5.3. Función Principal main()

La función main() es el núcleo del programa y se encarga de inicializar los periféricos, configurar los módulos de hardware y ejecutar el ciclo de medición continua. Primero se invoca stdio_init_all() para iniciar las funciones básicas del sistema. Luego se configura el bus I2C: se inicializa el módulo i2c1 con una frecuencia de 100 kHz y se asignan los pines GPIO6 y GPIO7 a la función I2C.

También se activan resistencias de pull-up internas en ambas líneas para garantizar la correcta comunicación con el módulo LCD.

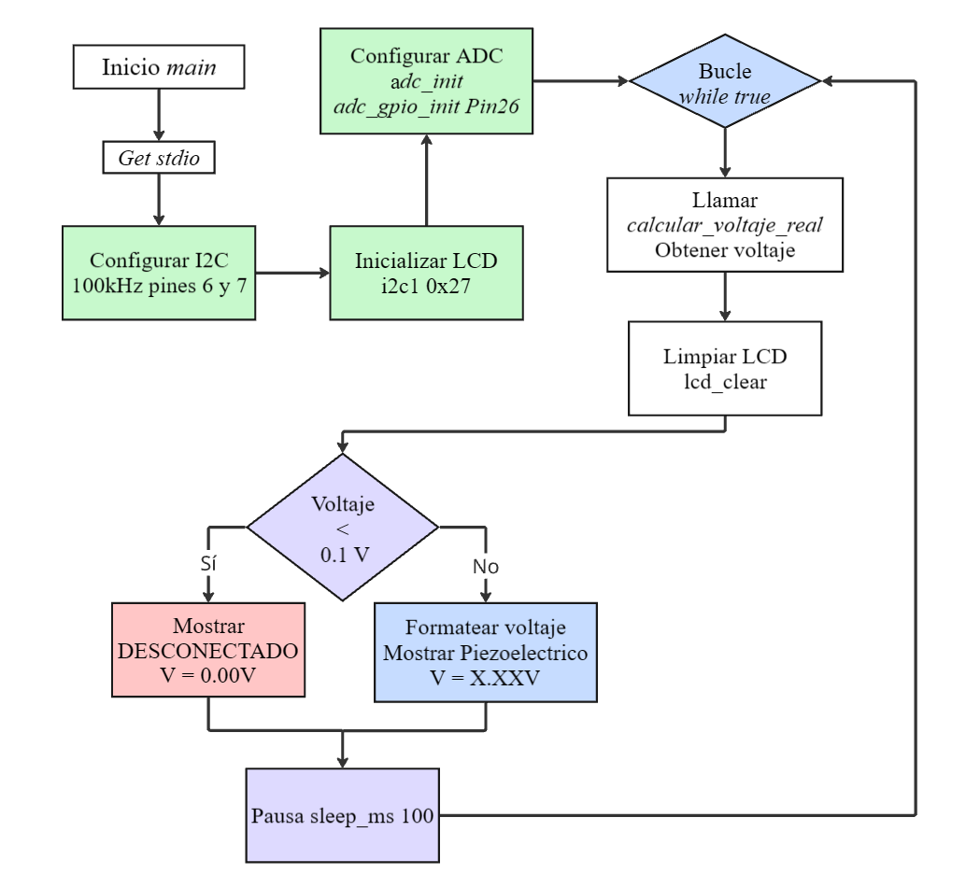
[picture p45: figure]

Figura 35: Diagrama en bloques de la función main.c

Una vez configurado el bus, se llama a lcd_init(i2c1, 0x27) para inicializar el display en la dirección I2C 0x27, que es la más común en los módulos basados en PCF8574. Paralelamente, se configura el sistema de adquisición analógica: se inicializa el ADC y se habilita el pin GPIO26 como entrada analógica mediante adc_gpio_init(ADC_PIN).

Con la inicialización completa, el programa entra en un bucle while(true) que se ejecuta indefinidamente. Dentro de este bucle, se llama a calcular_voltaje_real() para obtener la lectura actual del sensor piezoeléctrico.

Luego se limpia la pantalla con lcd_clear() y se actualiza el contenido del display según el valor leído. Si la tensión medida es menor a 0.1 V, el programa interpreta que la baldosa no está siendo presionada o que el sensor está desconectado, mostrando en pantalla el mensaje “DESCONECTADO” junto con “V = 0.00V”. En caso contrario, se formatea el valor medido en una cadena de texto con dos decimales mediante snprintf(), y se imprime en la segunda línea del LCD precedido por el texto “Piezoelectrico:”.

Finalmente, se incluye una pausa de 100 milisegundos con sleep_ms(100) antes de repetir el ciclo, evitando parpadeos excesivos en la pantalla y permitiendo una actualización fluida y legible de los valores.

### 5.4. Librerías lcd.c y lcd.h

El conjunto de archivos lcd.c y lcd.h conforma una librería auxiliar encargada de manejar toda la comunicación con el display LCD mediante el bus I2C. En su implementación se encuentran funciones para enviar comandos, escribir caracteres o cadenas de texto y posicionar el cursor en pantalla.

La inicialización del display se realiza en modo de 4 bits, lo que permite enviar datos en dos mitades (nibbles) utilizando menos líneas. Además, se definen funciones de bajo nivel como i2c_write_byte() y lcd_toggle_enable() que garantizan la sincronización correcta entre la Pico y el controlador del display (habitualmente un PCF8574).

Durante la inicialización, también se cargan en la memoria del LCD caracteres personalizados, aunque en esta versión del código no se utilizan, ya que el objetivo principal es mostrar valores numéricos en formato de texto. La separación de esta librería respecto al archivo principal mejora la legibilidad del código y permite reutilizarla en otros proyectos sin modificaciones.

### 5.5. Archivo CMakeLists.txt

El archivo CMakeLists.txt actúa como el configurador del entorno de compilación. En él se indican los parámetros necesarios para construir el proyecto con el SDK de Raspberry Pi Pico. Se especifica el estándar del lenguaje, la versión del SDK, la placa objetivo (pico2_w) y las bibliotecas que deben vincularse al programa.

También se incluyen las dependencias de hardware necesarias (hardware_i2c y hardware_adc), y se agrega el subdirectorio de la librería LCD. Este archivo es interpretado por CMake para generar los scripts de compilación y enlazado que permiten crear el archivo ejecutable final que se carga en la placa.

### 5.6. Explicación del código por línea

5.6.1. pleper.c

#include "hardware/gpio.h"

Incluye el encabezado del SDK para controlar GPIO (configurar pines, funciones de pin, etc.).

#include "hardware/i2c.h"

Incluye el módulo de I2C del SDK (para inicializar el bus, fijar velocidad y mandar bytes).

#include "hardware/adc.h"

Incluye el módulo de ADC (convertidor analógico–digital) del RP2040.

#include "lcd.h"

Incluye la librería propia para manejar el LCD I2C (prototipos de funciones como lcd_init, lcd_string, etc.).

#include <stdio.h>

Incluye funciones estándar de C como snprintf para formatear cadenas.

#include "pico/stdlib.h"

Incluye utilidades generales del SDK de Pico (temporización como sleep_ms, inicializaciones, etc.).

#define GPIO_SDA 6

Define el pin GPIO6 para la línea SDA del bus I2C.

#define GPIO_SCL 7

Define el pin GPIO7 para la línea SCL del bus I2C.

#define ADC_PIN 26 // ADC0

Define GPIO26 como pin de entrada analógica; corresponde a ADC0.

#define ADC_MAX_VAL 4095.0f

Constante con el valor máximo del ADC (12 bits → 0..4095) en punto flotante.

#define VREF 3.3f

Define la tensión de referencia del ADC (3.3 V) usada para convertir conteos a voltios.

float R1 = 30000.0f; // ohms (arriba)

Variable con el valor de la resistencia superior del divisor (R1). Se usa para deshacer la atenuación.

float R2 = 10000.0f; // ohms (abajo)

Variable con el valor de la resistencia inferior del divisor (R2).

float calcular_voltaje_real() {

Declara la función que lee el ADC y devuelve el voltaje real antes del divisor.

adc_select_input(0);

Selecciona el canal ADC0 (GPIO26). Asegura que las lecturas provengan del canal correcto.

uint16_t raw = adc_read();

Ejecuta una conversión ADC y guarda el conteo (0..4095).

float v_adc = (raw / ADC_MAX_VAL) * VREF;

Convierte el conteo a voltios en el pin ADC: proporción del máximo por la referencia.

float v_real = v_adc * ((R1 + R2) / R2);

Deshace el divisor: multiplica por el factor ((R1+R2)/R2) para obtener el voltaje real en la salida del rectificador.

return v_real;

Devuelve el voltaje real (en V).

}

Cierre de la función calcular_voltaje_real.

int main() {

Punto de entrada del programa.

stdio_init_all();

Inicializa el subsystem stdio (útil si en el futuro se usa USB/UART para debug).

i2c_init(i2c1, 100000);

Inicializa el controlador I2C1 a 100 kHz (velocidad estándar).

gpio_set_function(GPIO_SDA, GPIO_FUNC_I2C);

Configura GPIO6 en función I2C para SDA.

gpio_set_function(GPIO_SCL, GPIO_FUNC_I2C);

Configura GPIO7 en función I2C para SCL.

gpio_pull_up(GPIO_SDA);

Activa pull-up interno en SDA (de todos modos suelen requerirse pull-ups externos en I2C).

gpio_pull_up(GPIO_SCL);

Activa pull-up interno en SCL.

lcd_init(i2c1, 0x27);

Inicializa el LCD usando el bus i2c1 y la dirección 0x27 (común en PCF8574).

adc_init();

Inicializa el ADC del RP2040.

adc_gpio_init(ADC_PIN);

Habilita el GPIO26 como entrada analógica para el ADC.

while (true) {

Comienza el bucle infinito de adquisición y visualización.

float v = calcular_voltaje_real();

Obtiene el voltaje real actual (después de compensar el divisor).

lcd_clear();

Limpia el LCD antes de escribir la nueva lectura (garantiza que no queden caracteres viejos).

if (v < 0.10f) {

Comprueba si la tensión es muy baja (umbral de 0.10 V); se interpreta como sin pisada o desconectado.
lcd_set_cursor(0, 0);

Posiciona el cursor en línea 0, columna 0.
lcd_string("DESCONECTADO");

Muestra el estado “DESCONECTADO” (sin pulso válido).
lcd_set_cursor(1, 0);

Posiciona el cursor en línea 1, columna 0.
lcd_string("V = 0.00V");

Escribe una lectura fija de 0.00 V para claridad visual.
}

Fin del bloque if.

## else {

Caso contrario: hay tensión válida a mostrar.
char buffer[16];

Reserva un buffer para formatear el texto de la segunda línea.
lcd_set_cursor(0, 0);

Posiciona cursor en línea 0, columna 0.
lcd_string("Piezoelectrico:");

Escribe el título de la medición en la primera línea.
snprintf(buffer, sizeof(buffer), "V= %.2fV ", v);

Formatea el valor en volts con 2 decimales. Los espacios extra al final barren residuos en la línea.
lcd_set_cursor(1, 0);

Posiciona el cursor en línea 1, columna 0.
lcd_string(buffer);

Escribe el valor de tensión recién formateado.
}

Cierra el else.
sleep_ms(100);

Pausa 100 ms para una tasa de actualización ≈ 10 Hz y evitar parpadeos.
}

Cierra el bucle infinito.
}

Fin de main.

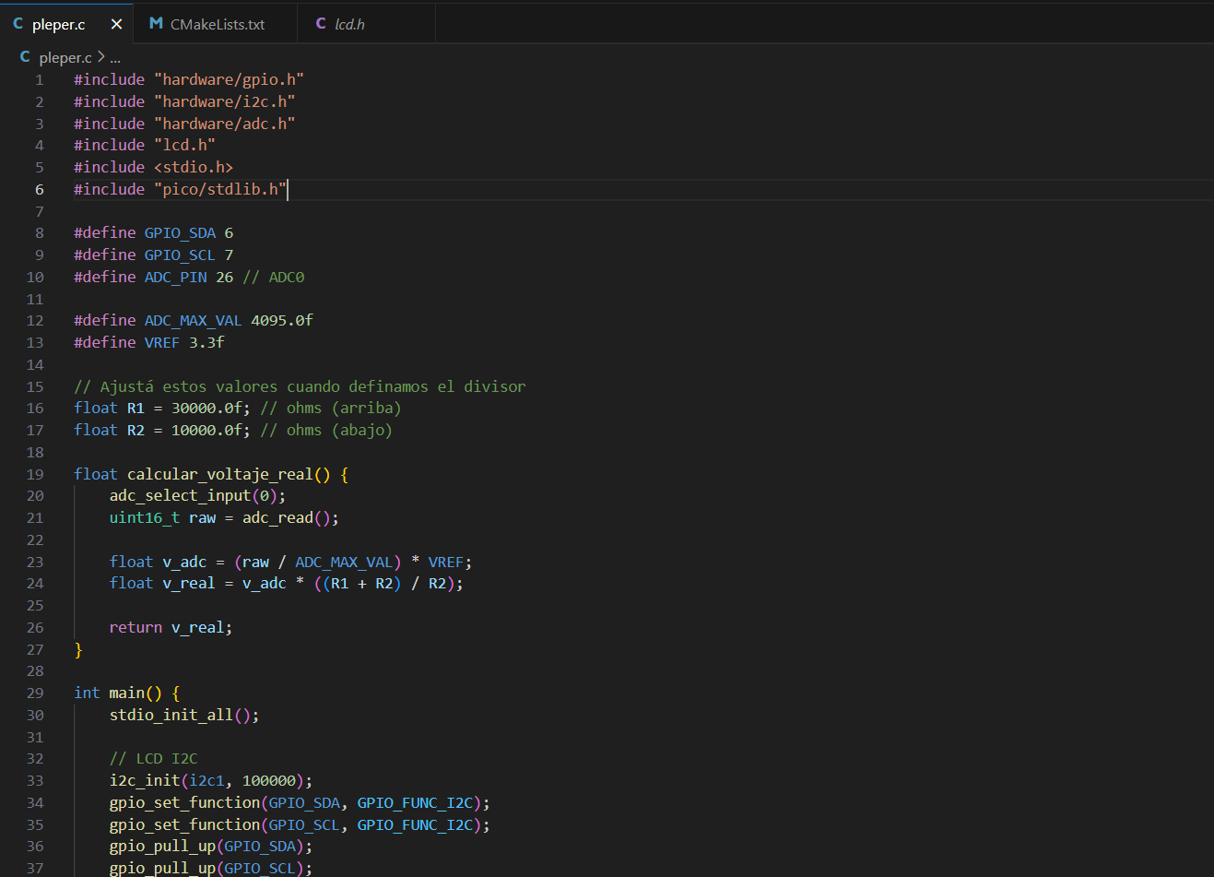
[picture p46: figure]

Figura 36: Captura de código de pleper.c

5.6.2. CMakeLists.txt

## # Generated Cmake Pico project file

Comentario informativo generado por la plantilla/IDE.

## cmake_minimum_required(VERSION 3.13)

Indica la versión mínima de CMake requerida para procesar este proyecto.

## set(CMAKE_C_STANDARD 11)

Fija el estándar de C a C11.

## set(CMAKE_CXX_STANDARD 17)

Fija el estándar de C++ a C++17 (aunque no se use C++ en este proyecto, queda definido).

## set(CMAKE_EXPORT_COMPILE_COMMANDS ON)

Genera compile_commands.json (útil para herramientas de análisis/IDE).

## if(WIN32)

## set(USERHOME $ENV{USERPROFILE})

## else()

## set(USERHOME $ENV{HOME})

## endif()

Detecta el home del usuario de forma portable (Windows vs. Unix-like).

## set(sdkVersion 2.2.0)

## set(toolchainVersion 14_2_Rel1)

## set(picotoolVersion 2.2.0-a4)

Variables usadas por la extensión de VS Code para sincronizar versiones.

## set(picoVscode ${USERHOME}/.pico-sdk/cmake/pico-vscode.cmake)

## if (EXISTS ${picoVscode})

## include(${picoVscode})

## endif()

Incluye utilidades de pico-vscode si están presentes (integración IDE).

## set(PICO_BOARD pico2_w CACHE STRING "Board type")

Define la placa objetivo como pico2_w y lo guarda en caché CMake.

## include(pico_sdk_import.cmake)

Importa el SDK de Pico (ruta establecida por variables/entorno).

## project(pleper C CXX ASM)

Declara el proyecto pleper y los lenguajes usados (C, C++, ASM).

## pico_sdk_init()

Inicializa variables y rutas del Pico SDK para el build.

## add_executable(pleper pleper.c )

Crea el ejecutable pleper con la fuente principal pleper.c.

## pico_set_program_name(pleper "pleper")

Asigna el nombre de programa (metadatos) al binario.

## pico_set_program_version(pleper "0.1")

Define la versión del programa.

## pico_enable_stdio_uart(pleper 0)

Desactiva la salida UART para stdio (0 = off).

## pico_enable_stdio_usb(pleper 0)

Desactiva la salida USB para stdio. (Se usa solo LCD en este proyecto.)

## target_link_libraries(pleper

## pico_stdlib)

Enlaza contra la librería estándar del Pico SDK.

## target_include_directories(pleper PRIVATE

## ${CMAKE_CURRENT_LIST_DIR}

)

Agrega el directorio actual a los includes del compilador para este target.

## target_link_libraries(pleper

## hardware_i2c

## hardware_adc

)

Enlaza las librerías de hardware I2C y hardware ADC requeridas.

## pico_add_extra_outputs(pleper)

Genera artefactos extra: UF2, ELF, bin, mapa, etc.

## add_subdirectory(lcd)

Incluye el subproyecto de la librería LCD ubicado en el directorio lcd/.

## target_link_libraries(${PROJECT_NAME} lcd)

Enlaza el ejecutable principal con la librería lcd creada en lcd/.

Figura 37: Captura de código de CMakeLists.txt

5.6.3. lcd.c

## #include "lcd.h"

Incluye los prototipos y constantes del driver LCD.
static i2c_inst_t *lcd_i2c;

Puntero estático al controlador I2C que usará el LCD (i2c0 o i2c1).
static uint8_t addr;

Guarda la dirección I2C de 7 bits del módulo LCD (p.ej., 0x27).

## static uint8_t barra_completa[8] =

{0x1F,0x1F,0x1F,0x1F,0x1F,0x1F,0x1F,0x1F};

## static uint8_t barra_vacia[8] =

{0x00,0x00,0x00,0x00,0x00,0x00,0x00,0x00};

Define dos caracteres personalizados (CGRAM) para barra llena/vacía (no se usan en esta versión, pero quedan disponibles).

## void lcd_create_char(uint8_t location, uint8_t charmap[]) {

location &= 0x7;
lcd_send_byte(LCD_SETCGRAMADDR | (location << 3), LCD_COMMAND);

## for (int i = 0; i < 8; i++) {

lcd_send_byte(charmap[i], LCD_CHARACTER);
}
}

Crea un carácter personalizado en la CGRAM del LCD; location 0..7. Envía dirección base y los 8 bytes de la matriz de puntos.

## void i2c_write_byte(uint8_t val) {

i2c_write_blocking(lcd_i2c, addr, &val, 1, false);
}

Envía un byte por I2C (bloqueante) a la dirección del LCD/expansor.

## void lcd_toggle_enable(uint8_t val) {

## #define DELAY_US 600

sleep_us(DELAY_US);
i2c_write_byte(val | LCD_ENABLE_BIT);
sleep_us(DELAY_US);
i2c_write_byte(val & ~LCD_ENABLE_BIT); sleep_us(DELAY_US);
}

Genera el pulso de Enable (E) requerido por el LCD paralelo. Se agrega delay para cumplir tiempos mínimos.

## void lcd_send_byte(uint8_t val, int mode) {

uint8_t high = mode | (val & 0xF0) | LCD_BACKLIGHT;
uint8_t low = mode | ((val << 4) & 0xF0) | LCD_BACKLIGHT;
i2c_write_byte(high);
lcd_toggle_enable(high);

i2c_write_byte(low);
lcd_toggle_enable(low);
}

Envía un byte al LCD en 4 bits (alto y bajo). mode selecciona comando o dato. Mantiene el backlight encendido y conmuta E en cada nibble.

## void lcd_clear(void) {

lcd_send_byte(LCD_CLEARDISPLAY, LCD_COMMAND);
}

Manda el comando de limpiar la DDRAM y volver el cursor al inicio.

## void lcd_set_cursor(int line, int position) {

int line_offsets[] = { 0x00, 0x40, 0x14, 0x54 };
int val = 0x80 + line_offsets[line] + position;
lcd_send_byte(val, LCD_COMMAND);
}

Posiciona el cursor en la línea (0..3 según mapeo interno) y columna indicada; el valor final se envía como comando SETDDRAMADDR.

## void lcd_char(char val) {

lcd_send_byte(val, LCD_CHARACTER);
}

Escribe un carácter (dato) en la posición actual.

## void lcd_string(const char *s) {

## while (*s) {

lcd_char(*s++);
}
}

Escribe una cadena completa carácter por carácter.

## void lcd_init(i2c_inst_t *i2c, uint8_t address) {

lcd_i2c = i2c;

addr = address;
lcd_send_byte(0x03, LCD_COMMAND); lcd_send_byte(0x03, LCD_COMMAND); lcd_send_byte(0x03, LCD_COMMAND); lcd_send_byte(0x02, LCD_COMMAND);
lcd_send_byte(LCD_ENTRYMODESET | LCD_ENTRYLEFT,
LCD_COMMAND);
lcd_send_byte(LCD_FUNCTIONSET | LCD_2LINE, LCD_COMMAND);
lcd_send_byte(LCD_DISPLAYCONTROL | LCD_DISPLAYON,
LCD_COMMAND);
lcd_create_char(0, barra_completa);
lcd_create_char(1, barra_vacia);
lcd_clear();
}

Inicializa el modo 4 bits del LCD (secuencia estándar 0x03 x3 y 0x02). Configura dirección de entrada, número de líneas, display ON, y carga caracteres personalizados 0 y 1. Limpia la pantalla al final.

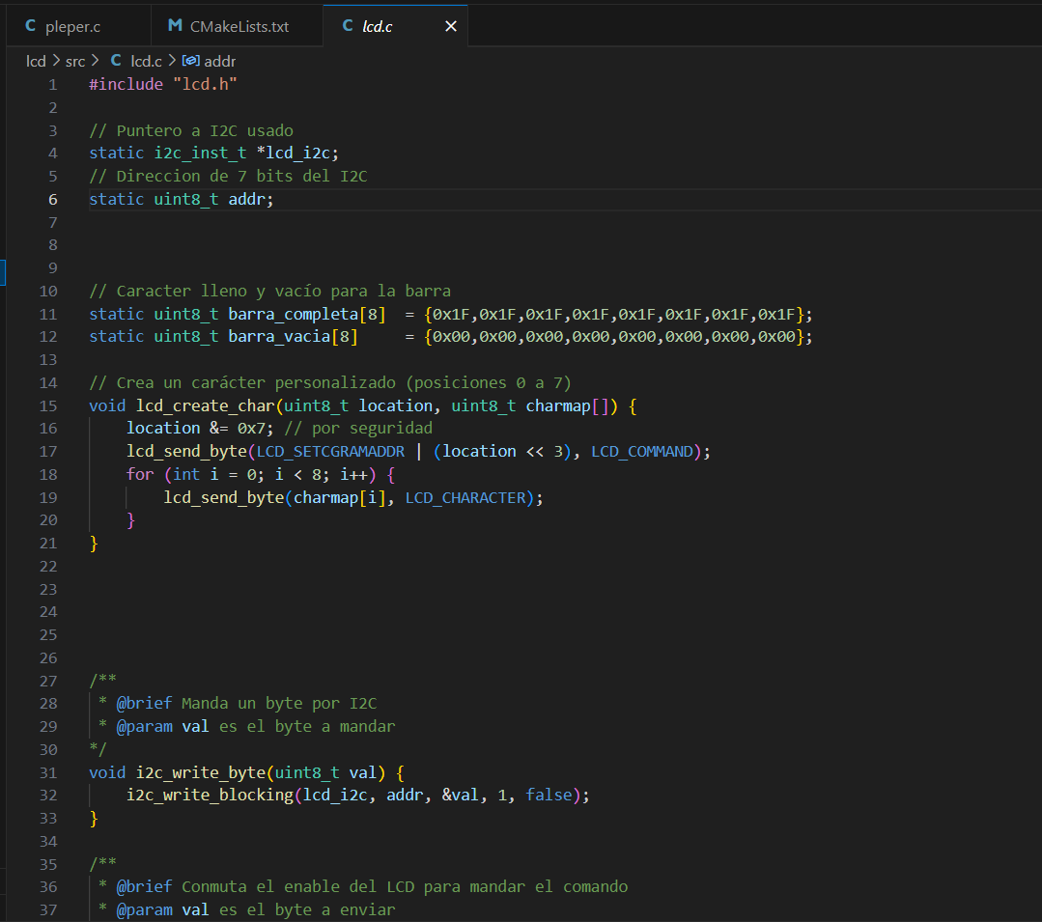
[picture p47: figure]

Figura 38: Captura de código de lcd.c

5.6.4. lcd.h

## #include <stdio.h>

## #include "pico/stdlib.h"

## #include "hardware/i2c.h"

Incluye dependencias estándar, temporización del Pico y tipos/funciones de I2C necesarios por el header.

## #define LCD_CLEARDISPLAY 0x01

## #define LCD_RETURNHOME 0x02

## #define LCD_ENTRYMODESET 0x04

## #define LCD_DISPLAYCONTROL 0x08

## #define LCD_CURSORSHIFT 0x10

## #define LCD_FUNCTIONSET 0x20

## #define LCD_SETCGRAMADDR 0x40

## #define LCD_SETDDRAMADDR 0x80

Constantes de comandos base del controlador de LCD compatibles con HD44780.

## #define LCD_ENTRYSHIFTINCREMENT 0x01

## #define LCD_ENTRYLEFT 0x02

Flags del modo de entrada: desplazamiento automático e ingreso izquierda-a-derecha.

## #define LCD_BLINKON 0x01

## #define LCD_CURSORON 0x02

## #define LCD_DISPLAYON 0x04

Flags de control de display: parpadeo, cursor visible y encendido del display.

## #define LCD_MOVERIGHT 0x04

## #define LCD_DISPLAYMOVE 0x08

Flags para desplazar el display/cursor a derecha.

## #define LCD_5x10DOTS 0x04

## #define LCD_2LINE 0x08

## #define LCD_8BITMODE 0x10

Flags de seteo de función: tamaño de la matriz de puntos, líneas y modo 8 bits (aquí operamos en 4 bits, por eso no se usa ese flag).

## #define LCD_BACKLIGHT 0x08

Bit que controla el backlight a través del expansor I2C (PCF8574 mapea ese bit a la línea de luz).

## #define LCD_ENABLE_BIT 0x04

Bit que se usa para conmutar E (Enable) del LCD.

## #define LCD_CHARACTER 1

## #define LCD_COMMAND 0

Constantes para indicar a lcd_send_byte si enviamos dato (carácter) o comando.

## #define MAX_LINES 2

## #define MAX_CHARS 16

Dimensiones lógicas del LCD 16x2 usadas como referencia.
void i2c_write_byte(uint8_t val);
void lcd_toggle_enable(uint8_t val);
void lcd_send_byte(uint8_t val, int mode);
void lcd_clear(void);
void lcd_set_cursor(int line, int position); void lcd_char(char val);
void lcd_string(const char *s);
void lcd_init(i2c_inst_t *i2c, uint8_t address);

Prototipos de todas las funciones públicas del driver LCD.

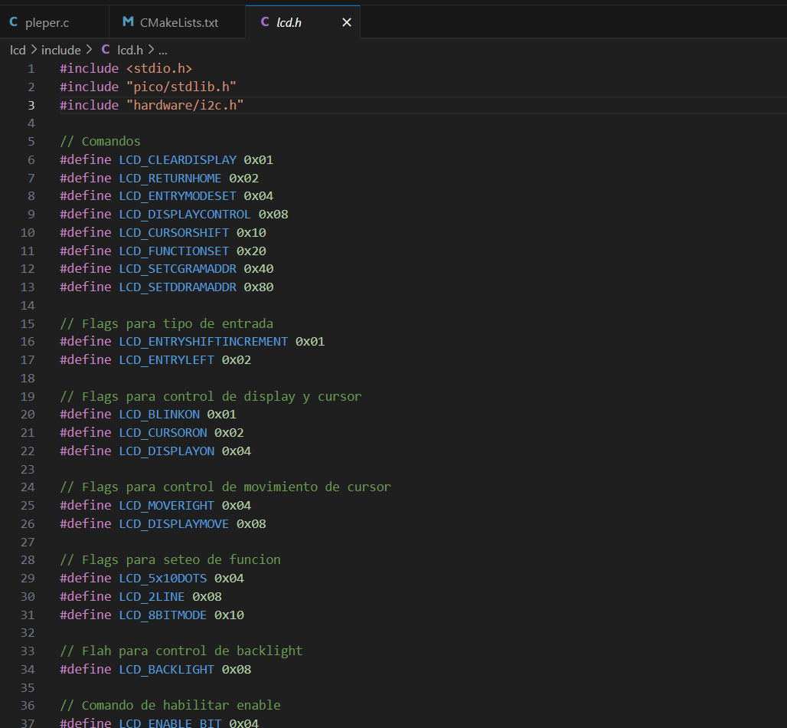
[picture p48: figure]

Figura 39: Captura de código de lcd.h

## 6. Anexo

### 6.1. Biblografía

Para el desarrollo de nuestro proyecto se han considerado las siguientes referencias:

- Análisis comparativo del nivel de energía eléctrica producida por baldosas piezoeléctricas en función de su forma geométrica (https://github.com/impatrq/Pleper/blob/main/Documentos%20Proyecto/Material/An%C3%A1lisis%20comparativo%20del%20nivel%20de%20energ%C3%ADa%20el%C3%A9ctrica%20pr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)
- Aplicaciones del efecto piezoeléctrico para la generación de energía (https://github.com/impatrq/Pleper/blob/main/Documentos%20Proyecto/Material/Aplicaciones%20del%20efecto%20piezoel%C3%A9ctrico%20para%20la%20generaci%C3%B3n%20d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)
- Articulo cientifico Proyecto de grado piezoelectricos en perfil vial piloto en Bogotá (https://github.com/impatrq/Pleper/blob/main/Documentos%20Proyecto/Material/Articulo%20cientifico%20Proyecto%20de%20grado%20piezoelectricos%20en%20perfil%20via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)
- Baldosa Piezoeléctrica para alimentar sistemas de iluminación de bajo consumo energético (https://github.com/impatrq/Pleper/blob/main/Documentos%20Proyecto/Material/Baldosa%20Piezoel%C3%A9ctrica%20para%20alimentar%20sistemas%20de%20iluminaci%C3%B3n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)
- Desarrollo de un prototipo de baldosa generadora de energía eléctrica a partir de la piezoelectricidad y almacenamiento de la energía producida (https://github.com/impatrq/Pleper/blob/main/Documentos%20Proyecto/Material/Desarrollo%20de%20un%20prototipo%20de%20baldosa%20generadora%20de%20energ%C3%ADa%20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)

- Diseño de un prototipo para generación energética mediante tecnología piezoeléctrica (https://github.com/impatrq/Pleper/blob/main/Documentos%20Proyecto/Material/Dise%C3%B1o%20de%20un%20prototipo%20para%20generaci%C3%B3n%20energ%C3%A9tica%20medi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)
- Diseño e Implementación de un Prototipo Portable de Generación Piezoeléctrica (https://github.com/impatrq/Pleper/blob/main/Documentos%20Proyecto/Material/Dise%C3%B1o%20e%20Implementaci%C3%B3n%20de%20un%20Prototipo%20Portable%20de%20Gener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)
- Diseño en implementación de un generador piezoeléctrico baldosa, para alimentar un sistema de iluminación de baja potencia (https://github.com/impatrq/Pleper/blob/main/Documentos%20Proyecto/Material/Dise%C3%B1o%20en%20implementaci%C3%B3n%20de%20un%20generador%20piezoel%C3%A9ctrico%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)
- FOOTSTEP POWER GENERATION USING PIEZOELECTRIC PLATE (https://github.com/impatrq/Pleper/blob/main/Documentos%20Proyecto/Material/FOOTSTEP%20POWER%20GENERATION%20USING%20PIEZOELECTRIC%20PLATE.pdf)
- Generación de Energía Eléctrica Limpia mediante Baldosas Piezoeléctricas (https://github.com/impatrq/Pleper/blob/main/Documentos%20Proyecto/Material/Generaci%C3%B3n%20de%20Energ%C3%ADa%20El%C3%A9ctrica%20Limpia%20mediante%20Baldosas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)
- Materiales Piezoeléctricos Calculo y Simulación del Circuito Equivalente de un Cristal de Cuarzo (https://github.com/impatrq/Pleper/blob/main/Documentos%20Proyecto/Material/Materiales%20Piezoel%C3%A9ctricos%20Calculo%20y%20Simulaci%C3%B3n%20del%20Circuito%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)
- Piezoelectric Effect Smart roads in green energy (https://github.com/impatrq/Pleper/blob/main/Documentos%20Proyecto/Material/Piezoelectric%20Effect%20Smart%20roads%20in%20green%20energy.pdf)
- Piezoelectric Footstep Power Generation (https://github.com/impatrq/Pleper/blob/main/Documentos%20Proyecto/Material/Piezoelectric%20Footstep%20Power%20Generation.pdf)
- Proyecto de Diseño de un Sistema de Baldosas Piezoeléctricas en un Gran Centro Comercial (https://github.com/impatrq/Pleper/blob/main/Documentos%20Proyecto/Material/Proyecto%20de%20Dise%C3%B1o%20de%20un%20Sistema%20de%20Baldosas%20Piezoel%C3%A9ctri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)
- Transductores Piezoeléctricos aplicados a la Generación de Energía (ESTUDIO EXPERIMENTAL) (https://github.com/impatrq/Pleper/blob/main/Documentos%20Proyecto/Material/Transductores%20Piezoel%C3%A9ctricos%20aplicados%20a%20la%20Generaci%C3%B3n%20de%20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)

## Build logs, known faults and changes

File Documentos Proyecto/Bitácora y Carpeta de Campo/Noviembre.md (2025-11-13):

# 🗓️ Bitácora - Noviembre 2025

## 📅 1️⃣ Semana (Lunes 3 - Viernes 7)
-  Mauricio Blasco: Esta semana me contacte con una carpinteria para poder obtener una madera de medidas de 42x42, ademas de conseguir la caja de madera la cual posteriormente tuvimos que modificar. Me encargue de arreglar el video de presentacion, grabando las ultimas partes y corrigiendo los ultimos errores ademas de diseña cambios en el guion. Por ultimo nos sacamos la foto grupal del proyecto y ayude a redactar la parte de la estructura de la carpeta tecnica.

- Santiago Tejeda: Me encargué de conseguir la placa de madera de pino de 42x42 que sería la base de la segunda baldosa. También estuve armando la segunda baldosa que a comparación de la primera va a tener una conexión en serie a modo de sumar sus tensiones pico, al ser de 16 piezoeléctricos armé 4 grupos en serie, que luego de sus conexiones fueron a una nueva placa rectificadora de 4 borneras y  de salida. Llegó a generar unos picos de 15V en su salida común.

---

## 📅 2️⃣ Semana (Lunes 10 - Viernes 14)
-  Mauricio Blasco: Diseñe el folleto que entregaremos en la muestra, tambien diseñe y contacte una empresa para poder elaborar las remeras del proyecto. Me encargue de la impresion de los folletos y de las tarjetas que entregaremos el dia de la muestra. Me comunique con autogomas bernal para poder obtener nuevamente su apoyo obteniendo una alfombra de caucho de 70x140.

- Santiago Tejeda: Estuve probando las conexiones de las baldosas entre sí. Ayudé con el armado de la estructura para la exposición, ya que tuvimos problemas para colocar la caja de placas sobre el tubo PVC, también con la alimentación de la raspberry pi 2w que solucionamos alimentandola con un powerbank royalcell.

---

## 📅 3️⃣ Semana (Lunes 17 - Viernes 21)

---

## 📅 4️⃣ Semana (Lunes 24 - Viernes 28)

---

🧾 **Observaciones generales del mes:**  
-  
-

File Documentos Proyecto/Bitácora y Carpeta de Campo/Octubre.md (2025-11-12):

# 🗓️ Bitácora - Octubre 2025

## 📅 1️⃣ Semana (Lunes 29 - Viernes 3)

-  Santiago Tejeda: esta semana me dediqué a corroborar por qué los pulsos de la baldosa no llegaban a cargar el banco de capacitores, dentro de todas las razones una de las que me cuestioné era la falta de un capacitor de filtrado en la salida de la placa reciticadora, conectada en parallo, siendo esta conectada en paralelo, pero luego al probarlo en la baldosa dejó de dar tensión a la salida. Lo que terminó en tener que desoldarlo y optar por otra solución.

-  Mauricio Blasco: Diseñe las publicaciones de Instagram de la palca rectificadora y el banco de capacitores, además de diseñar la portada triple de la publicación en Canva. También diseñe el modelo 3d de los topes en Autocad y los pase al formato para imprimirlos en el CURA. Soldé los componentes que adquirimos en la placa rectificadora anteriormente hecha.

-  Victor Raul Broncano: Probe la continuidad del banco de capacitores, agujerie la placa y solde los componentes. Armamos la estractura de la baldosa, comprobando su resitencia y como reacciona con las personas caminando por encima.

---

## 📅 2️⃣ Semana (Lunes 6 - Viernes 10)

-  Santiago Tejeda: esta semana me dediqué a buscar el motivo por el cuál el banco de capacitores no cargaba. Llegué a la conclusión de que la constante de tiempo del capacitor de almacenamiento principal (10,000µF) excede en dos órdenes de magnitud la duración del pulso piezoeléctrico (20ms), resultando en una eficiencia de captura menor al 5%. Para resolver esto, se implementó un sistema de dos etapas capacitivas con un capacitor de acoplamiento (470µF) que presenta una constante de tiempo compatible con la duración del pulso. Denominandola "circuito de bombeo de carga capacitiva".

-  Mauricio Blasco: Esta semana complete el borde de caucho que cubre los costados de la baldosa, además de hacer un corte para que pasen los cables e intentar pegar con cemento de contacto la alfombra antideslizante a la baldosa, lo cual fracasamos ya que estaba ya seco el cemento de contacto, por lo que la despegamos.

- Victor Raul Broncano: Ir a comprar al Easy el tubo de PVC y recortarlo para facilitar su transporte. También contactar con Elemon e ir a su sede en Villa Urquiza para la abonacion de distintos componentes.

---

## 📅 3️⃣ Semana (Lunes 13 - Viernes 17)

-  Santiago Tejeda: esta semana me dediqué a desoldar los pines macho-macho de la Raspberry Pico W, que estaban soldados al revés, aprovechando que teníamos las prácticas profesionlizantes en Newton SRL, nos brindaron uso de su equipo de microscopios y capacitación para soldar/desoldar estaño de la forma correcta, que me facilitó la operación. Luego empecé a investigar sobre los componentes para el prototipado del nuevo circuito de retroalimentación de bombeo de carga capacitiva.

-  Mauricio Blasco: Esta semana me encargue de medir la tensión tanto en la salida del circuito como en la salida de los grupos de piezoeléctricos, midiendo con uno, dos, tres y cuatro topes en un grupo y con un tope en cada esquina.

-  Ignacio Garcia: Esta semana empece con el codigo del proyecto. El mismo se encargaria de mostrar el porcentaje de carga del capacitor en un display LCD (con i2c incluido) y, ademas, mediante el uso de una pagina web las personas podrian ver en sus dispositivos como se carga en tiempo real el capacitor. La idea de esta semana es probar la parte del codigo para el display con el lenguaje de programacion Python. Actualizacion: El codigo llego a funcionar pero, al usar una raspberry pi pico 2W, no leia bien la informacion que le llegaba y por lo tranto no se mostraba lo que buscaba en el display. La proxima semana continuo con el codigo, pero ahora con el uso de la extension de VScode, conocida como Platformio.

- Victor Raul Broncano: Compra de segundo tacho de cemento de contacto, recorte y pegado de la alfombra que recubre la baldosa de caucho y la base de madera.  

---

## 📅 4️⃣ Semana (Lunes 20 - Viernes 24)

-  Santiago Tejeda: esta semana me dedique a investigar sobre el armado del circuito de retroalimentación para solucionar el problema de que los pulsos de la baldosa no logran ser captados por el banco de capacitores, ya que al tener una alta capacitancia y el tener un pulso de tan corto tiempo (20ms) los capacitores no logran captarlo. La solución que encontré fue una implementación de un circuito de bombeo de carga capacitiva que utiliza un capacitor pre-cargado como colchón de voltaje para maximizar la eficiencia en la captura de pulos piezoeléctricos. Logré armar el prototipo del circuito que, lentamente, carga el capacitor de 470 uF el cual proporciona la base de voltaje que posteriormente se le van a sumar el de los pulsos y así cargar el capacitor de 10.000uF, el cual daría por finalizado la etapa de carga de la baldosa. (Actualización) La etapa no terminó funcionano por falta de potencia de los pulsos, por lo que nunca iban a llegar a cargar el capacitor de 10.000 uF, por lo que decidimos en tratar de armar otra baldosa cambiando la configuración del cableado, en vez de todos en paralelo para mayor corriente, lo cambiamos a todos en serie para sumar pico de voltaje útil.

-  Mauricio Blasco: Esta semana me encargue de medir el tiempo de los pulsos generado por los piezoeléctricos con el objetivo de saber si el problema de la carga de los capacitores podría ser por la corta duración de estos, lo cual terminamos confirmando. También me encargue de comprar algunos componentes que requeríamos para seguir avanzando, los cuales eran 2 resistencias de 4,7 Mohm y dos tiras de 40 pines. Tambien medí la corriente en la salida del circuito tanto sin topes como con uno, dos, tres y cuatro topes. Por ultimo actualize con algunas mejoras el banner del proyecto para luego enviarlo.

-  Ignacio Garcia: Esta semana, como comente anteriormente, continue con el codigo pero ahora con el uso de la extension de VScode conocida como Platformio. Probe de la misma manera que con Python (primero hacer que funcione la parte del codigo del display) pero otra vez no tuve exito debido a que Platformio no funcionaba con Raspberrys pi picos Wifi (solo con raspberry pi pico y ahi). Es por eso que pase el codigo a C (mediante una extension de raspberry pi pico en VScode) y ahi empezo a funcionar. Ahora faltaria hacer la parte web del codigo.

- Victor Raul Broncano: Compra y lijado de grampas para mantener el fijo verticalmente el tubo de PVC. En este tubo van a pasar los cables que iran dirigido a la caja de placas. Tambien repare las conexiones desoldadas de los sensores piezoelectricos

- Victoria Josefina Baza: Esta semana ayudé a medir el tiempo de los pulsos generados por los piezoeléctricos. También diseñe modelos 3D de los PCB de las placas que habíamos hecho; la placa de rectificación y la placa de filtrado para poder visualizarlas en FreeCAD, y mostrar una vista conceptual de las mismas.

---

## 📅 5️⃣ Semana (Lunes 27 - Viernes 31)

-  Mauricio Blasco: Me encargue del pensado, diseño, edicion y guionado del proyecto, ademas de diseñar el STL para poder imprimir los 16 topes necesarios, despues los imprimios en el colegio. Me contacte con Tasker Consultores para poder obtener su ayuda para obtener un cartel de emergencia que requeriamos. Me encargue tambien de la grabacion de videos que utilizariamos posteriormente para el video.
-  Victoria Josefina Baza: Esta semana estuve trabajando en el Manual de Usuario, estuve recopilando la información necesaría para poder completarlo según los requisitos que se pedían. Me enfoqué en lo que corresponde a la instalación de la baldosa y su manipulación, ya que como tal no es necesario utilizar una aplicación para visualizar el funcionamiento de la baldosa. Terminé la documentación y la envié el Viernes 31. También estuve diseñando la baldosa en AutoCAD para tener una vista conceptual del diseño de esta, respetando las medidas originales para poder completar las documentaciones y utilizar las vistas de manera didáctica. Por eso saqué también las capturas de pantalla de la baldosa para poder agregarlas a la documentación. Tambien ayude con la grabacion de videos posteriormente utilizados en el video, y grabe el inicio y final del este mismo.

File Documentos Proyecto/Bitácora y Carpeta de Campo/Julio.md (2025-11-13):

# 🗓️ Bitácora - JULIO 2025

## 📅 1️⃣ Semana (Lunes 3 - Viernes 7)

- Santiago Tejeda: Me encargué de comprar herramientas para poder trabajar con el proyecto junto a la investigación de la etapa rectificadora de la baldosa piezoeléctrica.

---

## 📅 2️⃣ Semana (Lunes 10 - Viernes 14)

- Santiago Tejeda: Me dediqué a el prototipado de la etapa rectificadora junto a los sensores, midiendo con un osciloscopio su correcto funcionamiento. Primero probé un puente rectificador de onda completa con diodos 1N4007 que al tener mucha caida de tensión habían más pérdidas que tensión generada, por lo que opté por usar los diodos schottky 1n5819 que tienen una caída mucho menor, siendo esta de 0,3V.

---

## 📅 3️⃣ Semana (Lunes 18 - Viernes 22)
VACACIONES DE INVIERNO

---

## 📅 4️⃣ Semana (Lunes 25 - Viernes 29)
VACACIONES DE INVIERNO

---

🧾 **Observaciones generales del mes:**  
-  
-

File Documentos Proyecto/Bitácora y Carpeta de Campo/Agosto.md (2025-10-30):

# 🗓️ Bitácora - Agosto 2025

## 📅 1️⃣ Semana (Lunes 4 - Viernes 8)

-  Santiago Tejeda: Esta semana me encargué de investigar qué método de almacenamiento iba a ser el más adecuado para almacenar los pulsos generados por la baldosa. Primero pensamos en utilizar baterías de litio pero no tenía mucho sentido utilizar una batería de litio para cargar otra batería de litio así que seguimos investigando.

-  Isidro Stabile: Esta semana hice mediciones y corte la placa de caucho que compramos para avanzar con la estrucutura.

-  Victor Raul Broncano: Medidas y recorte del caucho que va a ser la baldosa. Esta baldosa la recotamos a una medida de 42cm*42cm ya que va a ir junto a una madera de la misma medida.

-  Maurcio Blasco: comienzo a diseñar un modelo 3D en autocad del diseño de la baldosa en el moemento, diseñando de la forma mas eficiente la estructura.
---

## 📅 2️⃣ Semana (Lunes 11 - Viernes 15)

-  Santiago Tejeda: Pensamos en utilizar una batería de plomo ácido ya que parecía la opción más clara para el almacenamiento. Entonces nos pusimos a buscar posibles sponsors para conseguir la batería ya que comprar una por cuenta propia iba a ser muy costoso. Investigando nos dimos cuenta que iba a necesitar un control de carga para proteger la batería y su vida útil. Teniendo en cuenta en el problema que nos metiamos optamos por elegir otro método de almacenamiento.

-  Isidro Stabile: Me comunique con Elemon, siguiendo la conversación que teniamos, y contacte con otras empresas y distruibuidoras de electronica para conseguir componentes.

-  Victor Raul Broncano: calculo y colocacion de piezoelectricos. Tambien relice mediciones y pruebas con los resortes probando como se comporta con el peso de una persona. Estas mediciones las realizamos poniendo los cuatro resortes abajo de la madera que va a ser la baldosa.
-  Mauricio Blasco: ternino de diseñar el modelo 3D de la baldosa en autocad, ademas de agregarle las texturas con el objetivo de hacerlo mas realista.
---

## 📅 3️⃣ Semana (Lunes 18 - Viernes 22)

-  Santiago Tejeda: El método que optamos por elegir fue el de fabricar un banco de capacitores que me permita almacenar los pulso de los piezoelectricos, por lo que me dediqué a investigar los valores posibles de capacitancia que iba a necesitar para armarlo, ya que primero pesamos en usar un supercapacior de 1 Faradio pero estos mismos son muy costosos y llegué a la conclusión de que podía usar uno de menor valor.

- Isidro Stabile: Esta semana comenze con el armado y corte de unos "tacones" o bases para los discos piezoelectricos, que sirven para que llegen a deformarse cuando hay pisadas.

- Victor Raul Broncano: Medidas para la colocacion y corte de las bases de cauchos para los sensores piezoelectricos. Estos permiten que, cuando una persona pise la placa, los sensores lleguen a tener contacto con la baldosa.

- Mauricio Blasco: Investigue que medidas de resortes requeriamos para el correcto funcionamiento del circuito, y contacte con Resortecnica en busca de ayuda con informacion sobre los resortes.
---

## 📅 4️⃣ Semana (Lunes 25 - Viernes 29)

-  Santiago Tejeda: Investigué los valores posibles para el banco de capacitores, ya que tenia que estar dentro del presupuesto y tenía que ser de óptimo funcionamiento, así gracias al pañol de aviónica que nos brindó 4 capacitores de 10.000 uF pudé crear la placa de almacenamiento, que serían los 4 capacitores en paralelo con 2 borneras, una de entrada y otra de salida.

-  Isidro Stabile: Esta semana perfeccione los contornos del caucho, y los agujeros para que puedan pasar mejor los topes impresos en 3D.

- Victor Raul Broncano: Lijado de los costados de la baldosa de caucho y de la baldosa de madera. Tambien realice mediciones para realizar las perforaciones en donde van a ir los topes en donde van a ir los resorte y mantiene las badosas alinenadas con la base de madera.
-  Mauricio Blasco: Me encargue de ralizar mediciones sobre como altera a la trensión y a la corriente las diferentes superficies de los piezoelectricos. 
---

🧾 **Observaciones generales del mes:**  
-  
-

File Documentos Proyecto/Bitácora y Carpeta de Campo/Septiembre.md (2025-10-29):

# 🗓️ Bitácora - Septiembre 2025

## 📅 1️⃣ Semana (Lunes 1 - Viernes 5)

-  Santiag Tejeda: Esta semana me encargué de armar un boceto a modo de guía en formato de diagrama en bloques dividiendo en etapas el proyecto, para así tener una visión más general y poder saber qué prioridades tenemos que tener en cuenta para el correcto avance del proyecto.
  
-  Isidro Stabile: Esta semana estuve actualizando la bitacora a lo largo de Agosto. Tambien estuve nuevamente contactando con Elemon, para ya acordar el listado de componentes que queremos tener bonificados, ademas de haber actualizado al dia de la fecha el tablero de Trello, con las tareas que hicimos.

-  Victor Raul Broncano: Obtencion del cemento de contacto para adherir los elementos de la estructura. Tambien nos comunicamos con Elemon, sobre el abono de componentes y elementos de trabajo.

---

## 📅 2️⃣ Semana (Lunes 8 - Viernes 12)

-  Santiago Tejeda: Esta semana me encargue de pensar la estructura del proyecto, especificamente el armado a nivel de funcionamiento, llegué a la conclusión de que ibamos a necesitar unos resortes para generar un mecanismo de suspensión para que la baldosa pueda ser pisada y esta fuerza sea transmitida a los sensores piezoeléctricos.

-  Victor Raul Broncano:  Perforar la base de madera de la estructura en donde ban a ir los colocados los sensores piezoelectricos. Y tambien pegamos las dos partes de la baldosa, la de madera con la de caucho, haciendo que coincidan las perforaciones de ambas partes.

---

## 📅 3️⃣ Semana (Lunes 15 - Viernes 19)

-  Mauricio Blasco: fuimos al local de zona electo para comunicarnos en busca de apoyo. También realice el diseño en pcb y el esquemático de la placa de capacitores, el cual imprimimos posteriormente. Hicimos una recorrida por el centro en la búsqueda de sponsors, además de comprar placa de cobre.

-  Santiago Tejeda: Esta semana continué pensando en cómo sería la estructura de la baldosa, llegando a la conclusión de que el sistema de suspensión debía incorporar un mecanismo que permitiera pisarla y generar movimiento, pero que al mismo tiempo pudiera volver a su posición original.
Con la ayuda de los resortes y los pilares logré este objetivo: los resortes se ubicaron en las cuatro esquinas de la tapa superior de la baldosa, anclados mediante pilares impresos en 3D. Gracias a su forma, similar a un trompo, estos pilares permiten el movimiento controlado de la tapa. De esta manera, cuando se pisa la baldosa, los piezoeléctricos se comprimen, y al liberar la presión, los resortes devuelven la tapa hacia arriba, mientras la parte superior de los pilares actúa como tope para evitar que se desplace más de lo necesario.

- Victor Raul Borncano: Distribui y pegue los topes de caucho a la base de madera, y pegar los piezoelectricos arriba de los topes. Calculo de tamaño y colocacion de muelles para evitar que los resortes se desacomoden.

---

## 📅 4️⃣ Semana (Lunes 22 - Viernes 26)

-  Mauricio Blasco: Coloque los topes de goma en los piezoeléctricos ya soldados, también me contacte con Autogomas Para recibir como ayuda una alfombra antideslizante, la cual fui a retirar y posteriormente la medimos, lijamos y recortamos para colocarla sobre la baldosa. Por ultimo diseñe el banner del proyecto, el cual enviamos. También me encargue principalmente de diseñar el esquemático y pcb de la placa rectificadora, la cual imprimimos, planchamos, pusimos en acido, lijamos y agujereamos.

-  Santiago Tejeda: Esta semana me encargué específicamente del armado de los piezoeléctricos en la baldosa, ubicándolos junto a unas tarimas de caucho que habían sobrado. Además, realicé el pegado de los mismos a la estructura y su correspondiente cableado de forma prolija con silicona, para luego conectarlos en las borneras de la placa rectificadora, cual diseñé en la misma semana.

-  Victor Raul Broncano: Compre, corte y lije la placa de cobre para despues limpiar la placa, imprimi las conexiones del banco de capacitores. Despues plancahe y puse la placa en acido.

---

🧾 **Observaciones generales del mes:**  
-  
-

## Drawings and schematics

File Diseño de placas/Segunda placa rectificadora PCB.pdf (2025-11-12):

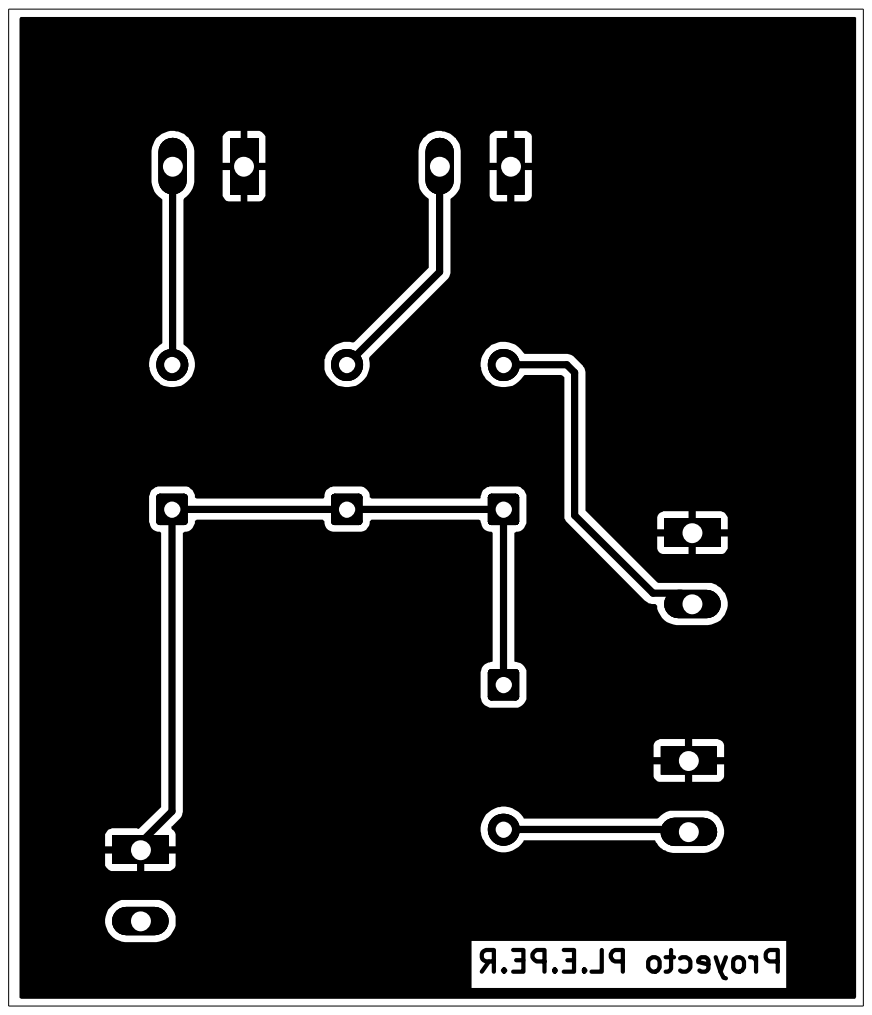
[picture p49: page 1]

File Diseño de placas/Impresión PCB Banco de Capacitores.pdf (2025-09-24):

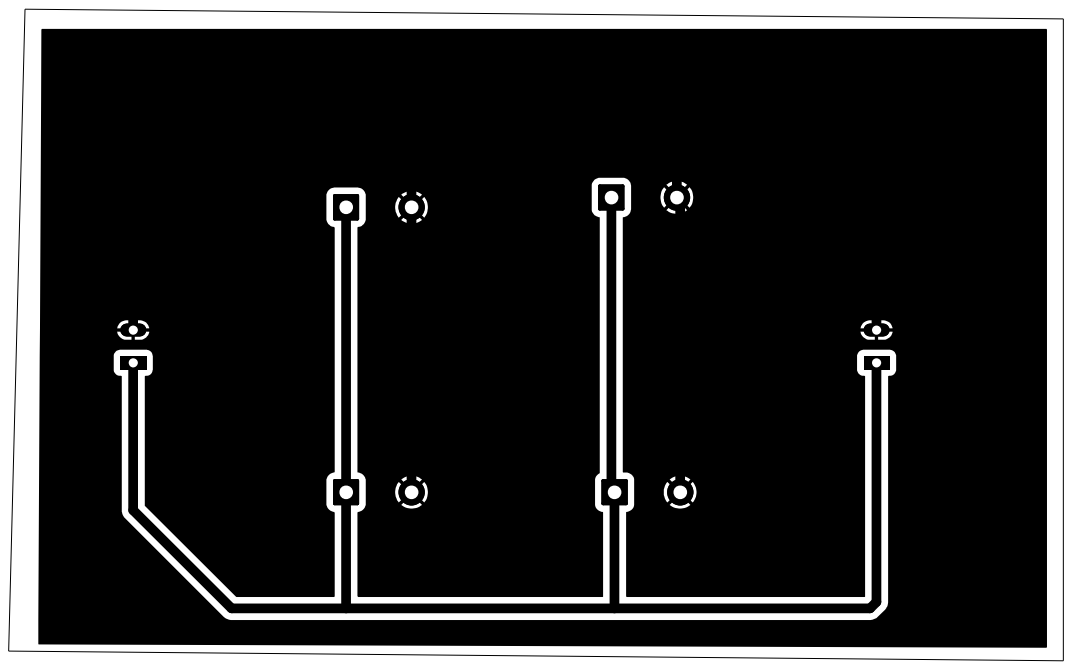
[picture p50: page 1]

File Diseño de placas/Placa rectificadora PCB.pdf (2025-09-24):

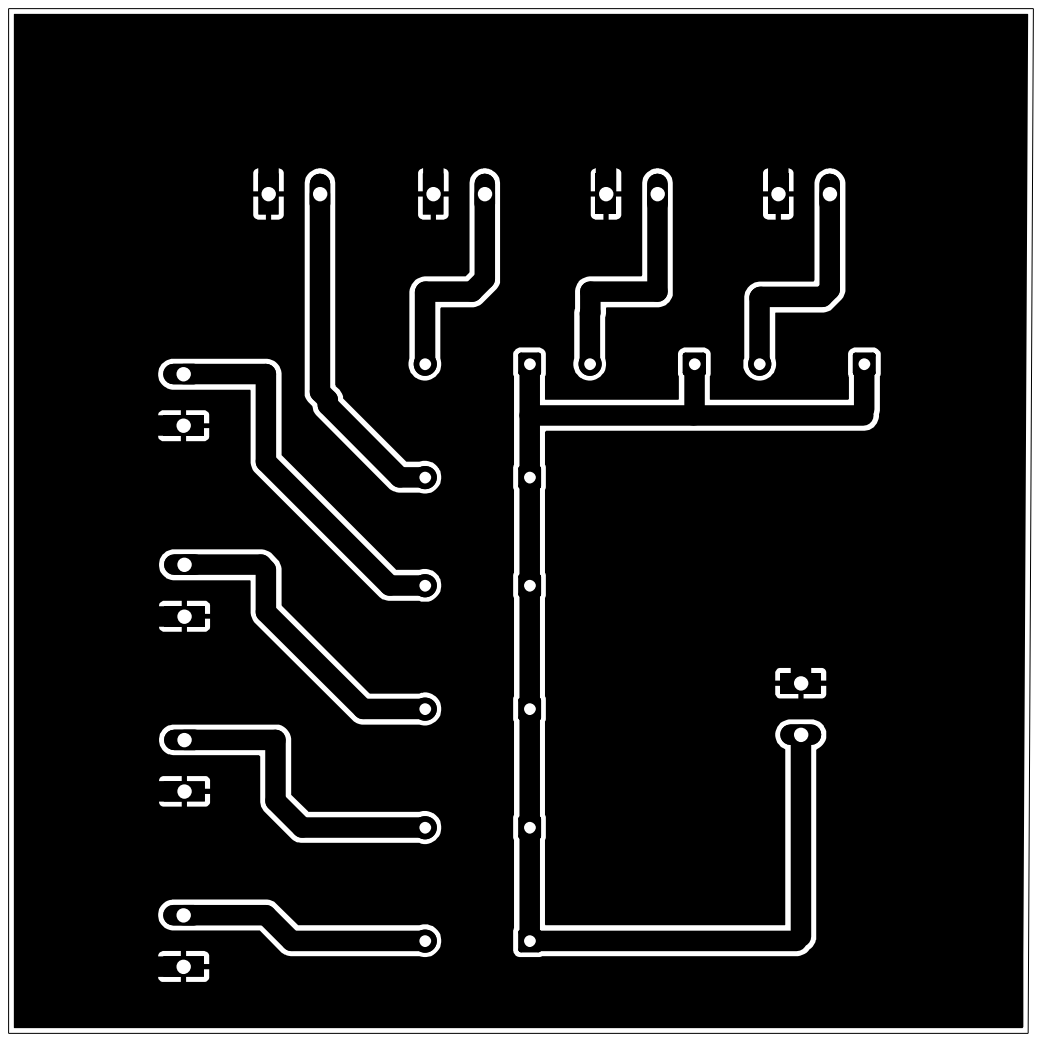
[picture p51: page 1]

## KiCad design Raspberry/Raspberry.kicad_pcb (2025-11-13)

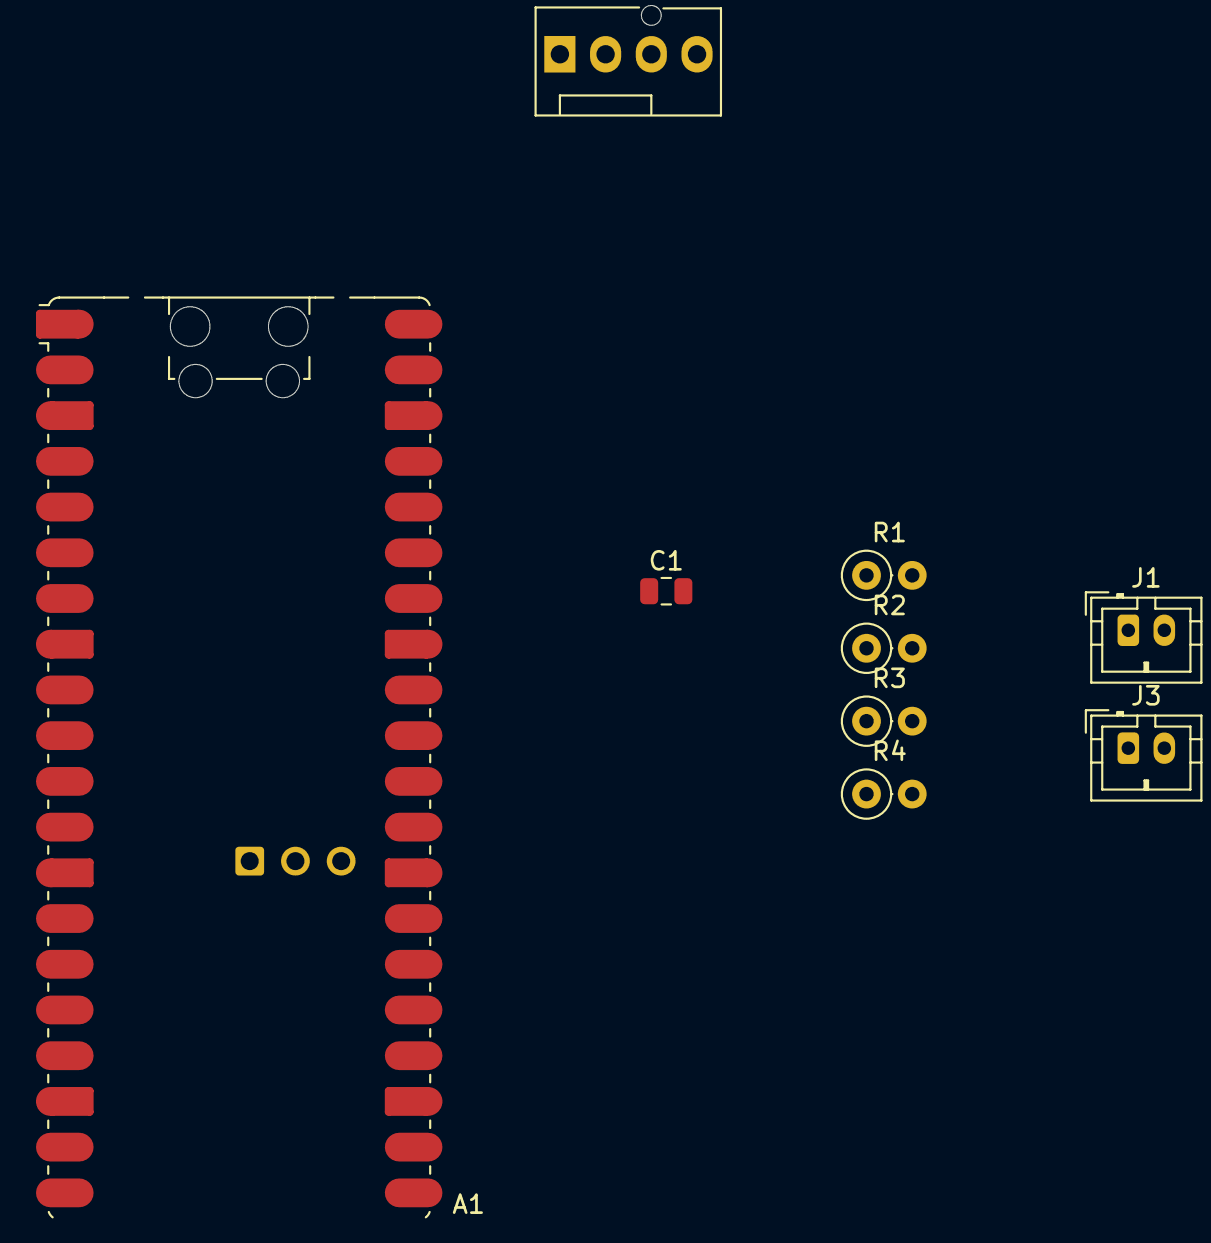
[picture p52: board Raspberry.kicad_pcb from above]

Board: 2 copper layers, 9 parts (0 on the bottom side), 8 nets.

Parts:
A1: RaspberryPi_Pico_W; RaspberryPi_Pico_W_SMD_HandSolder
C1: 100nF; C_0805_2012Metric
J1, J3: Conn_01x02_Pin; JST_PH_B2B-PH-K_1x02_P2.00mm_Vertical
J2: Conn_01x04; FanPinHeader_1x04_P2.54mm_Vertical
R1, R2, R4: 10K; R_Axial_DIN0207_L6.3mm_D2.5mm_P2.54mm_Vertical
R3: 30K; R_Axial_DIN0207_L6.3mm_D2.5mm_P2.54mm_Vertical

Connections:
+3.3V: C1.1, J2.3
ADC0: A1.31 (GPIO26_ADC0), R3.2, R4.1
ADC1: A1.32 (GPIO27_ADC1), R1.2, R2.1
Earth: A1.3 (GND), A1.8 (GND), A1.13 (GND), A1.18 (GND), A1.23 (GND), A1.28 (GND), A1.33 (AGND), A1.38 (GND), C1.2, J1.2, J2.4, J3.2, R2.2, R4.2
GP6: A1.9 (GPIO6), J2.2
GP7: A1.10 (GPIO7), J2.1
J1: J1.1, R1.1
J3: J3.1, R3.1

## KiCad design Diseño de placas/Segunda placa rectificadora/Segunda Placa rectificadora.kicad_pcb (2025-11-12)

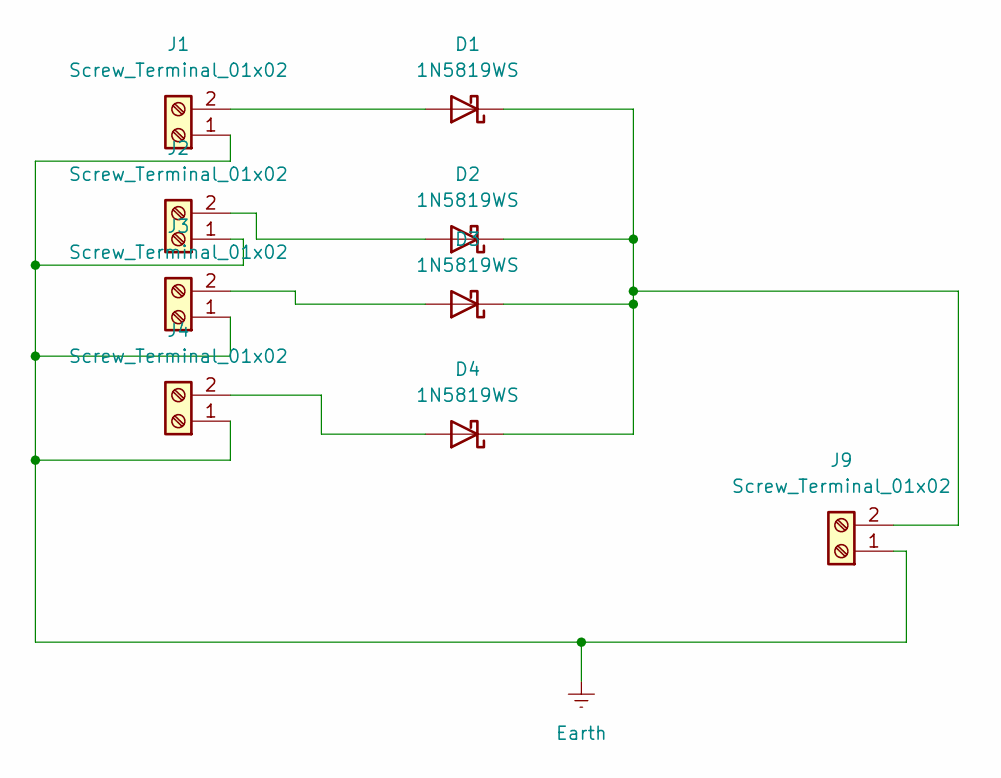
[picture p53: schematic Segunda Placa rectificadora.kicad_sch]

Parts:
D1, D2, D3, D4: 1N5819WS; D_DO-41_SOD81_P10.16mm_Horizontal
J1, J2, J3, J4, J9: Screw_Terminal_01x02; TerminalBlock_Altech_AK300-2_P5.00mm

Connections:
Earth: J1.1, J2.1, J3.1, J4.1, J9.1
unnamed: D1.2 (A), J1.2
unnamed: D1.1 (K), D2.1 (K), D3.1 (K), D4.1 (K), J9.2
unnamed: D2.2 (A), J2.2
unnamed: D3.2 (A), J3.2
unnamed: D4.2 (A), J4.2

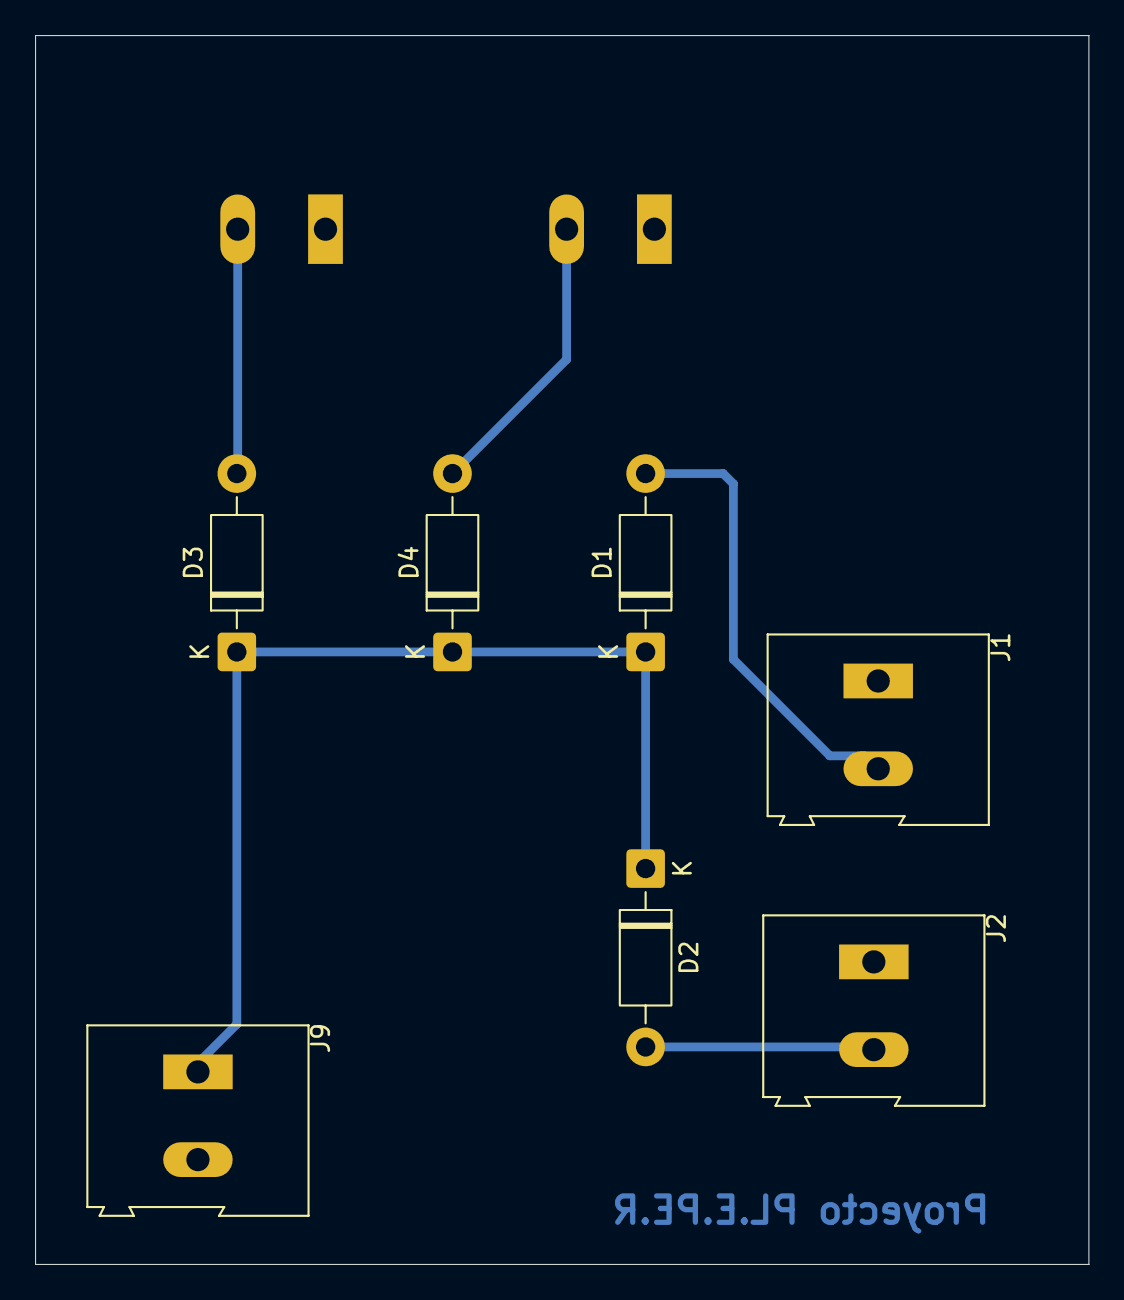
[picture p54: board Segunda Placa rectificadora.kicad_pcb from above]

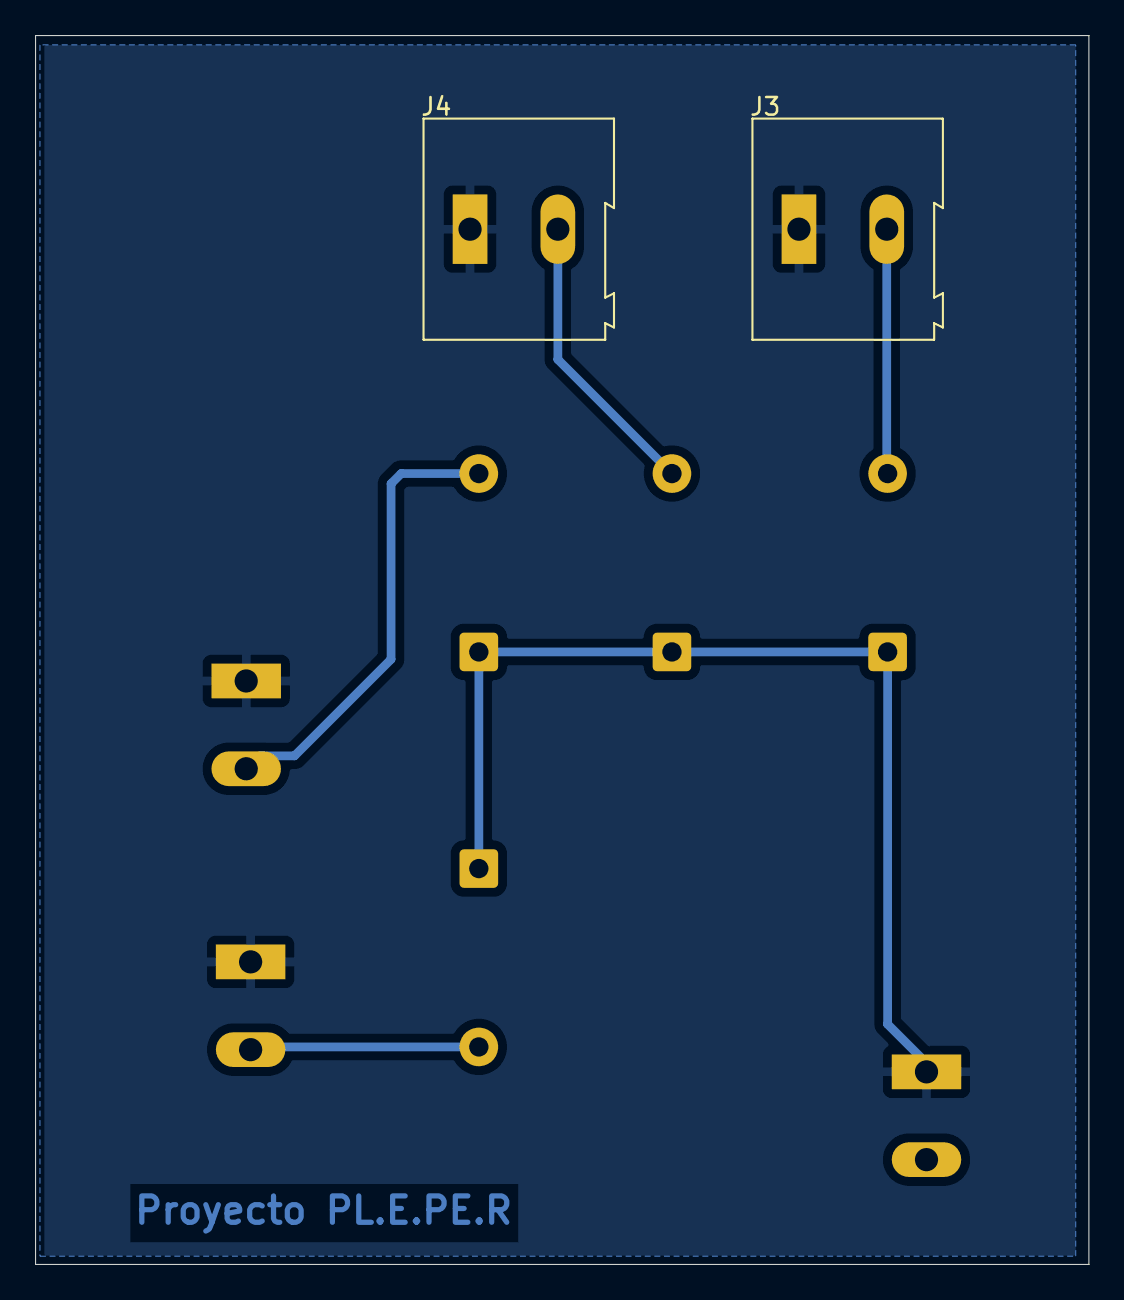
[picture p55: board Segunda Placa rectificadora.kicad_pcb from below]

Board: 2 copper layers, 60.0 x 70.0 mm, 9 parts (2 on the bottom side), 6 nets.

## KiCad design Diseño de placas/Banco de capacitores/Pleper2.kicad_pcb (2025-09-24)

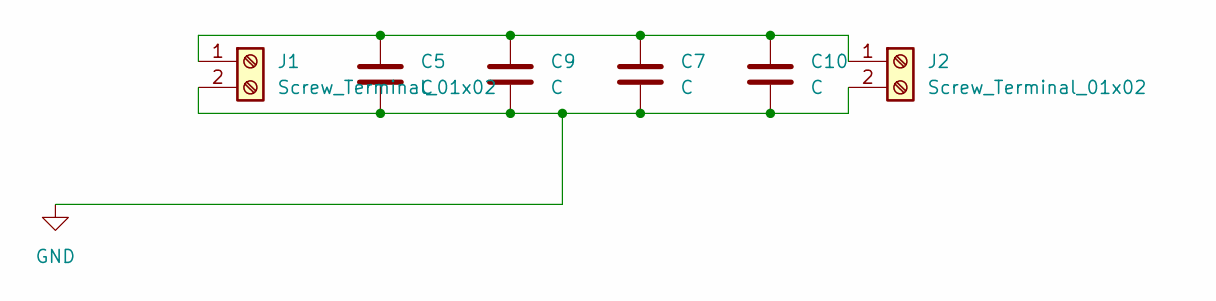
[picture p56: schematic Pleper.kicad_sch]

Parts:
C5, C7, C9, C10: C; CP_Radial_D30.0mm_P10.00mm_SnapIn
J1, J2: Screw_Terminal_01x02; TerminalBlock_Altech_AK300-2_P5.00mm

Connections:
GND: C5.2, C7.2, C9.2, C10.2, J1.2, J2.2
unnamed: C5.1, C7.1, C9.1, C10.1, J1.1, J2.1

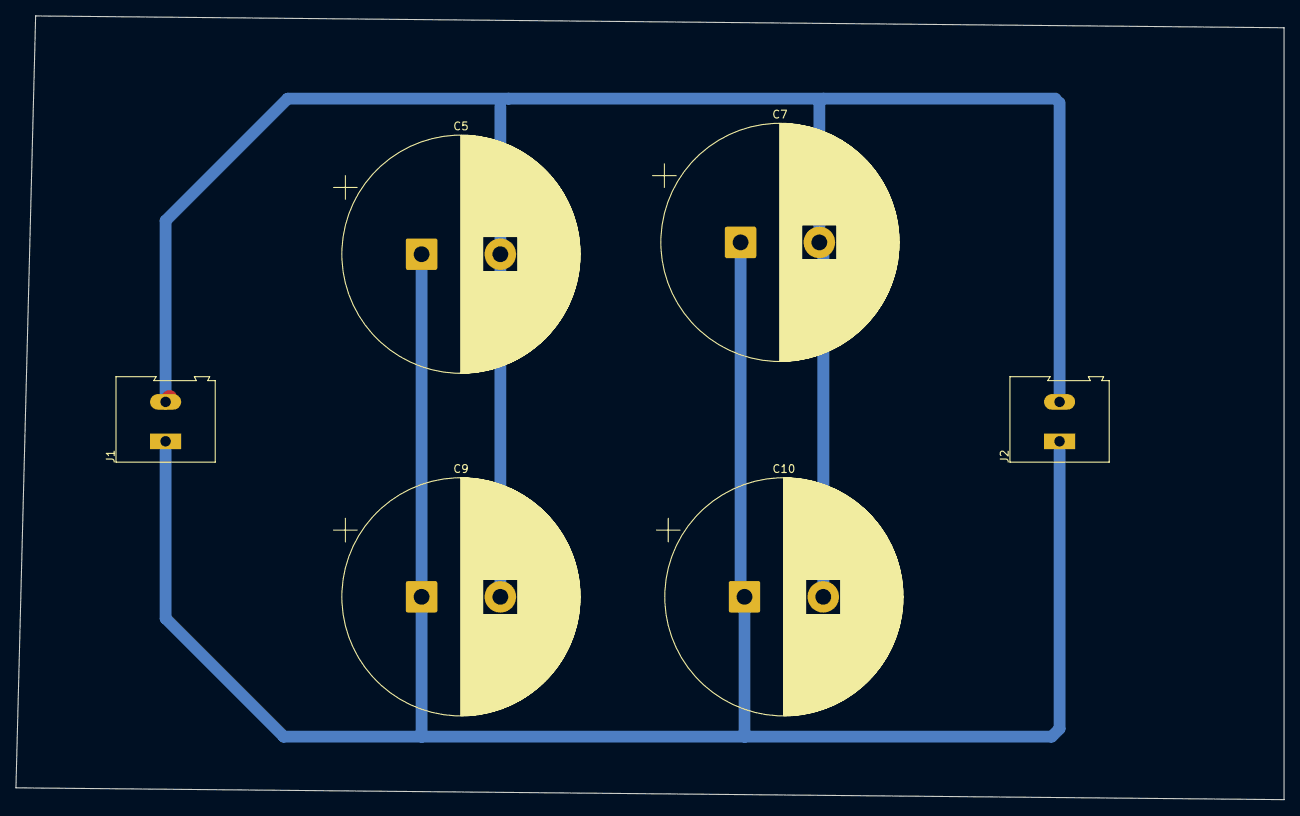
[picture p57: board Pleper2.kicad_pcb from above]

Board: 2 copper layers, 161.0 x 99.5 mm, 6 parts (0 on the bottom side), 2 nets.

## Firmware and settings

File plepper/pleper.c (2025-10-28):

#include "hardware/gpio.h"
#include "hardware/i2c.h"
#include "hardware/adc.h"
#include "lcd.h"
#include <stdio.h>

#define GPIO_SDA 6
#define GPIO_SCL 7
#define ADC_PIN 26 // GPIO26 es ADC0

// Constantes para la conversión ADC
#define ADC_MAX_VAL 4095.0f 
#define VREF 3.3f           

// **IMPORTANTE**: Define aquí el voltaje máximo del capacitor. 
#define V_CAP_MAX 13.2f 

int main(void) {
    // Inicialización I2C para el LCD
    i2c_init(i2c1, 100000UL);
    gpio_set_function(GPIO_SDA, GPIO_FUNC_I2C);
    gpio_set_function(GPIO_SCL, GPIO_FUNC_I2C);
    gpio_pull_up(GPIO_SDA);
    gpio_pull_up(GPIO_SCL);
    lcd_init(i2c1, 0x27);

    // Inicialización del ADC
    adc_init();
    adc_gpio_init(ADC_PIN); 
    adc_select_input(0); 
    
// ... (Tus includes, defines y la parte inicial de main() ) ...

    char buffer[16];
    
while (true) {
    uint16_t raw_value = adc_read();
    float voltage = ((float)raw_value / ADC_MAX_VAL) * VREF;
    int porcentaje = (int)((voltage / V_CAP_MAX) * 100.0f);

    if (porcentaje < 0) porcentaje = 0;
    if (porcentaje > 100) porcentaje = 100;

    lcd_clear();

    lcd_set_cursor(0, 0);
    lcd_string("CARGA CAPACITOR");

    lcd_set_cursor(1, 0);
    lcd_char('[');

    int bloques = porcentaje / 10; // 10 bloques posibles

    for (int i = 0; i < 10; i++) {
        if (i < bloques)
            lcd_char(0); // lleno
        else
            lcd_char(1); // vacío
    }

    lcd_char(']');

    char buffer[6];
    snprintf(buffer, sizeof(buffer), " %d%%", porcentaje);
    lcd_string(buffer);

    sleep_ms(250);
 }

}

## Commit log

2025-03-31 Update README.md
    Borrador de la presentación, falta terminar
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2025-04-07 🕜🎛️ Updated with Glitch
2025-04-07 Revert "🕜🎛️ Updated with Glitch"
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2025-08-07 Creo carpeta de Imágenes y subo las primeras
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2025-09-24 Pisada epica en el prototipo de la placa
2025-09-24 Añado archivo pdf del pcb del banco de capacitores
2025-09-24 Añado archivo de Kicad Placa rectificadora
    [pleper turip ip ip.kicad_pcb, pleper turip ip ip.kicad_sch]
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2025-09-26 Subo vista del diseño 3D de la placa rectificadora
2025-09-26 Subo archivo stl del banco de capacitores
    [Pleper Banco de Capacitores.stl]
2025-09-26 Subo vista del diseño 3D del banco de capacitores
2025-10-08 Add files via upload
    Subir foto del boceto de la placas
2025-10-08 Add files via upload
    dibujo muuuy boceto de la rectificadora en.... paint.
2025-10-08 Lo moví a su respectiva carpeta
    en la carpeta de la placa
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2025-10-17 Reubico Estructura AutoCAD/placa pleper prototipo.dwg
    [placa pleper prototipo.dwg]
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2025-10-17 Creo carpeta de canva
    [Dibujo1.stl]
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2025-10-17 Creo Archivos de AutoCad
    [Topes pleper .dwg]
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2025-10-17 Canva de prototipo uno de topes
    [Tope_Pleper.stl]
2025-10-17 Primer Prototipo AutoCad
    [Pleper primer prototipo.dwg]
2025-10-17 Segundo Prototipo Pleper
    [Pleper segundo prototipo.dwg]
2025-10-17 Primer Prototipo de tope para la placa
    [PilarPleper.stl]
2025-10-17 Medición de grupo de con un tope en cada esquina
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2025-10-17 Creo la carpeta banco de capacitores correctamente
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2025-10-22 Adjunto el Banner del proyecto en formato JPG
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2025-10-23 corregi dias de la semana 1 de octubre
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2025-10-23 corrigo los dias del mes de octurbe para que coincidan
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2025-10-23 Agregué mi avance de la semana 3 de octubre
2025-10-23 Agregué mi avance de "Semana 1 y 2 de Octubre"
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2025-10-23 Subo el banner actualizado con la imagen circular
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2025-10-24 subo mi avance de la semana 1 septiembre
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2025-10-27 Arreglo los nombres en la bitacora
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2025-10-28 codigo de pleper
    commit de .vscode en el codigo de pleper
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2025-10-28 Creo manual de Usuario y actualizo carpeta técnica
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2025-10-28 Actualizar bitácora de octubre con avances del proyecto
    Se actualizó la bitácora de octubre con detalles sobre el progreso de los integrantes del proyecto, incluyendo investigaciones sobre circuitos, mediciones de pulsos y avances en el código.
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2025-10-28 Actualizo y creo la carpeta del video de presentación
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2025-10-29 edit pagina web
    mejora en la seccion de sponsors
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2025-10-29 KiCad del cicuito
    [Bombeo por bombeo capacitivo.kicad_pcb, Bombeo por bombeo capacitivo.kicad_sch]
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2025-10-29 Corrección
    [Bombeo por bombeo capacitivo.kicad_pcb, Bombeo por bombeo capacitivo.kicad_sch]
2025-10-29 KiCad del Circuito
    [Bombeo por bombeo capacitivo.kicad_pcb, Bombeo por bombeo capacitivo.kicad_sch]
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2025-10-29 eliminacion de la carpeta de imagenes
    para poder agregar una carpeta de imagenes mas completa
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2025-10-29 estados unidos y japon (historia de la piezoelectricidad)
    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
2025-10-29 Corrijo nombres de carpeta de diseño 3D
    [PilarPleper.stl, Pleper primer prototipo.dwg, Pleper segundo prototipo.dwg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]
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2025-10-29 Prototipo del cicuito de carga por bombeo de capacitores
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2025-10-29 Creo readme en la carpeta de Docs del Proyecto
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2025-10-29 Correccion 1era semana de agosto
    Updated project log for September with detailed contributions from team members.
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2025-10-29 2da semana de septiembre
    Added detailed progress notes for the project structure and design considerations over multiple weeks.
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2025-10-29 4ta semana de septiembre
    Added details about Victor Raul Broncano's tasks related to the copper plate and capacitor bank connections.
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2025-10-29 2da semana de octubre
    Added updates from team members regarding project progress and challenges faced during the week.
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2025-10-29 4ta semana de octubre
    Added updates from team members regarding project progress, including measurements, component purchases, and coding challenges.
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2025-10-30 Semana del 18 al 22
    Added information about spring measurements and contact with Resortecnica for assistance.
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2025-10-30 Subo diseño final de la baldosa
    [Diseño final baldosa.dwg]
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2025-10-31 Actualizo modelos 3D
    [Diseño final baldosa.dwg, Diseño final baldosa.stl]
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2025-11-05 Subo diseños de placa
    [Placa rectificadora.kicad_pcb, Placa rectificadora.kicad_sch, Segunda Placa rectificadora.kicad_pcb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]
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2025-11-06 Actualización logo
    [Segunda Placa rectificadora.kicad_pcb]
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2025-11-06 Subi el DWG del Pilar
    [Pilar Proyecto.dwg, Pilar ProyectoV3.stl]
2025-11-06 Subo Circulo de Tope Resorte
    [Circulo Pleper.dwg, Circulo Pleper.stl]
2025-11-06 Subo STL del Pilar/Circulo
    [Circulo Pleper.stl, Pilar ProyectoV3.stl]
2025-11-08 Actualizo otra vez carpeta técnica
    (ayuda mañana rindo el parcial de la unlp)
2025-11-08 Modifico algunas cositas
    [Segunda Placa rectificadora.kicad_sch]
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2025-11-10 Saque la placa que no se terminó haciendo
    [Bombeo por bombeo capacitivo.kicad_pcb, Bombeo por bombeo capacitivo.kicad_sch]
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2025-11-12 subo autocad de la carcasa de la placa rectificadora
    [Carcasini.dwg]
2025-11-12 Subo el STL de la carcasa de la placa rectificadora
    [Carcasa_si.stl]
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2025-11-12 Actualizo readme para que coincida con los últimos arreglos
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
